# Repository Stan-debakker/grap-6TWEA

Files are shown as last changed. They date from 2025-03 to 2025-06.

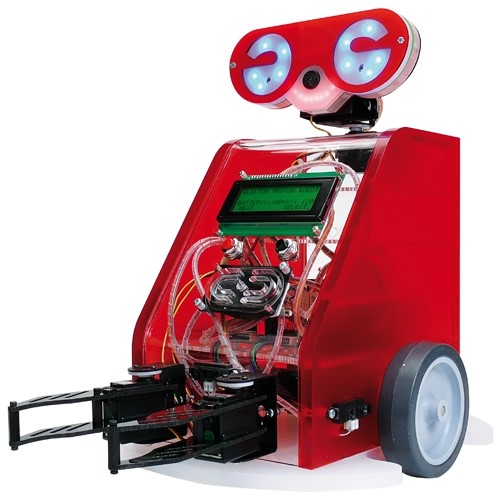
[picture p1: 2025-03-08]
school/foto robot/image1.jpeg

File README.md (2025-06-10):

# GRAP-6TWEA

## Doel
Het doel van dit project was om de verouderde **Elector Proton Robot** te moderniseren.  
Dit heb ik gedaan door het originele PCB (Printed Circuit Board) te vervangen. De nieuwe schema’s zijn te vinden in **"schematics"**.

Daarnaast moest ik ervoor zorgen dat de nieuwe sensoren correct werken.  
Ik ben gestart met experimenteren via Arduino IDE, zie **"code_arduinoIDE"**.

Op basis van deze experimenten heb ik een bibliotheek ontwikkeld om het gebruik te vereenvoudigen:

- **Versie 1** – **"liberary/robot"**: Voor Arduino, met de originele componenten aangesloten.
- **Versie 2** – **"liberary/robot_ESP_addon"**: Voor de ESP32-C6 met de bijbehorende uitbreiding.

## Schoolgerelateerde onderdelen
Omdat dit project deel uitmaakt van een schooltaak, heb ik ook bijbehorende documenten moeten aanmaken, zoals studies en presentaties.  
Deze zijn te vinden onder **"school"**.

Voor een ander vak moest ik een website maken, die grotendeels over dit project gaat. Er staat ook nog extra info over een ander project wat ik vorig jaar deet Asgard.
Je vindt de websitebestanden onder **"website"**.

## Extra experimenten
Tot slot heb ik geëxperimenteerd met communicatie tussen de ESP32 en een computer via Python.  
Door beperkingen op mijn schoollaptop lukte dit niet, en heb ik deze testen stopgezet. De bestanden vind je onder **"python"**.

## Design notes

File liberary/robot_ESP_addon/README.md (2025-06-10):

# robot
deze bibliotheek is voor de geüpgrade elector proton robot
## info
de pcb die ik gebruikt om te upgraden staan in 
[github](https://github.com/Stan-debakker/grap-6TWEA)

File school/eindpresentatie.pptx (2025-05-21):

## Graadsproef: oude robot modernizeren

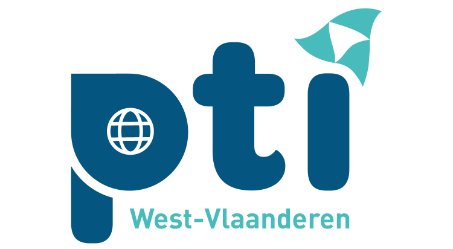
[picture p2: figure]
Afbeelding met Graphics, grafische vormgeving, Lettertype, logo Door AI gegenereerde inhoud is mogelijk onjuist.

Stan Debakker 6TWEA

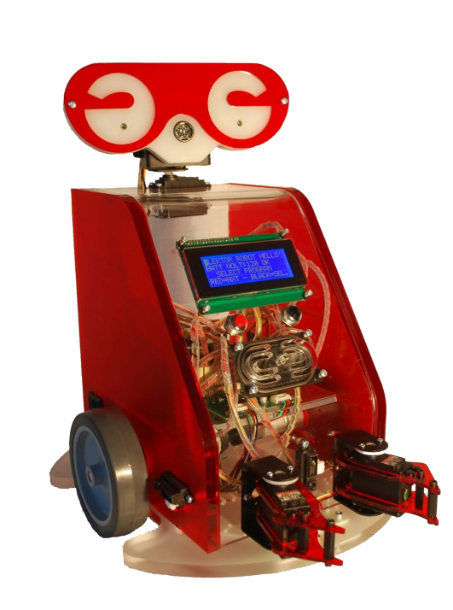
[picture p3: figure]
Afbeelding met machine, speelgoed, rood, automaat Door AI gegenereerde inhoud is mogelijk onjuist.

## Voorstelling van de robot

- Type: proton robot
- Productiedatum: 2011
- Producent: Elektor

## Onderdelen

Onderdelen die nog goed zijn, en behouden kunnen worden:
- LCD scherm
- IR afstandssensor
- Knoppen
- Motoren
- Ultrasone sensor
- Servomotoren

## onderdelen

Onderdelen die verouderd zijn, en daarom interessant om te vernieuwen:
- Lijnsensor (1→13 Chanels)(3→8 sensoren)
- (RGB) leds → adresseerbare RGB leds
- Microcontroller → microprocessor
- Muziekkaart
- DC-DC converters

## Microcontroler upgrade

- ESP32-C6
  - Wifi 6, BLE 5
- Extra
  - 3-as magnetometer
  - 3-as gyroscoop
  - 3-as accelerometer

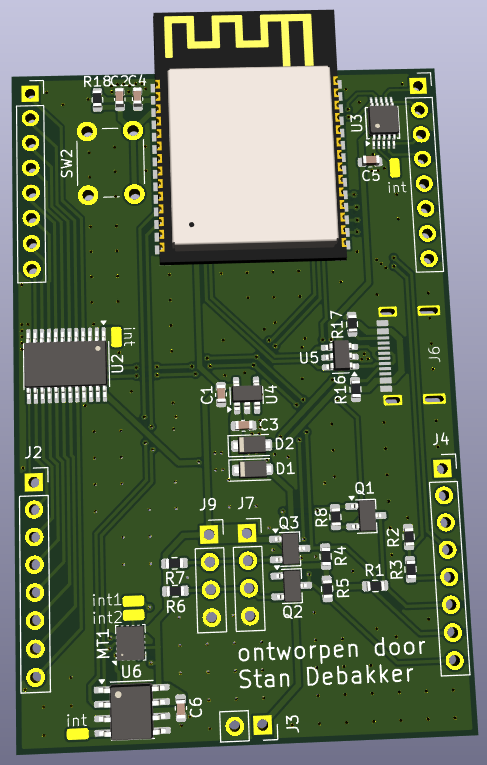
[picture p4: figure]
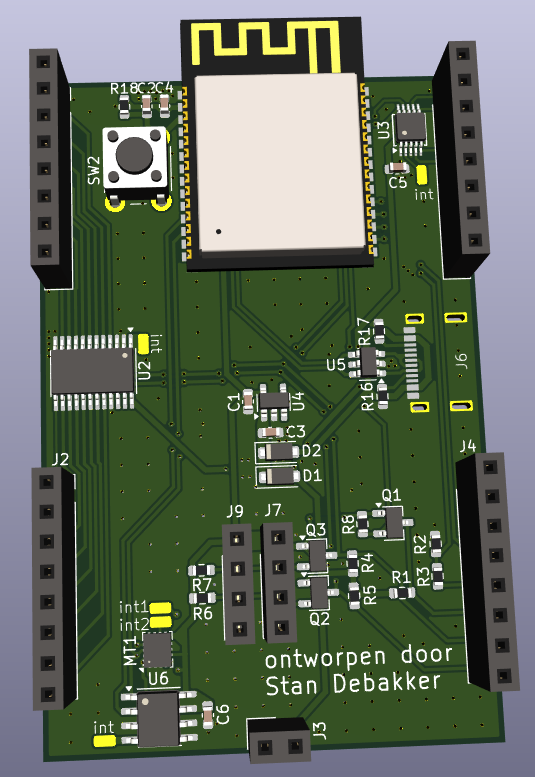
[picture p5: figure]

## Lijnsensor upgrade

- Van 1 naar 13 meetbare lichtbanden
- Van 3 naar 8 sensoren

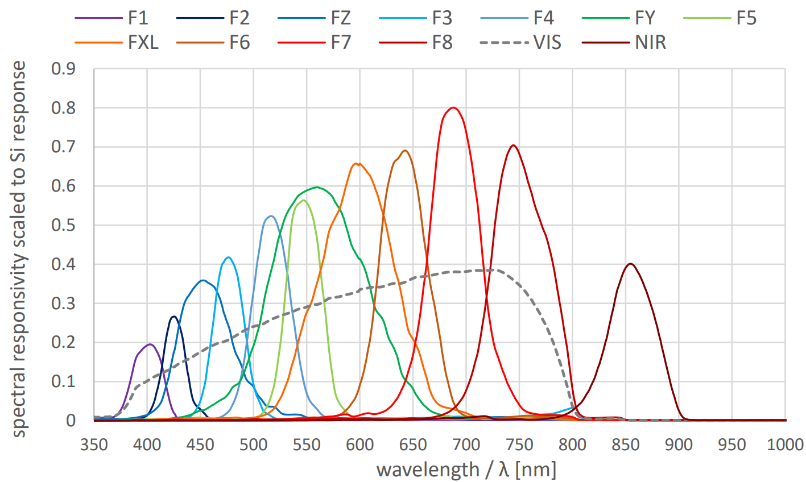
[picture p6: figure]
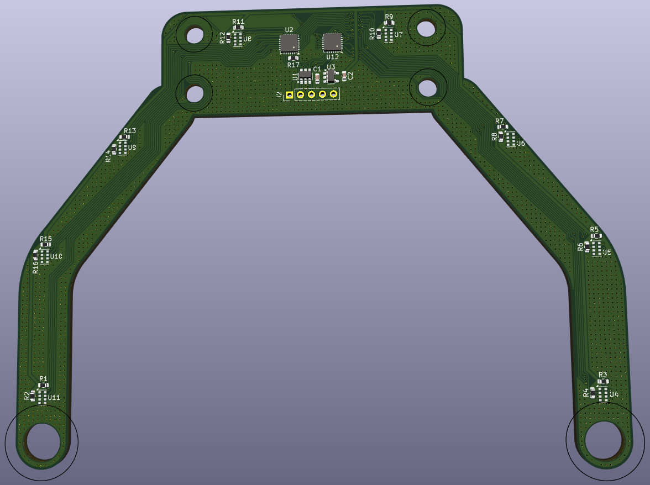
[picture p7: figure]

## hoofd

- Van 2 RGB led zones en 8 rode leds naar 18 RGB leds (onafhankelijk)
- Lichtsensor van 8 bit naar 12 bit (dynamisch bereik)

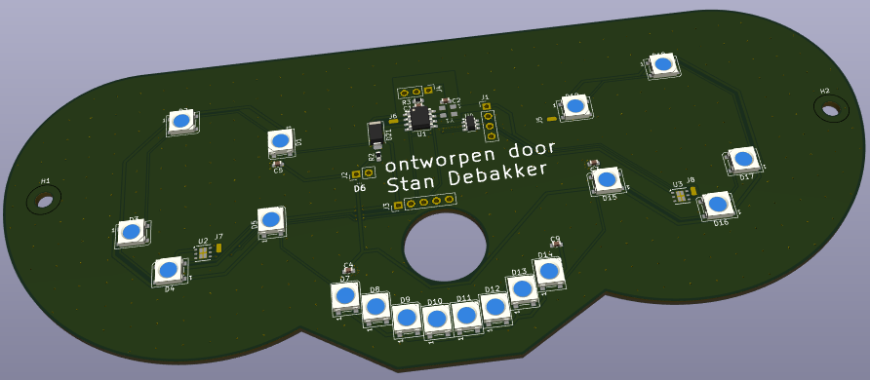
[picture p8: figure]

## methode

- Kicad
- Zelf aangeleerd

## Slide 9

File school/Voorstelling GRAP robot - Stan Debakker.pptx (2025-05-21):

## Programmeren van een robot, met een microcontroller

Graadproef
Stan Debakker
6 Technologische Wetenschappen en Engineering

## Elektor Proton Robot

- LCD-scherm
- 2 drukknoppen
- Grote wielen, aangestuurd door 2 DC-motoren
- Hoofd, bestuurd door 2 servomotoren
- 8 LED’s en een luidspreker
- Afstandssensoren
- Lichtsensoren
- Handjes, bestuurd door servomotoren

Grap Stan Debakker

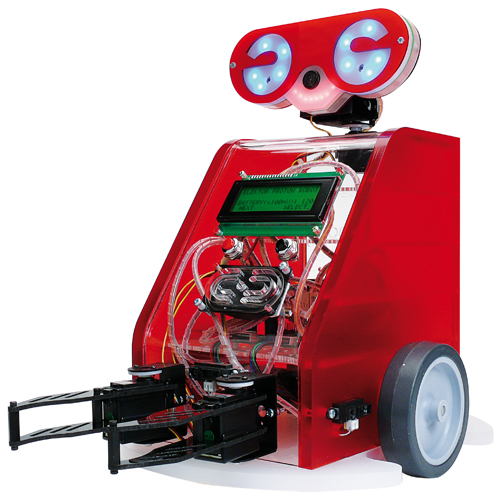
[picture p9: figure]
Elektor Proton Robot: a versatile platform for learning and experimenting | Elektor Magazine

## Besturing robot

- PIC16F887
- 8bit CMOS microcontroller
- 40-pin

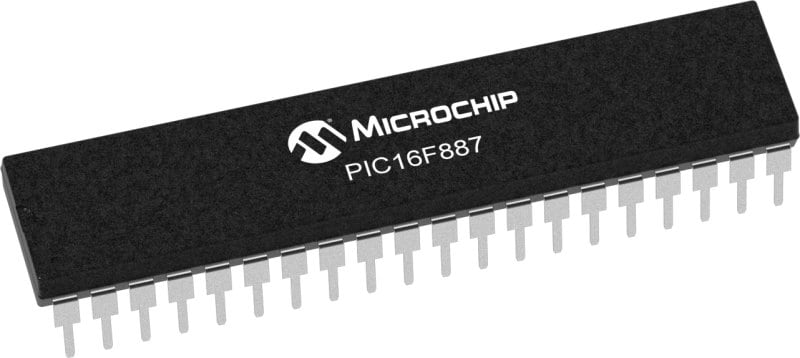
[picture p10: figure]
PIC16F887 | Microchip Technology
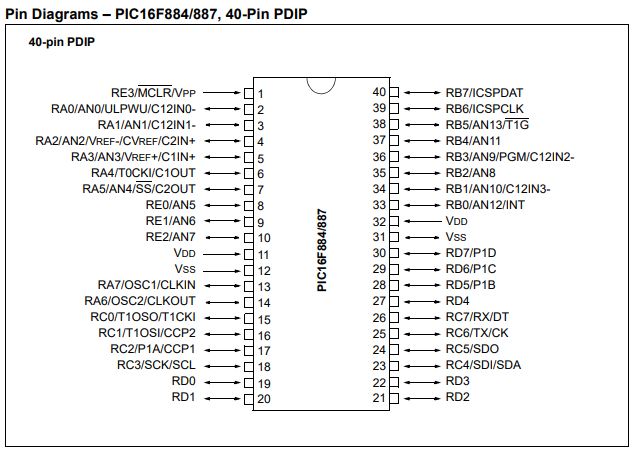
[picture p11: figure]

## Programmeertaal

- Nog te bestuderen wat mogelijk is, afhankelijk van de processor
  - C
  - C++
  - Flow code
  - …

## Doel

- Leren werken met een microcontroller
- Opstarten van de robot:
  - Laten rijden
  - Motoren aansturen
  - Aansturen LCD-scherm
- Indien nog tijd:
  - Uitwerken van een labo-oefening
  - Moderniseren

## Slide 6

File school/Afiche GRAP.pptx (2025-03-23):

## OUDE ROBOT MODERNISEREN

Stan Debakker – 6 TWEa

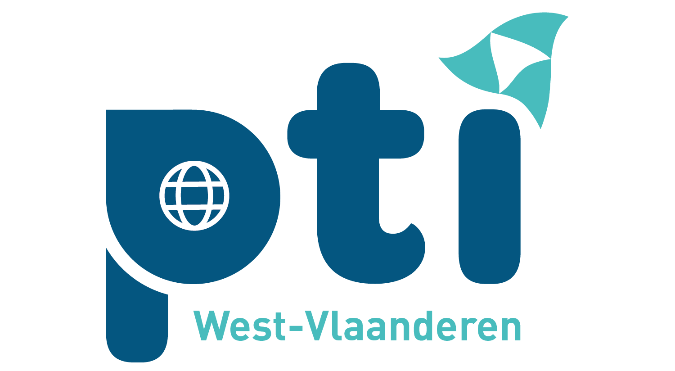
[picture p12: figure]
Afbeelding met Graphics, grafische vormgeving, Lettertype, logo Door AI gegenereerde inhoud is mogelijk onjuist.
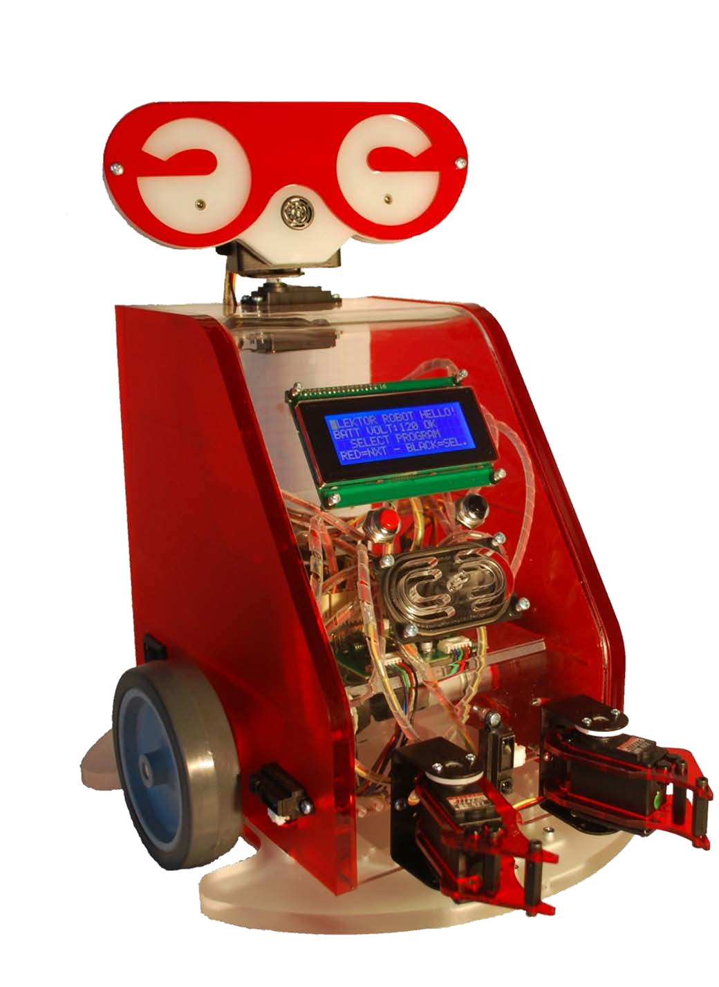
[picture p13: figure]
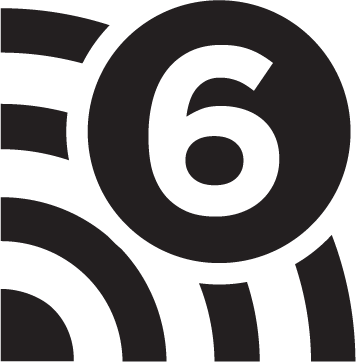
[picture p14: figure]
Afbeelding met cirkel, Graphics, zwart, schermopname Door AI gegenereerde inhoud is mogelijk onjuist.
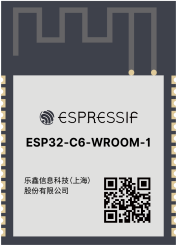
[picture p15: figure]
Afbeelding met tekst, schermopname, Rechthoek, Lettertype Door AI gegenereerde inhoud is mogelijk onjuist.
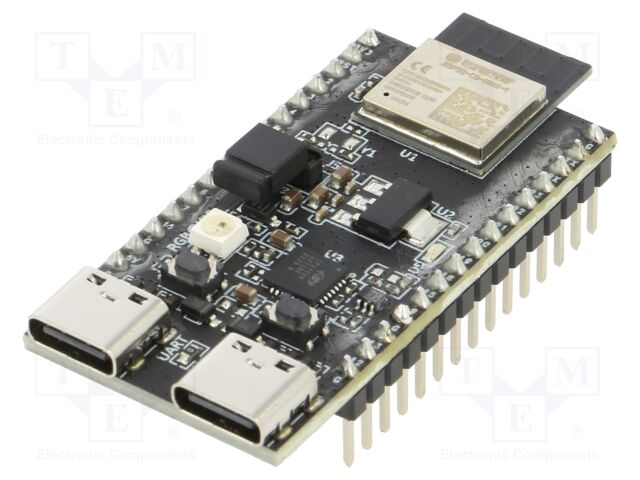
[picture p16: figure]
ESP32-C6-DEVKITM-1-N4 ESPRESSIF - Conjunto de arra: IoT | Comp: ESP32-C6-MINI-1-N4; 3,3VDC,5VDC; ESP32C6-DEVKITM1N4 | TME - Elektroniikka komponentit México

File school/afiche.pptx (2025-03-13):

## OUDE ROBOT MODERNIZEREN

Afbeelding met Graphics, grafische vormgeving, Lettertype, logo Door AI gegenereerde inhoud is mogelijk onjuist.

Stan Debakker – 6TWEA

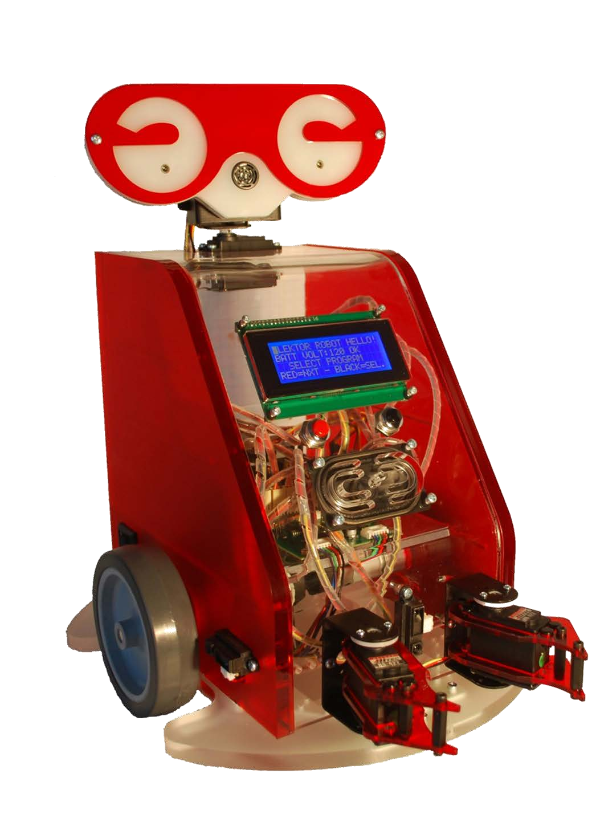
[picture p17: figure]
Afbeelding met cirkel, Graphics, zwart, schermopname Door AI gegenereerde inhoud is mogelijk onjuist.
Afbeelding met tekst, schermopname, Rechthoek, Lettertype Door AI gegenereerde inhoud is mogelijk onjuist.
ESP32-C6-DEVKITM-1-N4 ESPRESSIF - Conjunto de arra: IoT | Comp: ESP32-C6-MINI-1-N4; 3,3VDC,5VDC; ESP32C6-DEVKITM1N4 | TME - Elektroniikka komponentit México
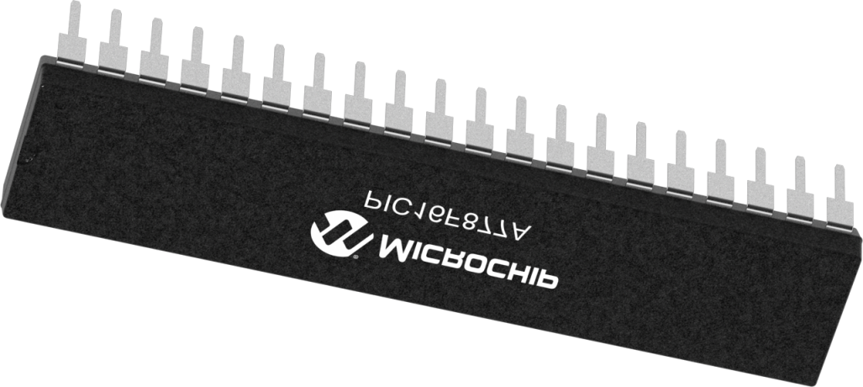
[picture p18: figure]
PIC16F877A-E/P

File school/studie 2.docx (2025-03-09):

GRAP: Modernisering robot

Studie 2


# 1 Inleiding

In de afgelopen decennia heeft de technologie een enorme vooruitgang geboekt, waarbij robots steeds slimmer, sneller en veelzijdiger zijn geworden. Veel oude robotmodellen die ooit baanbrekend waren, zijn inmiddels verouderd en niet meer in staat om te voldoen aan de eisen van moderne toepassingen.

Het moderniseren van een oude robot kan echter een interessante uitdaging bieden: het combineren van klassieke robottechnologie met de nieuwste innovaties.

In deze graadproef zal ik onderzoeken hoe een verouderde robot, zoals de Elektor Proton Robot, kan worden geüpdatet met hedendaagse technologieën, zoals geavanceerde sensoren, nieuwe besturingssystemen en verbeterde software. Door deze modernisering kan de robot zijn functionaliteit, efficiëntie en prestaties aanzienlijk verbeteren.

In studie 1 ben ik de bestaande onderdelen, mogelijkheden en de werking van de robot nagegaan. In deze studie 2 bekijk ik de opties om te moderniseren.

# 2 Upgrade van de robot

In dit hoofdstuk gaan we na wat de mogelijkheden zijn om de robot te verbeteren of te moderniseren. Dit doen we door ieder bord afzonderlijk te bekijken. Sommige borden doen alles goed, zoals de motoren, LCD-scherm. De servodriver werkt ook goed en wordt ook niet bekeken. Andere zoals de ADD-On, lijnsensoren, hoofdbord-muziekkaart bekijken we afzonderlijk.

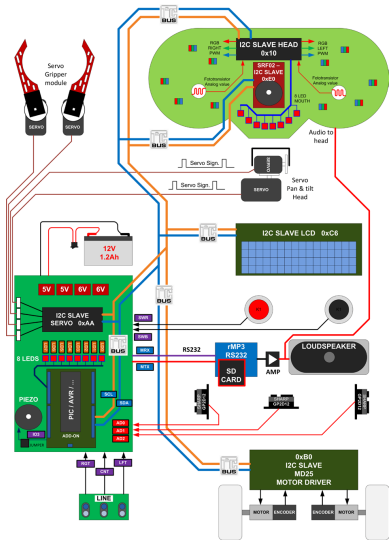
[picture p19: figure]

figuur: blokschema Elektor Proton Robot

## 2.1 ADD-ON

Hier gaan we dieper in op de onderdelen van de ADD-On kaart en welke verbeteringen, modernisering en toevoegingen er mogelijk zijn. Hiermee zorgen we voor een betere connectiviteit en maken we de robot toegankelijker voor toekomstige toepassingen.

### 2.1.1 Keuzes microcontroller

De microcontroller in de Elektor Proton Robot (en in veel andere robots) is het "brein" van de robot. Het regelt het besturen van de robot en verwerkt de gegevens van de sensoren. De microcontroller is een kleine computer die taken uitvoert in elektronische systemen. Het bestaat uit een processor, geheugen en invoer-/uitvoerapparaten om met de buitenwereld te communiceren.

Bij het moderniseren van de robot speelt de microcontroller een belangrijke rol. Hij bestuurt de oude hardware en maakt nieuwe functies mogelijk. Dankzij moderne microcontrollers kunnen zelfs eenvoudige robots slimmer en efficiënter worden door gebruik te maken van sensoren, motoren en communicatietechnologieën voor geavanceerdere toepassingen.

Bord | Voltage | I0 pins | ADC | | DAC | PWM | UART | I²C | I²S | SPI | Wifi | Bluetooth | Thread /zigbee
| | | Pins | Rezolutie
Arduino Giga | 5V | 76 | 12 | 10 | 2 | 12 | 4 | 3 | | 2
Arduino Mega | 5V | 54 | 16 | 10 | | 15 | 4 | 1 | | 1
Arduino Uno | 5V | 14 | 6 | 10 | | 6 | 1 | 1 | | 1
ESP32 C3 | 3.3V | 15 | 6 | 12 | | | 2 | 1 | 1 | 3 | 150Mbps | v5.0
ESP32 C5 | 3.3V | 22 | 6 | 12 | | | 3 | 2 | 1 | 1 | 150Mbps | v5.0 | ja
ESP32 C6 | 3.3V | 23 | 7 | 12 | | | 2+1 | 1+1 | | 1 | 150Mbps | v5.3 | ja
ESP32 C61 | 3.3V | 18 | 4 | 12 | | | 3 | 1 | 1 | 1 | 150Mbps | v5.0
ESP32 H2 | 3.3V | 19 | 5 | 12 | | | 2 | 2 | 1 | 3 | | v5.3 | ja
ESP32 mini1 | 3.3V | 28 | 18 | 12 | | | 3 | 2 | 2 | 4 | 150Mbps | v4.2
ESP32 pico mini | 3.3V | 27 | 18 | 12 | | | 3 | 2 | 2 | 4 | 150Mbps | v4.2
ESP32 pico v3 | 3.3V | 0 | 18 | 12 | | | 3 | 2 | 2 | 4 | 150Mbps | v4.2
ESP32 S2 | 3.3V | 37 | 20 | 12 | | | 2 | 2 | 1 | 4 | 150Mbps
ESP32 S3 | 3.3V | 36 | 20 | 12 | | | 3 | 2 | 2 | 4 | 150Mbps | v5.0
ESP32 WROOM 32E | 3.3V | 26 | 18 | 12 | | | 3 | 2 | 2 | 4 | 150Mbps | v4.2
ESP32 WROVER E | 3.3V | 24 | 18 | 12 | | | 3 | 2 | 2 | 4 | 150Mbps | v4.2
ESP8684 MINI 1 | 3.3V | 14 | 6 | 12 | | | 2 | 1 | | 3 | 72Mbps | v5.3
ESP8684 WROOM | 3.3V | 15 | 6 | 12 | | | 2 | 1 | 1 | 3 | 150Mbps | v5.0
Attiny | 5V | 4-28 | 0-28 | 10 | | | 0-1 | 0-1 | | 0-1

Tabel: vergelijking opties microcontrollers die met ArduinoIDE werken

Uit de tabel blijkt dat de ESP’s handig zijn, want ze hebben allemaal (behalve H2) wifi waardoor we kunnen communiceren en updaten via ArduinoOTA en IOT-Cloud.

Voor mijn project heb ik als microcontroller gekozen voor de ESP32-C6, aangezien deze microcontroller de meeste functionaliteiten biedt.

De ESP32-C5 en de ESP32-C6 hebben betere wifi (wifi 6), in vergelijking met de ESP32-S3 die maar wifi 4 heeft.

Een nadeel van de ESP32-C6 is echter dat deze minder extra I/O-pinnen heeft in vergelijking met de ESP32-S3 en de afwezigheid van ondersteuning voor I²S en CAN (TWAI), welke wel aanwezig zijn in de ESP32-C5 en ESP32-S3.

De rekenkracht van de ESP32-C6 is minder dan die van de ESP32-S3 wan niet erg is behalve als we beeldherkenning en AI willen gebruiken.

Helaas is de ESP32-C5 niet in productie gegaan, wat de keuze voor de ESP32-C6 noodzakelijk maakte. Een ander belangrijk aspect is dat de ESP32-C6, net als andere modellen uit de ESP32-serie, werkt op 3.3V in plaats van de gebruikelijke 5V die veel andere microcontrollers ondersteunen. Dit vormt een extra uitdaging, aangezien de robot waarvoor deze controller bedoeld is, oorspronkelijk was ontworpen voor 5V. Dit zorgt voor een aanpassing van zowel de power, databussen, analoge en digitale signalen.

#### 2.1.1.1 Power (ESP32)

Zoals in punt 2.1.1 aangehaald, heeft de ESP32-C6 dus een 3.3V voeding nodig. Ik heb gekozen voor TLV75733PDBVR. Deze is heel goedkoop (€0,275 per stuk) en kan ook max 1A aan. Dit is meer dan genoeg voor de ESP32 en mogelijks extra.

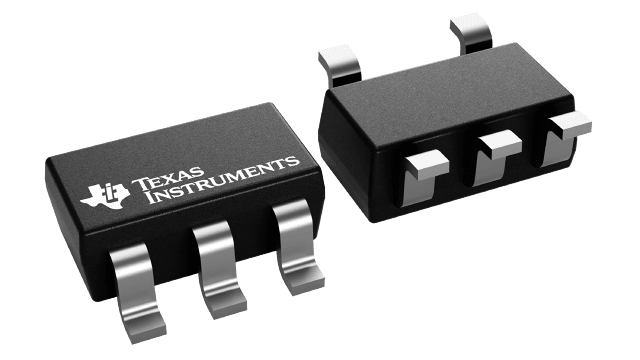
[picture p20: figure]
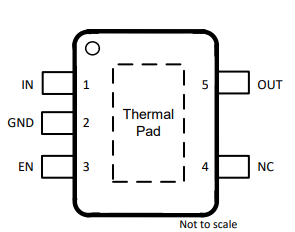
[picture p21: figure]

#### 2.1.1.2 Databussen

##### 2.1.1.2.1 Voltageomvormer voor I²C

Voor het correct functioneren van een I²C-communicatie tussen componenten met verschillende spanningsniveaus, is het noodzakelijk om een bidirectionele voltageomvormer te gebruiken. Deze omvormer zorgt ervoor dat de signalen tussen apparaten met verschillende spanningslogica (bijvoorbeeld 5V en 3,3V) probleemloos kunnen worden uitgewisseld.

Een bidirectionele voltageomvormer is relatief eenvoudig te realiseren. Voor elke datalijn zijn slechts twee weerstanden en een MOSFET nodig. Aangezien het I²C-protocol doorgaans gebruikmaakt van twee datalijnen, namelijk SCL (kloklijn) en SDA (datalijn), zijn er voor een volledige implementatie in totaal vier weerstanden en twee MOSFET's vereist. Sommige implementaties maken gebruik van een extra lijn, zoals een INT-lijn (interrupt), maar in dit project wordt deze niet gebruikt.

Hieronder leg ik kort de werking van een bidirectionele voltageomvormer uit:

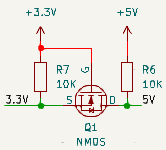
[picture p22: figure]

- De MOSFET fungeert als een schakelaar en zorgt ervoor dat signalen veilig kunnen worden overgebracht tussen de spanningsniveaus.
- De weerstanden stellen de juiste pull-up-waarden in, die essentieel zijn voor de werking van de I²C-bus.

Dit type schakeling is dus niet alleen kosteneffectief, maar ook praktisch en betrouwbaar voor het waarborgen van de compatibiliteit tussen apparaten met verschillende spanningslogica.

##### 2.1.1.2.2 UART-verbinding voor de muziekkaart

De robot beschikt ook over een UART (Universal Asynchronous Receiver-Transmitter) verbinding, die wordt gebruikt om te communiceren met de muziekkaart. Een UART-verbinding maakt gebruik van twee datalijnen:

- TX (transmit): om data te verzenden.
- RX (receive): om data te ontvangen.

Bij deze toepassing is het belangrijk om rekening te houden met de verschillende spanningsniveaus van de aangesloten componenten, namelijk 5V en 3,3V.

Hieronder leg ik de uni-directionele spanningsaanpassing voor de UART-datalijnen uit:

1. Datalijn RX van 5V naar 3,3V: Voor deze lijn is een eenvoudige spanningsdeler voldoende. Dit wordt gerealiseerd met twee weerstanden, waarbij één weerstand ongeveer het dubbele is van de andere. Door deze verhouding wordt de spanning op de lijn verlaagd naar een veilig niveau van 3,3V, zodat de muziekkaart correct kan functioneren zonder schade te veroorzaken.
2. Datalijn TX van 3,3V naar 5V: In theorie kan deze datalijn zonder enige spanningsomvorming worden gebruikt. De meeste 5V-componenten interpreteren een 3,3V-signaal correct als "hoog" (logische 1). Toch is het aan te raden om hier dezelfde spanningsomvormer te gebruiken als voor de I²C-datalijnen (want de uni directionele variant is complexer). Dit verhoogt de betrouwbaarheid van de verbinding en voorkomt mogelijke problemen bij compatibiliteit.

Door consequent dezelfde bidirectionele spanningsomvormer te gebruiken, zoals die bij de I²C-datalijnen, worden alle verbindingen uniform en betrouwbaar uitgevoerd. Dit draagt bij aan de stabiliteit en functionaliteit van het systeem.

#### 2.1.1.3 ADC (Analog to Digital Converter)

Bij het verwerken van analoge signalen zijn er twee belangrijke methoden om spanningsomzetting en signaalverwerking te realiseren. Beide methoden hebben hun voor- en nadelen, afhankelijk van de toepassing en de gewenste precisie.

##### 2.1.1.3.1 Spanningsverdeler

Een spanningsverdeler is een eenvoudige en goedkope oplossing voor het omzetten van hogere spanningen (bijvoorbeeld 5V) naar lagere spanningen (bijvoorbeeld 3,3V). Dit wordt gerealiseerd met behulp van twee weerstanden.

Voordelen:

- Eenvoudig te implementeren en kosteneffectief.
- Geschikt voor situaties waarin hoge nauwkeurigheid niet essentieel is.

Nadelen:

- Kleine vervormingen in het analoge signaal: door de eigenschappen van de spanningsverdeler kunnen er kleine afwijkingen in het signaal optreden, wat kan leiden tot onnauwkeurige metingen.
- Herkalibratie nodig: omdat de vervormingen variabel kunnen zijn, is het regelmatig nodig om de sensoren opnieuw te kalibreren.

Deze methode is de aanpak die wordt gebruikt voor de 5V naar 3.3V, maar in het geval van analoge signalen is de betrouwbaarheid lager door de gevoeligheid voor ruis en vervorming.

##### 2.1.1.3.2 Externe ADC

Een betere oplossing voor het verwerken van analoge signalen is het gebruik van een externe ADC (Analog-to-Digital Converter). Dit is een specifiek apparaat dat analoge signalen omzet naar digitale waarden met hoge precisie.

Voor dit project heb ik gekozen voor de ADS1115-Q1, een externe ADC met de volgende eigenschappen:

- 4 kanalen: hierdoor kunnen meerdere analoge signalen tegelijkertijd worden verwerkt.
- 16-bit resolutie: dit biedt een veel hogere precisie dan de ingebouwde ADC van de ESP32-C6, die slechts 12-bit is.
- Compatibiliteit met 5V: in tegenstelling tot de ADC van de ESP32-C6, kan de ADS1115 direct omgaan met analoge signalen van 5V zonder dat een spanningsverdeler nodig is.

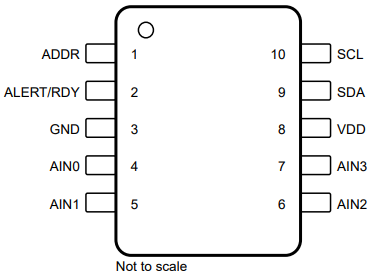
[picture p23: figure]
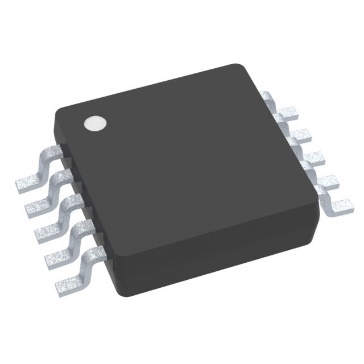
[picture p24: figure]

- Betrouwbaarheid: externe ADC's zoals de ADS1115 zijn minder gevoelig voor ruis en vervormingen, waardoor de meetresultaten consistenter zijn.
- Eenvoudige integratie: de ADS1115 communiceert via het I²C-protocol, waardoor het gemakkelijk te verbinden is met microcontrollers zoals de ESP32-C6.

#### 2.1.1.4 GPIO (General Purpose Input Output)

Vanwege het lagere voltage van de ESP32-C6 (3,3V) is het raadzaam om een externe module te gebruiken die compatibel is met hogere spanningen, zoals 5V. Dit voorkomt compatibiliteitsproblemen en zorgt voor een betere signaalintegriteit. Voor dit project is gekozen voor de PI4IOE5V6416, een krachtige I/O-uitbreidingsmodule.

De PI4IOE5V6416 biedt een scala aan functionaliteiten die ideaal zijn voor dit project. Hieronder volgen de belangrijkste eigenschappen:

##### 2.1.1.4.1 16 bestuurbare pinnen

De module biedt 16 GPIO-pinnen (General Purpose Input/Output) die afzonderlijk kunnen worden aangestuurd. Dit maakt het mogelijk om meerdere componenten en apparaten aan te sluiten, zoals sensoren, LED’s of andere externe modules.

##### 2.1.1.4.2 Ondersteuning voor Pull-Up/Pull-Down weerstanden

De module heeft ingebouwde ondersteuning voor pull-up en pull-down weerstanden. Dit betekent dat de gebruiker de toestand van de pinnen nauwkeurig kan instellen:

- Pull-up: zorgt ervoor dat een pin standaard naar een hoge spanning (bijvoorbeeld 5V) wordt getrokken.
- Pull-down: zorgt ervoor dat een pin standaard naar een lage spanning (bijvoorbeeld 0V) wordt getrokken.

Dit maakt het gemakkelijker om stabiele digitale signalen te verkrijgen zonder extra externe weerstanden toe te voegen.

##### 2.1.1.4.3 Ondersteuning voor interrupts

De PI4IOE5V6416 biedt de mogelijkheid om interrupts uit te sturen. Dit betekent dat de module een signaal naar de ESP32-C6 kan sturen wanneer een specifieke gebeurtenis plaatsvindt, zoals:

- Een verandering in de toestand van een pin (bijvoorbeeld een drukknop die wordt ingedrukt).
- Een signaal dat wordt ontvangen van een aangesloten apparaat.

Interrupts zijn belangrijk omdat ze de microcontroller in staat stellen om efficiënt te reageren op gebeurtenissen zonder constant elke pin te hoeven controleren (polling). Dit bespaart rekenkracht en verbetert de prestaties.

##### 2.1.1.4.4 Compatibiliteit met 5V

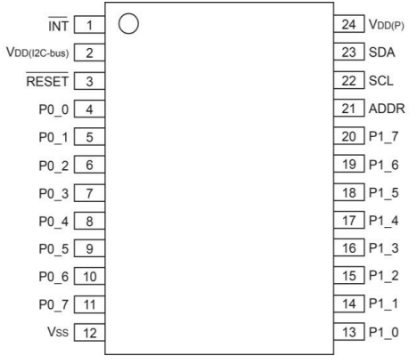
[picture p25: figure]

Een van de belangrijkste voordelen van de PI4IOE5V6416 is de compatibiliteit met een werkspanning van 5V. Hierdoor kan de module rechtstreeks worden gebruikt in systemen die een hogere spanning vereisen, zonder extra spanningsomzetting of aanpassingen.


### 2.1.2 Extra mogelijkheden voor localisatiebepaling.

In dit onderdeel onderzoek ik de mogelijkheid om de plaats van de robot te bepalen. We bekijken eerst hoe we de localisatie bepalen t.o.v. een startpunt met behulp van extra sensoren. Daarnaast bekijken we wat er mogelijk is met Wifi en GPS modules.

#### 2.1.2.1 Localisatiebepaling met behulp van extra sensoren

##### 2.1.2.1.1 Alles in één sensor

In eerste instantie onderzocht ik de BNO085. Dit is een sensor voor locatiebepaling, die een breed scala aan functies biedt, maar ook een relatief hoge prijs heeft (€10,99 voor één exemplaar, of €10,49 per stuk bij aankoop van 10 stuks). De BNO085 sensor beschikt over de volgende belangrijke componenten:

- Een 3-assige accelerometer
- Een 3-assig gyroscoop
- Een 3-assige magnetometer

##### 2.1.2.1.2 Alternatief

Gezien de relatief hoge prijs zocht ik naar alternatieven voor de BNO085 die samen minstens hetzelfde kunnen voor een lagere prijs.

- De MC3479 is een 3-assige accelerometer. Dit is een interessante keuze, met een prijs van €0,903 per stuk (€0,735 per stuk bij een aankoop van 10 stuks). Deze sensor heeft een resolutie van 16 bit en biedt verschillende maximale g-instellingen (±2, ±4, ±8, ±12, ±16) [m/(s^2)] .
- De ICM-42670 is een 3-assige accelerometer, 3-assig gyroscoop. Voor €2,77 per stuk (€2,30 per stuk bij een aankoop van 10 stuks). De ICM-42670 biedt een resolutie van 16 bit voor zowel de accelerometer als de gyroscoop. De accelerometer ondersteunt verschillende maximale g's (±2, ±4, ±8, ±16) [m/(s^2)] , terwijl de gyroscoop een resolutie van 16 bit heeft en verschillende dps (graden per seconde) instellingen biedt (±250, ±500, ±1000, ±2000) [(°)/s] .
- De MLC90395 is een 3-assige magnetometer. Met zijn I²C-ondersteuning en een prijs van €2,93 per stuk kan ook deze een interessante keuze zijn. De MLX90395 beschikt over een 16-bit magnetometer met een maximum van 130 mT in de Z-as en 55 mT (medium field variant) of 120 mT (high field variant) in het XY-vlak. Bovendien heeft de sensor een 16-bit voltmeter en een 14-bit thermometer, wat een extra functionaliteit biedt.

##### 2.1.2.1.3 Besluit sensoren localisatiebepaling

Ik heb gekozen voor de ICM-42670 en de MLX90395, aangezien deze sensoren meer functionaliteiten bieden dan de BNO085, tegen een lagere prijs. De ICM-42670 biedt zowel een accelerometer als een gyroscoop met een resolutie van 16 bit en meerdere g- en dps-instellingen, wat meer flexibiliteit biedt voor verschillende toepassingen. De MLX90395 voegt een 3-assige magnetometer toe met een hoge resolutie van 16 bit, samen met een voltmeter en thermometer. Dit maakt de combinatie van deze twee sensoren een voordelige keuze, aangezien ze meer functionaliteiten leveren en aanzienlijk goedkoper zijn dan de BNO085.

#### 2.1.2.2 Localisatiebepaling met wifi

De localisatiebepaling met behulp van Wifi is een mogelijkheid aangezien de ESP32 Wifi heeft. Dit kan in combinatie met de deep sleep functie van de ESP32 een interessante toevoeging zijn om de robot na een langere inactieve periode terug te vinden. Echter zijn hiervoor extra access points nodig. Gezien de onnauwkeurigheid en de nood om een netwerk op te stellen wordt dit niet verder bekeken. Indien dit in de toekomst toch nodig blijkt, kan dit makkelijk worden geïmplementeerd doordat de ESP32 wifi heeft.

#### 2.1.2.3 Localisatiebepaling met gps

Hiervoor moet er een extra gps module toegevoegd worden. De nauwkeurigheid is ook wel niet groot en de signalen worden makkelijk verstoord door gebouwen. Om deze redenen wordt dit niet verder bekeken.

## 2.2 Lijnsensoren

Momenteel heeft de lijnsensor een monocolor kleurherkenning. Hij kan enkel zwart en wit onderscheiden. Dit wil ik verbeteren door meerder kleuren te laten herkennen. Ook wil ik dan meerdere sensoren toevoegen waardoor complexere algoritmes mogelijk zijn.


### 2.2.1 Kleurherkenning mogelijk maken

Een andere mogelijke verbetering zou het vervangen van de lijnsensoren zijn door sensoren die meerdere kleuren kunnen onderscheiden. Dit zou de robot in staat stellen om complexere taken uit te voeren, zoals het volgen van een groene lijn gevolgd door een rode lijn.

Omdat er geen multicolor 5V lichtsensoren beschikbaar zijn, zijn voltageomvormers noodzakelijk. De AS734L lijkt de beste keuze voor dit doel, aangezien deze sensor een breed spectrum van licht kan meten, variërend van 405 nm (bijna onzichtbaar blauw) tot 855 nm (infrarood). Bovendien heeft de AS734L een werkspanning van slechts 1.8V, wat iets minder handig is, maar de voltageomvormers voor zowel de I²C-communicatie als de stroomvoorziening kunnen eenvoudig worden gedeeld door dezelfde reeks, namelijk de TLV75718PDYDR.

### 2.2.2 I²C multiplexen

Een belangrijk nadeel van bovenstaande is dat het vaak wenselijk is voor lijnsensoren om meerdere sensoren te gebruiken om een breder bereik te krijgen. De AS734L heeft echter slechts één sensor, wat betekent dat we multiplexing nodig hebben. Er zijn twee mogelijke opties voor I²C-multiplexers: de TCA9544 en de TCA9548. Het belangrijkste verschil is dat de TCA9544 vier I²C-lijnen kan splitsen, terwijl de TCA9548 acht I²C-lijnen kan splitsen. De TCA9544 ondersteunt bovendien de mogelijkheid om interruptus door te sturen, wat voor mijn toepassing minder relevant is (indrupt bij TLV75718PDYDR is niet handig). Daarom heb ik besloten de TCA9548 te gebruiken, aangezien deze acht I²C-lijnen kan splitsen.

Het voordeel van beide I²C-multiplexers is dat maximaal acht sensoren kunnen worden aangesloten door gebruik te maken van de adres bits A0, A1 en A2. Dit maakt de opstelling flexibel en uitbreid baar voor meerdere kleursensoren, wat de robuustheid van de robot aanzienlijk vergroot.

Als er nog tijd over is, zal ik de lijnsensoren verder uitwerken. Deze vernieuwing is leuk en heel handig, maar lijkt minder cruciaal.

## 2.3 Hoofd

Ook het hoofd van Proton robot kunnen we verbeteren met nieuwere componenten. Hieronder vind je alvast een opsomming van enkele ideeën.

### 2.3.1 LED’s

Ik overweeg om de huidige LED's in het hoofd van de robot te vervangen door adresseerbare LED's. Deze LED's hebben als groot voordeel dat ze individueel kunnen worden aangepast met slechts één enkele pin, in plaats van de drie PWM-pinnen per kleurgroep of één pin per LED-groep, waarbij elke groep altijd dezelfde staat heeft. Dit vereenvoudigt de hardware en biedt meer flexibiliteit in de bediening van de verlichting.

De meest voorkomende adresseerbare LED is de WS2812B, hoewel sommige vergelijkbare producten zelfs zeggen: "soortgelijk aan WS2812B". Deze LED's maken het mogelijk om elke LED in het hoofd afzonderlijk te besturen, wat verschillende visuele effecten en patronen mogelijk maakt. Dit kan bijvoorbeeld handig zijn voor het weergeven van statusindicatoren of om visuele feedback te geven in reactie op de omgeving of acties van de robot.

Door gebruik te maken van WS2812B LED's kunnen we de visuele presentatie van de robot aanzienlijk verbeteren, terwijl we tegelijkertijd de benodigde pinnen op de microcontroller verminderen (wat het ontwerp efficiënter maakt).

### 2.3.2 Lichtsenor

De huidige lichtsensor maakt gebruik van een 8-bit ADC (PIC in het hoofd), maar aangezien ik de LED's wil vervangen, zou het noodzakelijk zijn om een nieuwe PCB te maken. Dit maakt het aantrekkelijk om ook de lichtsensor te upgraden. De BH1750FVI lijkt een goede keuze, aangezien deze sensor een 16-bit nauwkeurigheid biedt en communiceert via I²C, wat de integratie vereenvoudigt. Echter, de BH1750FVI werkt alleen op 3.3V, wat een extra uitdaging vormt, aangezien de robot oorspronkelijk op 5V is ontworpen en de 3.3V nog niet tot aan het hoofd komt.

Er bestaan echter fotodiodes of fototransistors die wel op 5V kunnen werken, maar dit zou een extra ADC vereisen, evenals de nodige weerstanden en mogelijk een condensator. Dit zou het voordeel bieden dat er geen voltageomvorming nodig is, maar het zou wel extra componenten vereisen en de complexiteit van de schakeling verhogen.

Een andere optie is om de lichtsensor van de lijnsensoren te gebruiken. Dit kan echter leiden tot een conflict als de I²C-bus niet goed wordt geregeld, aangezien deze mogelijk wordt gedeeld met andere (door het enige adres van de sensor).

Als alternatief kunnen we overwegen om een microcontroller te gebruiken die beschikt over twee of drie onafhankelijke I²C-bussen, zoals beschreven in sectie 2.1.1, of nog andere microcontrollers te overwegen, maar dan kan de Arduino IDE niet gebruikt worden wat voor mij vervelend zou zijn. Dit zou de mogelijkheid bieden om meerdere I²C-apparaten tegelijk aan te sturen zonder conflicten, waardoor de integratie van meerdere sensoren, waaronder de nieuwe lichtsensor, eenvoudiger wordt. Deze aanpak kan de flexibiliteit van het ontwerp verhogen, maar vereist mogelijk een complexere implementatie van de software en hardware.

## 2.4 Camera

Een andere goede verbetering aan de robot zou kunnen zijn als die ook de functionaliteit krijgt om te zien. Er bestaat al een "ESP32-CAM" module die de OV2640 camera gebruikt, en het is zeker mogelijk om de ESP32-C6 te gebruiken om deze camera aan te sturen. De ESP32-C6 biedt genoeg kracht en connectiviteitsopties, wat het een geschikte keuze maakt voor algemene toepassingen.

Echter, als de robot taken moet uitvoeren die AI- of beeldverwerkingscapaciteiten vereisen, is de ESP32-S3 wellicht een betere keuze. De ESP32-S3 heeft namelijk verbeterde capaciteiten voor AI-toepassingen, en biedt betere prestaties voor beeldverwerkingstaken, waardoor het efficiënter kan omgaan met complexe berekeningen zoals gezichtsherkenning of objectdetectie.

Het kiezen van de juiste microcontroller hangt dus af van de specifieke vereisten van de robot, zoals de complexiteit van de beeldverwerking en AI-taken die uitgevoerd moeten worden.

## 2.5 Hoofdbord

Het hoofdbord is het centrale punt waar alle componenten op worden aangesloten of waar de signalen vandaan komen. Sommige onderdelen zijn inmiddels verouderd of zijn niet meer nodig door de ontwikkeling van nieuwe technologieën. Daarnaast zijn er verschillende aspecten die we kunnen verbeteren, zoals de volgende.

### 2.5.1 Power

Als ik het hoofdbord zou vervangen, zou ik overwegen om een efficiëntere DC-to-DC converter te gebruiken voor de belangrijkste (die het meeste stroom verbruiken) spanningen (12V en 5V). Het omzetten van 5V naar 3.3V met een LDO (Low Dropout Regulator) veroorzaakt relatief weinig verlies (het verlies in een LDO is de stroom maal het spanningsverschil tussen de invoer- en uitvoerspanning). Dit betekent dat als je begint met een 5V bron, het verlies bij het omzetten naar 3.3V minimaal is, wat de efficiëntie verbetert.

Echter, voor hogere stromen of wanneer de spanningsverschillen groter zijn, zou een DC-to-DC buck converter een betere keuze zijn. Buck converters kunnen veel efficiënter zijn bij grotere spanningsomzettingen (bijvoorbeeld van 12V naar 5V), aangezien ze de energie beter behouden in de vorm van hogere efficiëntie, vaak boven de 90%.

Samenvattend: als ik het hoofdbord zou vervangen, zou ik kiezen voor een combinatie van LDO-regelaars voor kleinere spanningsomzettingen (zoals 5V naar 3.3V want er is geen grote spanningsval en de stroom is ook lager beide verlagen het energieverlies) en DC-to-DC converters voor grotere omzettingen (zoals 12V naar 5V), om zo de efficiëntie en de energiebehoeften van de robot te optimaliseren.

### 2.5.2 Muziekkaart

Bij het vervangen van het hoofdbord ontstaat de mogelijkheid om een nieuwere muziekkaart te integreren. Dit biedt niet alleen verbeterde audiokwaliteit, maar ook de kans om gebruik te maken van geavanceerde communicatieprotocollen zoals I²S (Inter-IC Sound). Bijkomend, het communicatie protocol wordt simpeler in vergelijking met de huidige.

#### 2.5.2.1 Voordelen van I²S voor een muziekkaart

I²S is een speciaal protocol dat is ontworpen voor digitale audiocommunicatie. Het wordt vaak gebruikt in combinatie met moderne muziekkaarten en microcontrollers vanwege de efficiënte en nauwkeurige manier waarop het audiodata kan overbrengen.

1. Hoge geluidskwaliteit: I²S ondersteunt digitale audio-overdracht zonder de beperkingen van analoge signalen, zoals ruis en vervorming. Dit maakt het protocol ideaal voor hoogwaardige muziekkaarten.
2. Efficiëntie: Het protocol werkt met een eenvoudige set datalijnen, namelijk:
  - SD (Serial Data): voor het verzenden van audiogegevens.
  - WS (Word Select): om onderscheid te maken tussen het linker- en rechterkanaal (stereo).
  - SCK (Serial Clock): voor de timing van de gegevensoverdracht. Dit minimaliseert de complexiteit van de verbinding en maakt integratie eenvoudiger.
3. Flexibiliteit: Moderne muziekkaarten kunnen via I²S eenvoudig communiceren met microcontrollers zoals de ESP32 (behalve de ESP32-C6). Hierdoor is het mogelijk om audiogegevens efficiënt te verzenden en te verwerken.

#### 2.5.2.2 Integratie met ESP32

Als een ESP32 (bijvoorbeeld de ESP32-S3) wordt gebruikt, biedt dit extra mogelijkheden voor het beheer van de muziekkaart:

- ESP32 als audio-controller: de ESP32 kan audio naar de muziekkaart sturen via I²S, waarbij de microcontroller fungeert als een audio-bron (bijvoorbeeld muziekstreaming via Bluetooth of Wi-Fi).
- DSP-mogelijkheden (Digital Signal Processing): met behulp van de rekenkracht van de ESP32 kunnen audiobewerkingen plaatsvinden vóór de overdracht naar de muziekkaart, zoals het toepassen van equalizers of filters.

#### 2.5.2.3 Besluit

I²S is een logische keuze maar kan nu niet uitgewerkt worden omdat dit niet mogelijk is met de versie C6. Dit is de enige versie waar dit niet mogelijk is maar ik geef hier voorlopig nog de voorkeur aan omwille van de betere connectiviteit. Indien later een andere ESP32 gekozen wordt, bijvoorbeeld een versie S3 omwille van zijn grotere rekenkracht, is het te overwegen om dan de muziekkaart mee te integreren.

### 2.5.3 LED’S

De LED’s die zich op het hoofdbord bevinden, zijn niet geïntegreerd in het hoofd van de robot. Bij een mogelijke vervanging van het hoofdbord is het te overwegen om de debug LED’s aan te passen of zelfs volledig te verwijderen aangezien deze met de huidige tools minder relevant zijn. Er zijn verschillende opties die in aanmerking komen voor deze wijziging:

#### 2.5.3.1 Verwijderen of vervangen van huidige debug LED’s

Als het hoofdbord wordt vervangen, is het mogelijk om de huidige debug LED’s te verwijderen of te vervangen door LED’s die elders in het systeem zijn gebruikt, zoals die van LED’s (zie punt 2.3.1). Door een uniforme set LED’s te gebruiken, ontstaat een consistente uitstraling en functionaliteit in het gehele ontwerp.

Een voordeel van deze uniformiteit, is een vermindering van het aantal verschillende componenten, wat de onder houdbaarheid verbetert.

#### 2.5.3.2 Uitbreiden van indicator LED’s

De indicator LED’s, die belangrijke statusinformatie weergeven, zullen worden uitgebreid. Er worden extra indicator LED’s toegevoegd om de functionaliteit te verbeteren.

- Functies van Indicator LED’s:
  - Statusaanduiding: van bijvoorbeeld de voeding (de enige die er al zijn), verbindingen (I²C, I²S, UART), of foutmeldingen.
  - Gebruikersfeedback: zoals het tonen van de werking van sensoren, de werking van de muziekkaart, of de laadstatus van de batterij.
- Mogelijke Uitbreidingen:
  - Extra kleuren of RGB-LED’s om meer informatie visueel te communiceren.
  - Dynamische patronen (bijvoorbeeld knipperen of dimmen) om de status duidelijker te maken.

#### 2.5.3.3 Waarom LED’s aanpassen?

Door het vervangen van de LED’s of het aanpassen van hun functionaliteit, kan het ontwerp beter afgestemd worden op de noden van de gebruiker en het project:

- LED’s die niet essentieel zijn, kunnen worden verwijderd om het ontwerp te vereenvoudigen.
- Indicator LED’s zorgen ervoor dat belangrijke systeeminformatie zichtbaar blijft, wat vooral nuttig is bij het testen of bedienen van de robot.

# 3 Probleemoplossing

Hieronder bespreek ik de grote problemen die ik al ben tegengekomen bij deze studie, met de gevonden oplossing.

## 3.1 USB UART-brug

Ik heb nog maar eens een probleem ondervonden met een USB to UART-brug. Dit keer was het de "CP210n" die voor problemen zorgde. Er bestaan wel drivers voor, zelfs op Windows 11 maar je hebt er admin privilages voor nodig. Hierdoor maak ik gebruik van een externe FTDI-adapter die wel werkt.

## 3.2 Gebruik maken van native USB

De ESP32-C6 is uitgerust met een ingebouwde USB 2.0-connector (12 D-, 13 D+), maar tijdens mijn pogingen om een verbinding tot stand te brengen, ondervond ik problemen. Na nader onderzoek bleek de oorzaak te liggen in de instellingen van de Arduino IDE, waar ik de optie "Tools > USB CDC On Boot" niet had geactiveerd. Het inschakelen van deze instelling loste het probleem op en maakte de verbinding mogelijk. Dit biedt een aanzienlijk voordeel, vooral wanneer ik van plan ben om een bord te ontwikkelen voor gebruik in de Elector Proton Robot. In dat geval is slechts één enkele verbinding vereist, wat het ontwerp eenvoudiger en efficiënter maakt.

## 3.3 Kapotte batterij

Doordat de loodaccu van de oude robot te lang inactief was, is deze gedegradeerd en was er maar 0,428V in plaats van 12V. Nu gebruik ik een externe voeding via stopcontact, maar daardoor kan hij niet (ver) rijden wat moeilijk is om hem uitgebreid te testen voor lijnsensoren en localisatiebepaling.

## 3.4 Overleaf (LaTeX)

Tijdens het maken van deze en vorige studie gebruikte ik LaTeX (een taal om PDF te maken) in Overleaf (IDE: Integrated Development Environment) maar toen ik de laatste puntjes op de i wou zetten en aan de slag gaan met de feedback van vorige studie begon ik mij nog meer te ergeren aan Overleaf en daarom ben in overgestapt naar word. De reden waardoor ik dit heb gedaan is omdat ik 2 foto’s naast elkaar wou zetten maar dat lukte niet (dit was de finale reden).

# 4 Besluit

Ik heb inmiddels een duidelijk beeld van hoe ik de robot theoretisch kan moderniseren en hoop dit voor het einde van het jaar ook praktisch te realiseren. In deze graadproef heb ik de theoretische basis gelegd voor het moderniseren van de Proton robot, waarbij ik technologieën zoals de microcontroller, GPIO, ADC, UART en I²C protocol heb besproken. Deze vormen de basis voor de geplande updates, waarmee de robot in staat zal zijn om nieuwe sensoren aan te sturen en te communiceren met andere systemen. De voordelen zijn verbeterde prestaties, flexibiliteit en de mogelijkheid om de robot geschikt te maken voor moderne toepassingen.

De volgende stap is de praktische uitwerking, waarbij de hardware van de robot aangepast zal worden, nieuwe componenten geïntegreerd en de microcontroller geprogrammeerd moet worden om de gewenste functionaliteit te bereiken. Het grootste uitdagende moment zal zijn om de theoretische concepten om te zetten naar de praktijk, waarbij technische obstakels overwonnen moeten worden.

De komende fase zal zich richten op het implementeren en testen van de hardware-upgrades en het schrijven van de benodigde software om de robot operationeel te maken met de nieuwe technologieën. Ik wil graag samen met de leerkrachten bepalen welke verbeteringen ik verder zal uitwerken, zowel vanuit technisch oogpunt als om de robot werkbaar te maken voor andere leerlingen, zodat zij ermee verder kunnen werken.

# 5 Bibliografie

ams. (sd). AS7343L. Premstaetten, Stiermaken, oostenrijk. Opgehaald van https://www.mouser.com/datasheet/2/588/asset_pdf_25493217-3474412.pdf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

ATtiny microcontroller comparison chart. (sd). Opgehaald van Wikipedia: https://en.wikipedia.org/wiki/ATtiny_microcontroller_comparison_chart

Ceva. (sd). BNO08X Data Sheet. Opgehaald van https://www.mouser.be/datasheet/2/1480/BNO080_085_Datasheet-3196201.pdf

Diodes. (sd). Low-Voltage Translating 16-bit I2C-bus I/O Expander. Opgehaald van https://www.diodes.com/assets/Datasheets/PI4IOE5V6416.pdf

Electronics, Mouser. (sd). Mouser. Opgehaald van Mouser: https://www.mouser.be/

Elektor. (2011, april 3). Programming Manual Elektor Proton Robot. Opgehaald van https://e2cre8.be/wp-content/uploads/2015/12/Elektor-proton-robot-programming-guide-V1_1-.pdf

Invensense. (2021, april 15). Opgehaald van https://product.tdk.com/system/files/dam/doc/product/sensor/mortion-inertial/imu/data_sheet/ds-000451-icm-42670-p.pdf

Kingbright. (2024, oktober 24). APS3227SP1C-P22. Opgehaald van https://www.mouser.be/datasheet/2/216/APS3227SP1C_P22-1313967.pdf

Melexis. (2020, september 15). MLX90395 Triaxis® Magnetometer Node. Opgehaald van https://media.melexis.com/-/media/files/documents/datasheets/MLX90395-datasheet-melexis.pdf

Memsic. (sd). MC3479 3-Axis Accelerometer. Opgehaald van https://www.mouser.be/datasheet/2/821/20200827164636363-1900743.pdf

Omnivision. (sd). https://www.uctronics.com/download/cam_module/OV2640DS.pdf. Opgehaald van https://www.uctronics.com/download/cam_module/OV2640DS.pdf

ROHM. (sd). Digital 16bit Serial Output Type Ambient Light Sensor IC. Opgehaald van https://www.mouser.com/datasheet/2/348/bh1750fvi-e-186247.pdf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

Systems, Espressif. (sd). ESP Product Selector. Opgehaald van Espressif: https://products.espressif.com/#/product-selector?names=&filter=%7B%22Products%22%3A%5B%22Module%22%5D,%22Status%22%3A%5B%22Mass%20Production%22%5D%7D

Systems, Espressif. (sd). ESP32-C6-WROOM-1. Shanghai, Shanghai, China. Opgehaald van https://espressif.com/documentation/esp32-c6-wroom-1_wroom-1u_datasheet_en.pdf

Systems, Espressif. (sd). ESP32-S3-WROOM-1. Shanghai, Shanghai, China. Opgehaald van https://www.espressif.com/documentation/esp32-s3-wroom-1_wroom-1u_datasheet_en.pdf

Texas, Instruments. (sd). ADS111x-Q1 Automotive, Low-Power, I2C-Compatible, 860-SPS, 16-Bit ADCs. Dallas, Texas, VS. Opgehaald van https://www.ti.com/lit/ds/symlink/ads1115-q1.pdf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

Texas, Instruments. (sd). TLV757P 1A, Low IQ, Small-Size, Low-Dropout Regulator. Dallas, Texas, VS. Opgehaald van https://www.ti.com/lit/ds/symlink/tlv757p.pdf?ts=1737221852811&ref_url=https%253A%252F%252Fwww.mouser.de%252F

Worldsemi. (sd). WS2812B. Opgehaald van https://cdn-shop.adafruit.com/datasheets/WS2812B.pdf

Stan DebakkerPagina 1 van 2GRAP 6TWEA

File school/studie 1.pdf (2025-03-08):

# Studie 1

Stan Debakker

## Inhoudsopgave

1 inleiding | 3
2 LCD scherm | 3
3 IR afstandssensor | 4
4 Lijn sensor | 4
5 Knoppen | 5
6 Motoren | 5
7 Hoofd | 8
8 De servomotoren | 10
9 Muziekkaart | 12

1

10 Besluit | 28
11 Bibliografie | 29

2

## 1 inleiding

Hieronder volgt een korte beschrijving van de verschillende onderdelen van de Elektor Robot. Al deze onderdelen werden nagekeken op hun werking en getest dat alles nu correct functioneert. De juiste codes voor de respectievelijke componenten wordt bijgehouden in een bibliotheek. Dit voor later gebruik bij het verder uitwerken van de GRAP. Voor het programmeren en testen wordt gebruik gemaakt van een Arduino Mega. Via de usb-poort is het makkelijker programmeren en te testen.

## 2 LCD scherm

Het scherm werkt nu. Er stond eerst een verkeerd I²C adres, in de datasheet van de robot die ik vond, maar heb dit kunnen aanpassen.
De code in bibliotheek voor het LCD scherm is dus al in orde.
C++ code

1 #include <Arduino . h>
2 #include <Wire . h>
3 #include ”LCD. h”
4
5 #def ine LCD ADDR 0 x63
6
7 // z e t de c u r s o r p o s i e t i e=X+20Y
8 void s e t c u r s o r ( u i n t 8 t p o s i t i e ){
9 | Wire . b e gi nT r a n smi s si o n (LCD ADDR ) ;
10 | Wire . w ri t e ( 0 ) ;
11 | Wire . w ri t e ( 2 ) ;
12 | Wire . w ri t e ( p o s i t i e ) ;
13 | Wire . endT r an smi s si on ( ) ;
14 }
15 // w i s t h e t h e l e scherm
16 void c l e a r s c r e e n ( ) {
17 | Wire . b e gi nT r a n smi s si o n (LCD ADDR ) ;
18 | Wire . w ri t e ( 0 ) ;
19 | Wire . w ri t e ( 1 2 ) ;
20 | Wire . endT r an smi s si on ( ) ;
21 }
22 // z e t de b a c k l i g h t ( aan o f a f ) v o l g e n s v a i r a l b l e aan 23 void b a c kli g h t ( bool aan ){
24 | Wire . b e gi nT r a n smi s si o n (LCD ADDR ) ;
25 | Wire . w ri t e ( 0 ) ;
26 | Wire . w ri t e ( aan ? 1 9 : 2 0 ) ;
27 | Wire . endT r an smi s si on ( ) ;
28 }

3

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

## 3 IR afstandssensor

Ik heb een aantal metingen gedaan met de afstandssensoren. Er zijn 3 sensoren: rechts, center en links. In de tabel hieronder vind je de analoge waardes die gemeten heb:
afstand (cm) | 19 | 28,5 | 38 | 47,5 | 57 | 66,5 | 76
rechts (analog) | 240 | 160 | 120 | 80 | 70 | 50 | 40
center (analog) | 210 | 150 | 180 | 150 | 135 | 110 | 85
links (analog) | 235 | 185 | 135 | 105 | 80 | 70 | 60
Uit deze data en met behulp van geogebra en de datasheet ben ik tot de con-statatie gekomen dat l(A) = C1
A + C2 (in het Nederlands betekent dit de lengte in functie van de Analoge(0-1023) waarde)
De optimale waarden voor de sensoren zijn (r staat voor de correlatieco¨effici¨ent hoe dichter bij ±1 hoe beter):
C1 | | C2 | | r
rechts | 4286.8927 | 3.6032954 | 0.9909
center | 7894.2012 | −11.045445 | 0.8223
links | 2679.1287 | 12.849024 | 0.9831
We kunnen besluiten dat deze afstandssensoren werken, behalve dat de center sensor een probleem heeft rond 38cm.

## 4 Lijn sensor

De robot heeft 3 lijnsensoren.
Bij ongeveer 0V is de ondergrond wit, bij 5V is het zwart, en de rechtse sensor heeft een witte ondergrond 2V in plaats van 0V.
C++ code

1 #include <Arduino . h>

| | | | 4

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

## 5 Knoppen

| De robot heeft 2 NO (normaal open) knoppen.

## 6 Motoren

| De robot heeft 2 12V motoren met een I²C driver.
| De driver kan ook de stroom door de motoren en de spanning erover meten.
| Ook kan hij de posietie van de motoren.
| C++ code

1 #include <Wire . h>
2 #include <Arduino . h>
3 #include ”motor . h”
4
| 5

5 #def ine driver ADDR 0 x58
6
7 // h t t p s : / /www . r ob o t−e l e c t r o n i c s . co . uk /htm/md25i2c . htm 8 // g e t d a t a
9 | i n t 3 2 t g e t e n c o d e r 1 ( ) {
10 | return get 4byte command ( 0 x2 ) ;
11 | } i n t 3 2 t g e t e n c o d e r 2 ( ) {
12 | return get 4byte command ( 0 x6 ) ;
13 | }
14 | u i n t 8 t g e t s n e l h e i d 1 ( ) {
15 | return get 1byte command ( 0 x0 ) ;
16 | } u i n t 8 t g e t s n e l h e i d 2 ( ) {
17 | return get 1byte command ( 0 x1 ) ;
18 | } u i n t 8 t g e t v o l t ( ) {
19 | return get 1byte command ( 0xA ) ;
20 | } u i n t 8 t g e t s t r o om 1 ( ) {
21 | return get 1byte command ( 0xB ) ;
22 | } u i n t 8 t g e t s t r o om 2 ( ) {
23 | return get 1byte command ( 0xC ) ;
24 | } u i n t 8 t g e t v e r s n e l l i n g ( ) {
25 | return get 1byte command ( 0xE ) ;
26 | } u i n t 8 t get mode ( ) {
27 | return get 1byte command ( 0 xF ) ;
28 | }
29
30 | i n t 3 2 t get 4byte command ( u i n t 8 t command ){
31 | i n t 3 2 t data =0;
32 | Wire . b e gi nT r a n smi s si o n ( driver ADDR ) ;
33 | Wire . w ri t e (command ) ;
34 | Wire . endT r an smi s si on ( f a l s e ) ;
35 | Wire . requestFrom ( driver ADDR , 4 , true ) ;
36 | while (Wire . a v a i l a b l e ( ) ) {
37 | data=(data<<8)+Wire . re ad ( ) ;
38 | }
39 | return data ;
40 | }
41 | u i n t 8 t get 1byte command ( u i n t 8 t command ){
42 | u i n t 8 t data ;
43 | Wire . b e gi nT r a n smi s si o n ( driver ADDR ) ;
44 | Wire . w ri t e (command ) ;
45 | Wire . endT r an smi s si on ( f a l s e ) ;
46 | Wire . requestFrom ( driver ADDR , 1 , true ) ;
47 | while (Wire . a v a i l a b l e ( ) ) {
48 | data=Wire . re ad ( ) ;
49 | }
50 | return data ;
| 6

51 }
52 // s e n t commando ’ s
53 | void s e t a c c e l e r a t i o n ( u i n t 8 t v e r s n e l l i n g ){
54 | Wire . b e gi nT r a n smi s si o n ( driver ADDR ) ;
55 | Wire . w ri t e ( 1 4 ) ;
56 | Wire . w ri t e ( v e r s n e l l i n g ) ;
57 | Wire . endT r an smi s si on ( ) ;
58 | }
59 | void se t mode ( u i n t 8 t mode ){
60 | Wire . b e gi nT r a n smi s si o n ( driver ADDR ) ;
61 | Wire . w ri t e ( 1 5 ) ;
62 | Wire . w ri t e (mode ) ;
63 | Wire . endT r an smi s si on ( ) ;
64 | }
65 | void s e t r e g u l a t o r ( bool s e t t o ){
66 | Wire . b e gi nT r a n smi s si o n ( driver ADDR ) ;
67 | Wire . w ri t e ( 1 6 ) ;
68 | i f ( s e t t o ){
69 | Wire . w ri t e ( 0 x31 ) ;
70 | } e l s e {
71 | Wire . w ri t e ( 0 x30 ) ;
72 | }
73 | Wire . endT r an smi s si on ( ) ;
74 | }
75 | void s e t t i m e o u t ( bool s e t t o ){
76 | Wire . b e gi nT r a n smi s si o n ( driver ADDR ) ;
77 | Wire . w ri t e ( 1 6 ) ;
78 | i f ( s e t t o ){
79 | Wire . w ri t e ( 0 x33 ) ;
80 | } e l s e {
81 | Wire . w ri t e ( 0 x32 ) ;
82 | }
83 | Wire . endT r an smi s si on ( ) ;
84 | }
85 | void r e s e t e n c o d e r s ( ) {
86 | Wire . b e gi nT r a n smi s si o n ( driver ADDR ) ;
87 | Wire . w ri t e ( 1 6 ) ;
88 | Wire . w ri t e ( 0 x20 ) ;
89 | Wire . endT r an smi s si on ( ) ;
90 | }
91 | void s e t s n e l h e i d 1 ( i n t 8 t s n e l h e i d ){
92 | Wire . b e gi nT r a n smi s si o n ( driver ADDR ) ;
93 | Wire . w ri t e ( 0 ) ;
94 | Wire . w ri t e ( s n e l h e i d ) ;
95 | Wire . endT r an smi s si on ( ) ;
96 | }
| 7

97 | void s e t s n e l h e i d 2 ( i n t 8 t s n e l h e i d ){
98 | Wire . b e gi nT r a n smi s si o n ( driver ADDR ) ;
99 | Wire . w ri t e ( 1 ) ;
100 | Wire . w ri t e ( s n e l h e i d ) ;
101 | Wire . endT r an smi s si on ( ) ;
102 | }

## 7 Hoofd

### 7.1 hoofd driver

| In het hooft zit er in micro controler verbonden via I²C met de hooft prosessor.
| deze stuurt volgende zaken aan.
| C++ code

1 #include <Arduino . h>
2 #include <Wire . h>
3 #include ” hoo fd . h”
4
5 #def ine l i c h t s e n s o r L 0 6 #def ine l i c h t s e n s o r R 1 7 #def ine g e l u i d s s e n s o r 2 8
9 #def ine hoofd ADDR 0 x88
10
11 void set RGB LEDs ( bool r e c h t s , u i n t 8 t Rood , u i n t 8 t Groen , u i n t 8 t Blauw ){
12 | Wire . b e gi nT r a n smi s si o n ( hoofd ADDR ) ;
13 | i f ( r e c h t s ){
14 | Wire . w ri t e ( 4 ) ;
15 | Wire . w ri t e ( Rood ) ;
16 | Wire . w ri t e ( Groen ) ;
17 | Wire . w ri t e ( Blauw ) ;
18 | } e l s e {
19 | Wire . w ri t e ( 1 ) ;
20 | Wire . w ri t e ( Blauw ) ;
21 | Wire . w ri t e ( Groen ) ;
22 | Wire . w ri t e ( Rood ) ;
23 | }
24 | Wire . endT r an smi s si on ( ) ;
25 }
26 | u i n t 8 t g e t s e n s o r v a l u e ( u i n t 8 t s e n s o r ){
27 | Wire . b e gi nT r a n smi s si o n ( hoofd ADDR ) ;
28 | switch ( s e n s o r ){
29 | case l i c h t s e n s o r L :

8

30 | Wire . w ri t e ( 8 ) ;
31 | break ;
32 | case l i c h t s e n s o r R :
33 | Wire . w ri t e ( 9 ) ;
34 | break ;
35 | case g e l u i d s s e n s o r :
36 | Wire . w ri t e ( 1 0 ) ;
37 | de fau lt :
38 | Wire . endT r an smi s si on ( ) ;
39 | return 0 ;
40 | }
41 | Wire . endT r an smi s si on ( f a l s e ) ;
42 | u i n t 8 t data =0;
43 | Wire . requestFrom ( hoofd ADDR , 1 , true ) ;
44 | while (Wire . a v a i l a b l e ( ) ) {
45 | data=Wire . re ad ( ) ;
46 | }
47 | return data ;
48 }
49 void set LEDs ( u i n t 8 t LEDs){
50 | Wire . b e gi nT r a n smi s si o n ( hoofd ADDR ) ;
51 | Wire . w ri t e ( 7 ) ;
52 | Wire . w ri t e (LEDs ) ;
53 | Wire . endT r an smi s si on ( ) ;
54 }
55 void s e t g e v o e l i g h e i d ( u i n t 8 t g e v o e l i g h e i d ){
56 | Wire . b e gi nT r a n smi s si o n ( hoofd ADDR ) ;
57 | Wire . w ri t e ( 1 1 ) ;
58 | Wire . w ri t e ( g e v o e l i g h e i d ) ;
59 | Wire . endT r an smi s si on ( ) ;
60 }

### 7.1.1 RGB leds

Het hoofd heeft 2 sets van PWM (puls with modulation) gestuurde RGB (0-255 per kleur) leds.

### 7.1.2 Leds

Het hoofd heeft 8 leds die apart gestuurd kunnen worden.

### 7.1.3 Lichtsensor

Het hoofd heeft 2 lichtsensoren.

9

### 7.2 Ultrasone sensor

Het hoofd heeft een ultrasone sensor. C++ code

1 #include <Wire . h>
2 #include <Arduino . h>
3 #include ” U S a f s t a n d s s e n s o r . h” 4
5 #def ine US ADDR 0 x70
6
7 | u i n t 1 6 t U S a f s t a n d s s e n s o r ( ) {
8 | u i n t 1 6 t data ;
9 | Wire . b e gi nT r a n smi s si o n (US ADDR ) ;
10 | Wire . w ri t e ( 0 ) ;
11 | Wire . w ri t e ( 0 x51 ) ;
12 | Wire . endT r an smi s si on ( ) ;
13 | d el a y ( 7 0 ) ;
14 | Wire . b e gi nT r a n smi s si o n (US ADDR ) ;
15 | Wire . w ri t e ( 2 ) ;
16 | Wire . endT r an smi s si on ( f a l s e ) ;
17 | Wire . requestFrom (US ADDR, 2 ) ;
18 | while (Wire . a v a i l a b l e ( ) ) {
19 | data=data <<8;
20 | data+=Wire . re ad ( ) ;
21 | }
22 | return data ;
23 }

## 8 De servomotoren

| De robot heeft 4 servomotoren. 2 voor de ”handjes” en 2 om het hoofd te be-
| sturen.
| De beide ”handjes” zijn apart bestuurbaar tussen 0= volledig rechts en 255=
| links.
| De eerste motor bedient het hoofd horizontaal: 0 volledig links en 255 rechts
| horizontaal.
| De tweede motor bedient het hoofd verticaal, hierbij is 0 volledig naar beneden
| en 255 volledig omhoog.
| C++ code

1 #include <Wire . h>
2 #include <Arduino . h>
3 #include ” s e r v o . h”

10

4
5 #def ine Servo ADDR 0 x55
6
7 void i n i t s e r v o ( u i n t 8 t mode ){
8 | Wire . b e gi nT r a n smi s si o n ( Servo ADDR ) ;
9 | Wire . w ri t e ( 0 ) ;
10 | Wire . w ri t e (mode ) ;
11 | Wire . endT r an smi s si on ( ) ;
12 }
13 bool s e t p o s ( u i n t 8 t se r v o , u i n t 8 t p o s i e t i e ){
14 | Wire . b e gi nT r a n smi s si o n ( Servo ADDR ) ;
15 | switch ( s e r v o ){
16 | case H o o f t h o r i z o n t a a l :
17 | Wire . w ri t e ( 1 ) ;
18 | break ;
19 | case H o o f t v e r t i k a a l :
20 | Wire . w ri t e ( 2 ) ;
21 | break ;
22 | case Grip L :
23 | Wire . w ri t e ( 3 ) ;
24 | break ;
25 | case Grip R :
26 | Wire . w ri t e ( 4 ) ;
27 | break ;
28 | de fau lt :
29 | Wire . endT r an smi s si on ( ) ;
30 | return f a l s e ;
31 | }
32 | Wire . w ri t e ( p o s i e t i e ) ;
33 | Wire . endT r an smi s si on ( ) ;
34 | return true ;
35 }
36 bool s e t o f s e t ( u i n t 8 t se r v o , u i n t 8 t o f s e t ){
37 | Wire . b e gi nT r a n smi s si o n ( Servo ADDR ) ;
38 | switch ( s e r v o ){
39 | case H o o f t h o r i z o n t a a l :
40 | Wire . w ri t e ( 5 ) ;
41 | break ;
42 | case H o o f t v e r t i k a a l :
43 | Wire . w ri t e ( 6 ) ;
44 | break ;
45 | case Grip L :
46 | Wire . w ri t e ( 7 ) ;
47 | break ;
48 | case Grip R :
49 | Wire . w ri t e ( 8 ) ;
| 11

50 | break ;
51 | de fau lt :
52 | Wire . endT r an smi s si on ( ) ;
53 | return f a l s e ;
54 | }
55 | Wire . w ri t e ( o f s e t ) ;
56 | Wire . endT r an smi s si on ( ) ;
57 | return true ;
58 }

## 9 Muziekkaart

de tijdelijke code (nog niet alles is getest wegens een te grote SD kaart of om-gezet in code)

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

12

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

14

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

15

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

16

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

17

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

306 | send command ( ’E ’ , ’ \n ’ , file c omm and s ) ;
307 | i f ( p e e k c h a r ()== ’E ’ ){
308 | data . e r r o r= g e t r e t u r n e r r o r ( ) ;
309 | } e l s e {
310 | data . h u i d i g e p o s i t i e= get nummer (DEC) ;
311 | data . g r o t e= get nummer (DEC) ;
312 | }
313
314 | }
315 | u i n t 8 t jump ( u i n t 3 2 t addr ){
316 | char data [ 1 1 ] ;
317 | s p r i n t f ( data , ”%d\n” , addr ) ;
318 | send command ( ’ J ’ , data , file c omm and s ) ;
319 | return | g e t r e t u r n e r r o r ( ) ;
320 | }
321 | u i n t 8 t jump end ( ) {
322 | send command ( ’ J ’ , ”E\n” , file c omm and s ) ;
323 | return | g e t r e t u r n e r r o r ( ) ;
324 | }
325 | u i n t 8 t change name ( char∗ path , char∗ old name , char∗ new name ){
326 | char data [4+2∗ s i z e o f ( path)+s i z e o f ( old name )+s i z e o f ( new name ) ] ;
327 | s p r i n t f ( data , ”%s/%s %s/%s ” )
328 | }
329 // p r i v a t e f u n c t i o n s
330 | bool | a v a i l a b l e ( ) {
331 | return S e r i a l 1 . a v a i l a b l e ( ) ;
332 | }
333 | char | p e e k c h a r ( ) {
334 | while ( ! a v a i l a b l e ( ) ) { }
335 | return S e r i a l 1 . peek ( ) ;
336 | }
337 | char | r e a d c h a r ( ) {
338 | while ( ! a v a i l a b l e ( ) ) { }
339 | return S e r i a l 1 . re ad ( ) ;
340 | }
341 | void | w r i t e c h a r ( char data ){
342 | S e r i a l 1 . w ri t e ( data ) ;
343 | }
344 | void | send command ( char i n s t e l l i n g , char∗ opperands , u i n t 8 t comando ){
345 | switch ( comando ){
346 | case s e t t i n g s :
347 | w r i t e c h a r ( ’ S ’ ) ;
348 | w r i t e c h a r ( ’T ’ ) ;
349 | break ;
350 | case playback commands :
351 | w r i t e c h a r ( ’P ’ ) ;

19

352 | w r i t e c h a r ( ’C ’ ) ;
353 | break ;
354 | case file c omm and s :
355 | w r i t e c h a r ( ’F ’ ) ;
356 | w r i t e c h a r ( ’C ’ ) ;
357 | break ;
358 | }
359 | w r i t e c h a r ( i n s t e l l i n g ) ;
360 | while (∗ opperands != ’ \n ’ ){
361 | w r i t e c h a r (∗ opperands ) ;
362 | }
363 | w r i t e c h a r ( ’ \ r ’ ) ;
364 | }
365 | u i n t 8 t | g e t r e t u r n e r r o r ( ) {
366 | char c ;
367 | while ( true ){
368 | c= r e a d c h a r ( ) ;
369 | i f ( c==’> ’ ){
370 | return 0 ; // a l l e s goed
371 | } e l s e i f ( c==’E ’ ){
372 | return | get nummer (HEX) ;
373 | } e l s e i f ( c==’ ’ ){
374 | while ( a v a i l a b l e ( ) ) | r e a d c h a r ( ) ; | // d a t a ( c l e a r de b u f f e r )
375 | return 0 ; // a l l e s goed
376 | }
377 | }
378 | }
379 | i n t 3 2 t | get nummer ( u i n t 8 t b a se ){
380 | bool n e g a t i e f=f a l s e ;
381 | char c ;
382 | i n t 3 2 t g e t a l ;
383 | c= r e a d c h a r ( ) ;
384 | i f ( c==’− ’ ){
385 | n e g a t i e f=true ;
386 | c= r e a d c h a r ( ) ;
387 | }
388 | while ( i s H e x a d e cim alDi gi t ( c ) ) {
389 | i f ( i s D i g i t ( c ) ) {
390 | c−=’ 0 ’ ; //maar e r een g e t a l van
391 | } e l s e i f ( i sLowe rCa se ( c ) ) {
392 | c−=’ a ’ ; //maak e r een g e t a l van
393 | } e l s e {
394 | c−=’A ’ ; //maak e r een g e t a l van
395 | }
396 | i f ( c>=b a se ){
397 | break ;

20

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

### 9.1 Versie (Version)

| print V≪cr≫
| geeft de versie van de kaart
| formaat: mmm.nn[-bxxx]≪sp≫SN:RMP1-sss. . . sss
| mmm: grote updates
| nn: kleindere updates
| xxx: beta update (indien het beta is)
| sss. . . sss: serie nummer
| mijn versie: 100.01 SN:RMP1-OEM

### 9.2 Instellingen (SeTtings)

| ieder commando begint met ST[instelling][parameter(optioneel)]≪cr≫
| 9.2.1 EOL als
| instelling:’E’
| parameter:0(EOL word ≪cr≫) 1(EOL word ≪lf≫) 2(EOL word ≪cr≫≪lf≫)
| 9.2.2 Schrijf timeout
| instelling:’T’
| parapeter:0-254
| als 0(wacht onijnig) ander waarde * 10ms
| 9.2.3 List mode
| instelling:’L’
| parameter:0-1
| 9.2.4 Bitrate
| instelling:’D’
| parameter:0-8

21

index | bitrate (b/s)
0 | 9600
1 | 19200
2 | 38400
3 | 57600
4 | 115200
5 | 2400
6 | 4800
7 | 230400
8 | 460800

22

### 9.2.5 Commando’s die ik niet gebruik

Hardware Bussy .
instelling:’H’
parameter:0,1
0: incatief
1: actief (set ”D”hoog als er iets is aan het spelen) ”D¨ıs niet verbonden dus dit comando doet niets

input style .
instelling:’S’
parameter:0,1,2
0 | ”no input style (imput interface ignored)”
1 | ”8 button/Switch interdace”
2 | ”7 Bit plus Trigger interface”

prompt character .
instelling:’P’
parameter:0-255
zet het caracter op het einde de transmissie
default ’>’ of 62

### 9.3 Speel commando’s (Play Commands)

ieder commando begint met PC[instelling][parameter(s) (optioneel)]≪cr≫

### 9.3.1 Speel bestand

instelling:’F’
parameter:[path]
speel het bestand met path:[path]

### 9.3.2 Volume

instelling:’V’
parameter:”[rechts]≪sp≫[links]” of [algemeen] of niets
algemeen: zet het volume voor links en rechts
rechts,links:0-255 geluid hoe groter het nummer hoe stiller (255 geen geluid) niets: de huidige instelling terug
rechts is het geluid dat uit de speaker komt

### 9.3.3 Herhaal

instelling:’O’
parameter:0-255 aantal keer je iets wil herhalen (0: oneindig aantal keer)

23

### 9.3.4 Jump

instelling:’J’
parameter: naar waar je wil gaan (tijd)

### 9.3.5 Versnellen

instelling:’X’
parameter:90-250 het percentage dat je wil dat de geluidsopname word afspeelt

### 9.3.6 Speel toon

instelling:’T’
parameter:0-255 (”base frequentie index”*32+d) met 1 ≤ d < 32 en 1 ≤”base frequentie index”< 8
base frequentie index | frequentie (Hz)
0 | 334,53125
1 | 375
2 | 25
3 | 172,265625
4 | 187,5
5 | 125
6 | 86,328125
7 | 93,75
de frequentie die word gespeeld=base frequentie · d

### 9.3.7 Boost

instelling:’B’
parameter:0-65535 ((treble amplitude · 4096) + (treble freuentie index · 256) + (bass amplitude · 16) + (bass frequentie index))
treble frequentie index (0-15) = treble frequentie / 1000
bass frequentie index (0-15) = bass frequentie / 10
amplidude (-8 tot 7)(gebruik de binaire waarde van het 2 complement)
de code die dit uitvoert

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

### 9.3.8 Simple comandos

geen parameter
geen return
pauze: ’P’
stop: ’S’
reset: ’R’

24

### 9.3.9 Spectrum analysator

instelling:’Y’
dit werkt niet

### 9.4 Bestands commando’s (File Commands)

ieder commando begint met FC[instelling][parameter(s) (optioneel)]≪cr≫

### 9.4.1 Sluit bestand

instelling:’C’
parameters: (geen sluit alles) of (een specifiek bestand 1-4)

### 9.4.2 Tijd wijzigen

instelling: ’D’
parameters: (jaar 4 digit)≪sp≫(maand 1-12)≪sp≫(dag 1-31)≪sp≫(uur 0-23)≪sp≫(mi-nutien 0-59)≪sp≫(seconden 0-59)≪sp≫(path(van het bestand))

### 9.4.3 Wissen

instelling:’E’
parameters:(path van het bestand of de map (moet leeg zijn voor je het kan verwijderen))

### 9.4.4 Bestand verwerker

instelling:’F’
parameter:geen
return: volgende beschikbare slot terug indien geen stuurt hij een error(E03>)

### 9.4.5 Bestand info

instelling:’E’
parameter:(bestand slot 1-4) return:(huidige positie)/(grote)

### 9.4.6 Jump

instelling:’J’
parameters:(bestand slot 1-4)≪sp≫(E:einde of addr)

### 9.4.7 Kaart info

instructie:’K’
parameter: geen of ’B’ of ’I’
geen: stuurt ”CSD”(16 bytes) en ”CID”(16 bytes) ”raw”door (niet ascii)

25

’B’: stuurt ”CSD”(16 bytes) en ”CID”(16 bytes) ascii HEX door
’I’: stuurt kaart type (1:MMC,2:SD V1,4:SDV2,12:SDHC) en stuurt ”CSD”, ”CID”, ”OCR”door ascii HEX door met de naam: gescheiden

### 9.4.8 Lijst bestanden

instelling:’L’
parameters:(geen,’C’,’S’,’I’)≪sp≫(path of patroon)
geen: als ”L”setting=0 grote bestand, als ”L”setting=1 aanmaakdatum
’C’: aantal bestanden dat in het path of patroon zit
’S’: geeft alles wat er in de map zit alleen maar een path te gebruiken, geen patroon
’I’: gaat over alles wat kan in het patroon (je moet er wel over lopen, als er geen meer zijn krijg je ”E07” oftewel einde bestand)

### 9.4.9 Maak map

instelling:’M’
parameters:(path naar de map)

### 9.4.10 Verander naam

instelling:’N’
parameters:(oude path naam)—(nieuwe path naam)

### 9.4.11 Open

instelling:’O’
parameters:(bestand verwerker) (mode: ’R’,’W’,’A’,RW’) (path)
mode: ’R’ allen lezen(path moet al bestaan), ’W’ alleen schrijven (path mag nog niet bestaan), ’RW’/’A’ schrijven en lezen (path moet nog niet bestaan) (’RW’ start in het beging,’A’ start op het einde)

### 9.4.12 Volume gebruik

instelling:’Q’
parameters: geen of ’A’
(als ’A’ stuurt FAT(type::”12”,”16”,”32”)≪cr≫) (vrije ruimte)/(totale ruimte)

### 9.4.13 Lees

instelling:’R’
parameters:(bestand verwerker) (optioneel aantal bytes worden gelezen max
512) (indien aatal bytes is ingegeven, het start adders)

26

### 9.4.14 Lees lijn

instelling:”RL”
parameters: hetzelfde als lees
stopt als hij een EOL (end of line) tegen komt

### 9.4.15 Trunkeren

instelling:’U’
parameters:(bestand verwerker) verwijdert alles achter de huidige positie

### 9.4.16 Schrijf

instelling:’W’
parameters:(bestand verwerker) (optioneel aantal bytes dat wordt geschreven max 512)

### 9.4.17 Schrijf lijn

instelling:’WL’
parameters: hetzelfde als schrijf
op het einde van de schrijf operatie wordt er een EOL (end of line) geschreven

### 9.4.18 Bestand status

instelling:’Z’
parameters: (optioneel bestand verwerker) indien alles goed return:≪sp≫ anders error

27

### 9.5 Errors

code | beschrijving
EO2 | commando te lang
E03 | bestandsverwerker vol
E04 | ongekend commando
E05 | kaart initialisatie error
E06 | commando slecht geformateerd
E07 | end of file (EOF)
E08 | geen SD kaart
E09 | SD kaart reset gefaald
E0A | SD kaart fysiek schrijf beschermd (controleer de schakelaar op de kaart)
EE5 | geen map
EE6 | alleen lezen bestand
EE7 | geen bestand - commando verwachte map
EE8 | schrijf fout
EE9 | mode incorrect voor schrijven
EEA | geen vrije ruimte op de SD kaart
EEB | bestand verwerker nog niet open
EEC | mode incorrect voor lezen
EED | onbekende mode om een bestand te openen
EEF | file systeem is kapot (test op PC)
EF1 | bestand verwerker al open
EF2 | bestand bestaat niet
EF3 | kan geen map maken
EF4 | bestand bestaat al
EF5 | bestand is niet correct (controleer spelling en vreemde tekens)
EF6 | verkeerde handeling gespecifieerd

## 10 Besluit

Uit dit blijkt dat alles werkt maar 2 sensoren hebben kleine afwijkingen, en de muziekkaart kon ik nog niet testen omdat ik geen SD kaart heb in FAT32 of lagen maar mijn SD kaart is exFAT.

28

## 11 Bibliografie

robot-electronics. (z.d.). <i>SRF02 Ultrasonic range finder</i>. Geraadpleegd op 4 november 2024, van https://robot-electronics.co.uk/htm/srf02techI2C.htm Vishay. (2009, 17 augustus). <i>TCRT5000</i>. Geraadpleegd op 4 november 2024, van https://www.vishay.com/docs/83760/tcrt5000.pdf
Sharp. (z.d.). <i>gp2Y0A21YK0F</i>. Geraadpleegd op 4 november 2024,
van https://global.sharp/products/device/lineup/data/pdf/datasheet/gp2y0a21yke.pdf Elektor, amp; Huyskens, Bart. (2011, 3 april). <i>Elektor Proton Robot</i>.
Geraadpleegd op 4 november 2024, van https://e2cre8.be/wp-content/uploads/2015/12/Elektor-proton-robot-programming-guide-V11 − .pdf (https://e2cre8.be/wp-content/uploads/2015/12/Elektor-proton-robot-programming-guide-V1_1-.pdf)

29

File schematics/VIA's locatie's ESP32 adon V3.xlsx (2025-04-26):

x | 69.775 | 70.4 | 71.025 | 71.65 | 72.275 | 72.9 | 73.525
y | 39.085 | 38.46 | 37.835 | 37.21 | 36.585 | 35.96 | 35.335

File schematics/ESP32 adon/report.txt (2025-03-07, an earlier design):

Plotted to 'C:\Users\debakkers\OneDrive - PTI-Kortrijk\programeren\Arduino\6TWEA\GRAP\tests\KiCad tests\ESP32 adon\ESP32 adon-F_Cu.gbr'.
Plotted to 'C:\Users\debakkers\OneDrive - PTI-Kortrijk\programeren\Arduino\6TWEA\GRAP\tests\KiCad tests\ESP32 adon\ESP32 adon-B_Cu.gbr'.
Plotted to 'C:\Users\debakkers\OneDrive - PTI-Kortrijk\programeren\Arduino\6TWEA\GRAP\tests\KiCad tests\ESP32 adon\ESP32 adon-F_Paste.gbr'.
Plotted to 'C:\Users\debakkers\OneDrive - PTI-Kortrijk\programeren\Arduino\6TWEA\GRAP\tests\KiCad tests\ESP32 adon\ESP32 adon-B_Paste.gbr'.
Plotted to 'C:\Users\debakkers\OneDrive - PTI-Kortrijk\programeren\Arduino\6TWEA\GRAP\tests\KiCad tests\ESP32 adon\ESP32 adon-F_Silkscreen.gbr'.
Plotted to 'C:\Users\debakkers\OneDrive - PTI-Kortrijk\programeren\Arduino\6TWEA\GRAP\tests\KiCad tests\ESP32 adon\ESP32 adon-B_Silkscreen.gbr'.
Plotted to 'C:\Users\debakkers\OneDrive - PTI-Kortrijk\programeren\Arduino\6TWEA\GRAP\tests\KiCad tests\ESP32 adon\ESP32 adon-F_Mask.gbr'.
Plotted to 'C:\Users\debakkers\OneDrive - PTI-Kortrijk\programeren\Arduino\6TWEA\GRAP\tests\KiCad tests\ESP32 adon\ESP32 adon-B_Mask.gbr'.
Plotted to 'C:\Users\debakkers\OneDrive - PTI-Kortrijk\programeren\Arduino\6TWEA\GRAP\tests\KiCad tests\ESP32 adon\ESP32 adon-Edge_Cuts.gbr'.
Gerber-job bestand 'C:\Users\debakkers\OneDrive - PTI-Kortrijk\programeren\Arduino\6TWEA\GRAP\tests\KiCad tests\ESP32 adon\ESP32 adon-job.gbrjob' maken.
Plotted to 'C:\Users\debakkers\OneDrive - PTI-Kortrijk\programeren\Arduino\6TWEA\GRAP\tests\KiCad tests\ESP32 adon\ESP32 adon-F_Cu.gbr'.
Plotted to 'C:\Users\debakkers\OneDrive - PTI-Kortrijk\programeren\Arduino\6TWEA\GRAP\tests\KiCad tests\ESP32 adon\ESP32 adon-B_Cu.gbr'.
Plotted to 'C:\Users\debakkers\OneDrive - PTI-Kortrijk\programeren\Arduino\6TWEA\GRAP\tests\KiCad tests\ESP32 adon\ESP32 adon-F_Paste.gbr'.
Plotted to 'C:\Users\debakkers\OneDrive - PTI-Kortrijk\programeren\Arduino\6TWEA\GRAP\tests\KiCad tests\ESP32 adon\ESP32 adon-B_Paste.gbr'.
Plotted to 'C:\Users\debakkers\OneDrive - PTI-Kortrijk\programeren\Arduino\6TWEA\GRAP\tests\KiCad tests\ESP32 adon\ESP32 adon-F_Silkscreen.gbr'.
Plotted to 'C:\Users\debakkers\OneDrive - PTI-Kortrijk\programeren\Arduino\6TWEA\GRAP\tests\KiCad tests\ESP32 adon\ESP32 adon-B_Silkscreen.gbr'.
Plotted to 'C:\Users\debakkers\OneDrive - PTI-Kortrijk\programeren\Arduino\6TWEA\GRAP\tests\KiCad tests\ESP32 adon\ESP32 adon-F_Mask.gbr'.
Plotted to 'C:\Users\debakkers\OneDrive - PTI-Kortrijk\programeren\Arduino\6TWEA\GRAP\tests\KiCad tests\ESP32 adon\ESP32 adon-B_Mask.gbr'.
Plotted to 'C:\Users\debakkers\OneDrive - PTI-Kortrijk\programeren\Arduino\6TWEA\GRAP\tests\KiCad tests\ESP32 adon\ESP32 adon-Edge_Cuts.gbr'.
Gerber-job bestand 'C:\Users\debakkers\OneDrive - PTI-Kortrijk\programeren\Arduino\6TWEA\GRAP\tests\KiCad tests\ESP32 adon\ESP32 adon-job.gbrjob' maken.
Informatie: Klaar.
Informatie: Klaar.

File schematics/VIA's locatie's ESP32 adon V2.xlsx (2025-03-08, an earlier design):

x | 69.47 | 70.095 | 70.72 | 71.345 | 71.97 | 72.595 | 73.22
y | 62.285 | 61.66 | 61.035 | 60.41 | 59.785 | 59.16 | 58.535

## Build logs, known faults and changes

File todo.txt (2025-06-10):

maak de libery klaar
pas de brete van het hoofd aan
pas de brete tussen de 8 pinnen addon
lijnsensor smaller maken

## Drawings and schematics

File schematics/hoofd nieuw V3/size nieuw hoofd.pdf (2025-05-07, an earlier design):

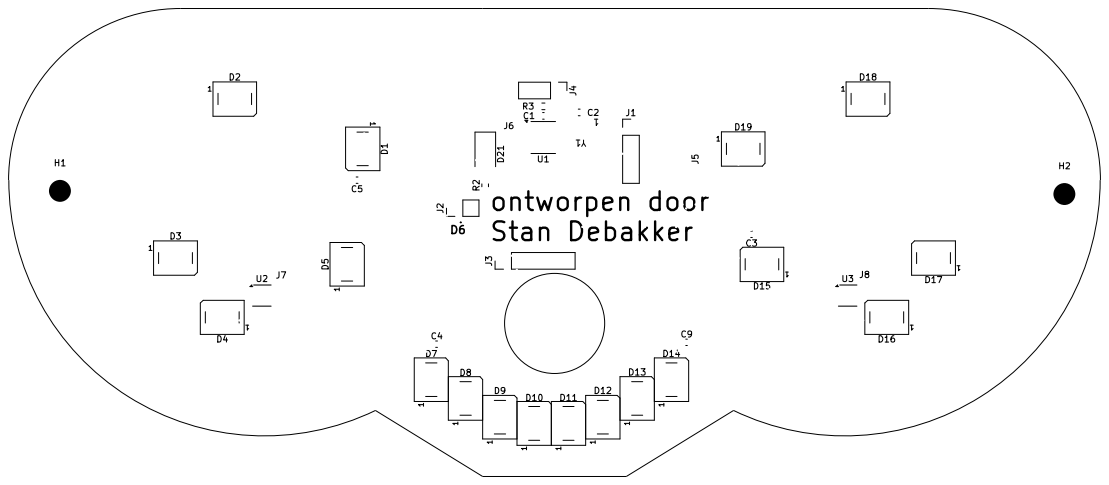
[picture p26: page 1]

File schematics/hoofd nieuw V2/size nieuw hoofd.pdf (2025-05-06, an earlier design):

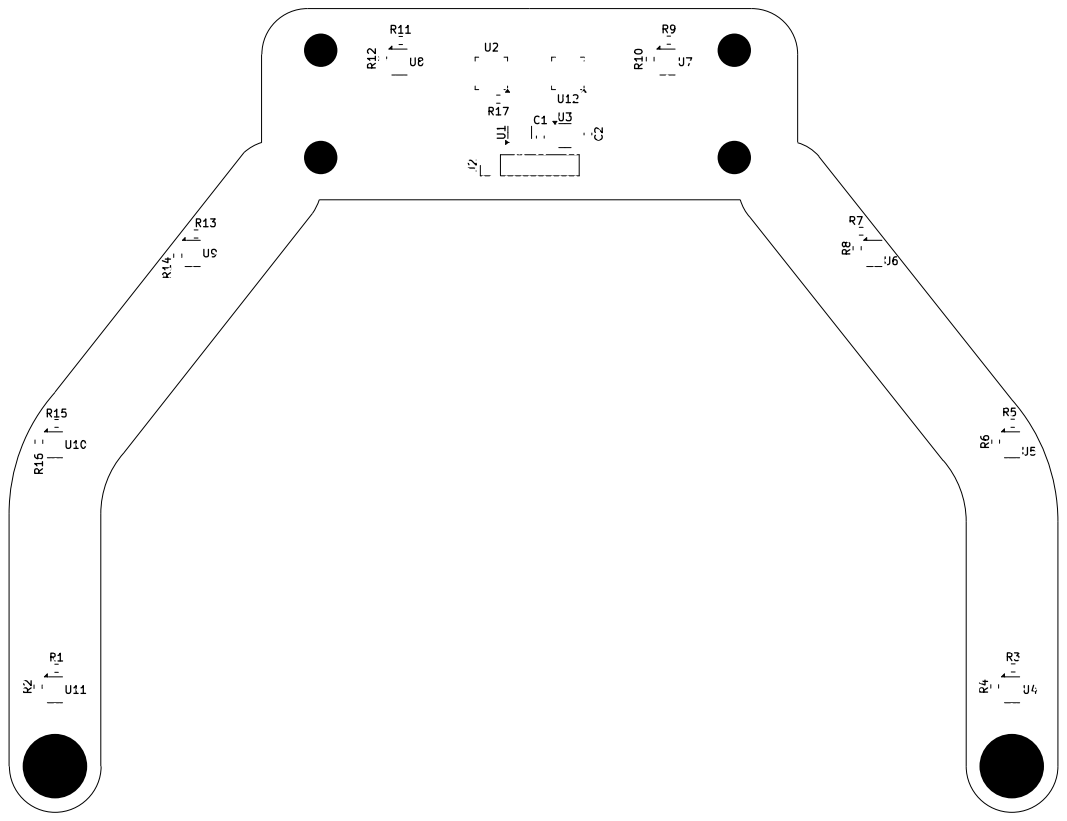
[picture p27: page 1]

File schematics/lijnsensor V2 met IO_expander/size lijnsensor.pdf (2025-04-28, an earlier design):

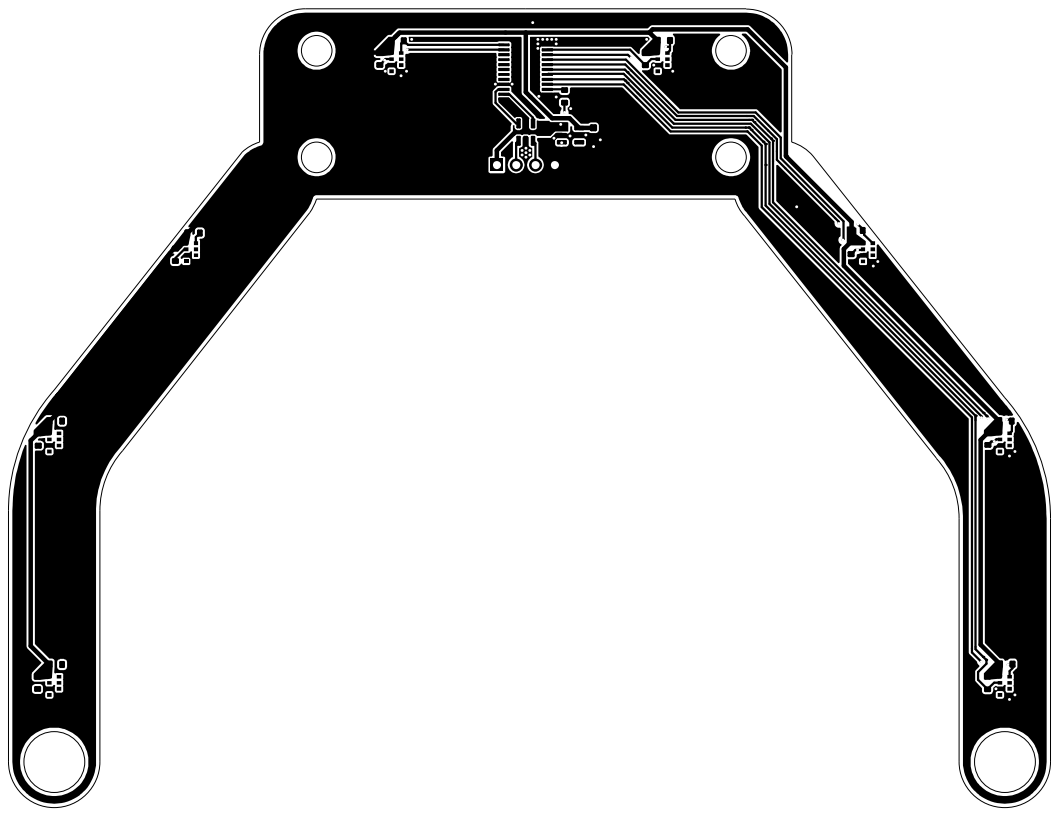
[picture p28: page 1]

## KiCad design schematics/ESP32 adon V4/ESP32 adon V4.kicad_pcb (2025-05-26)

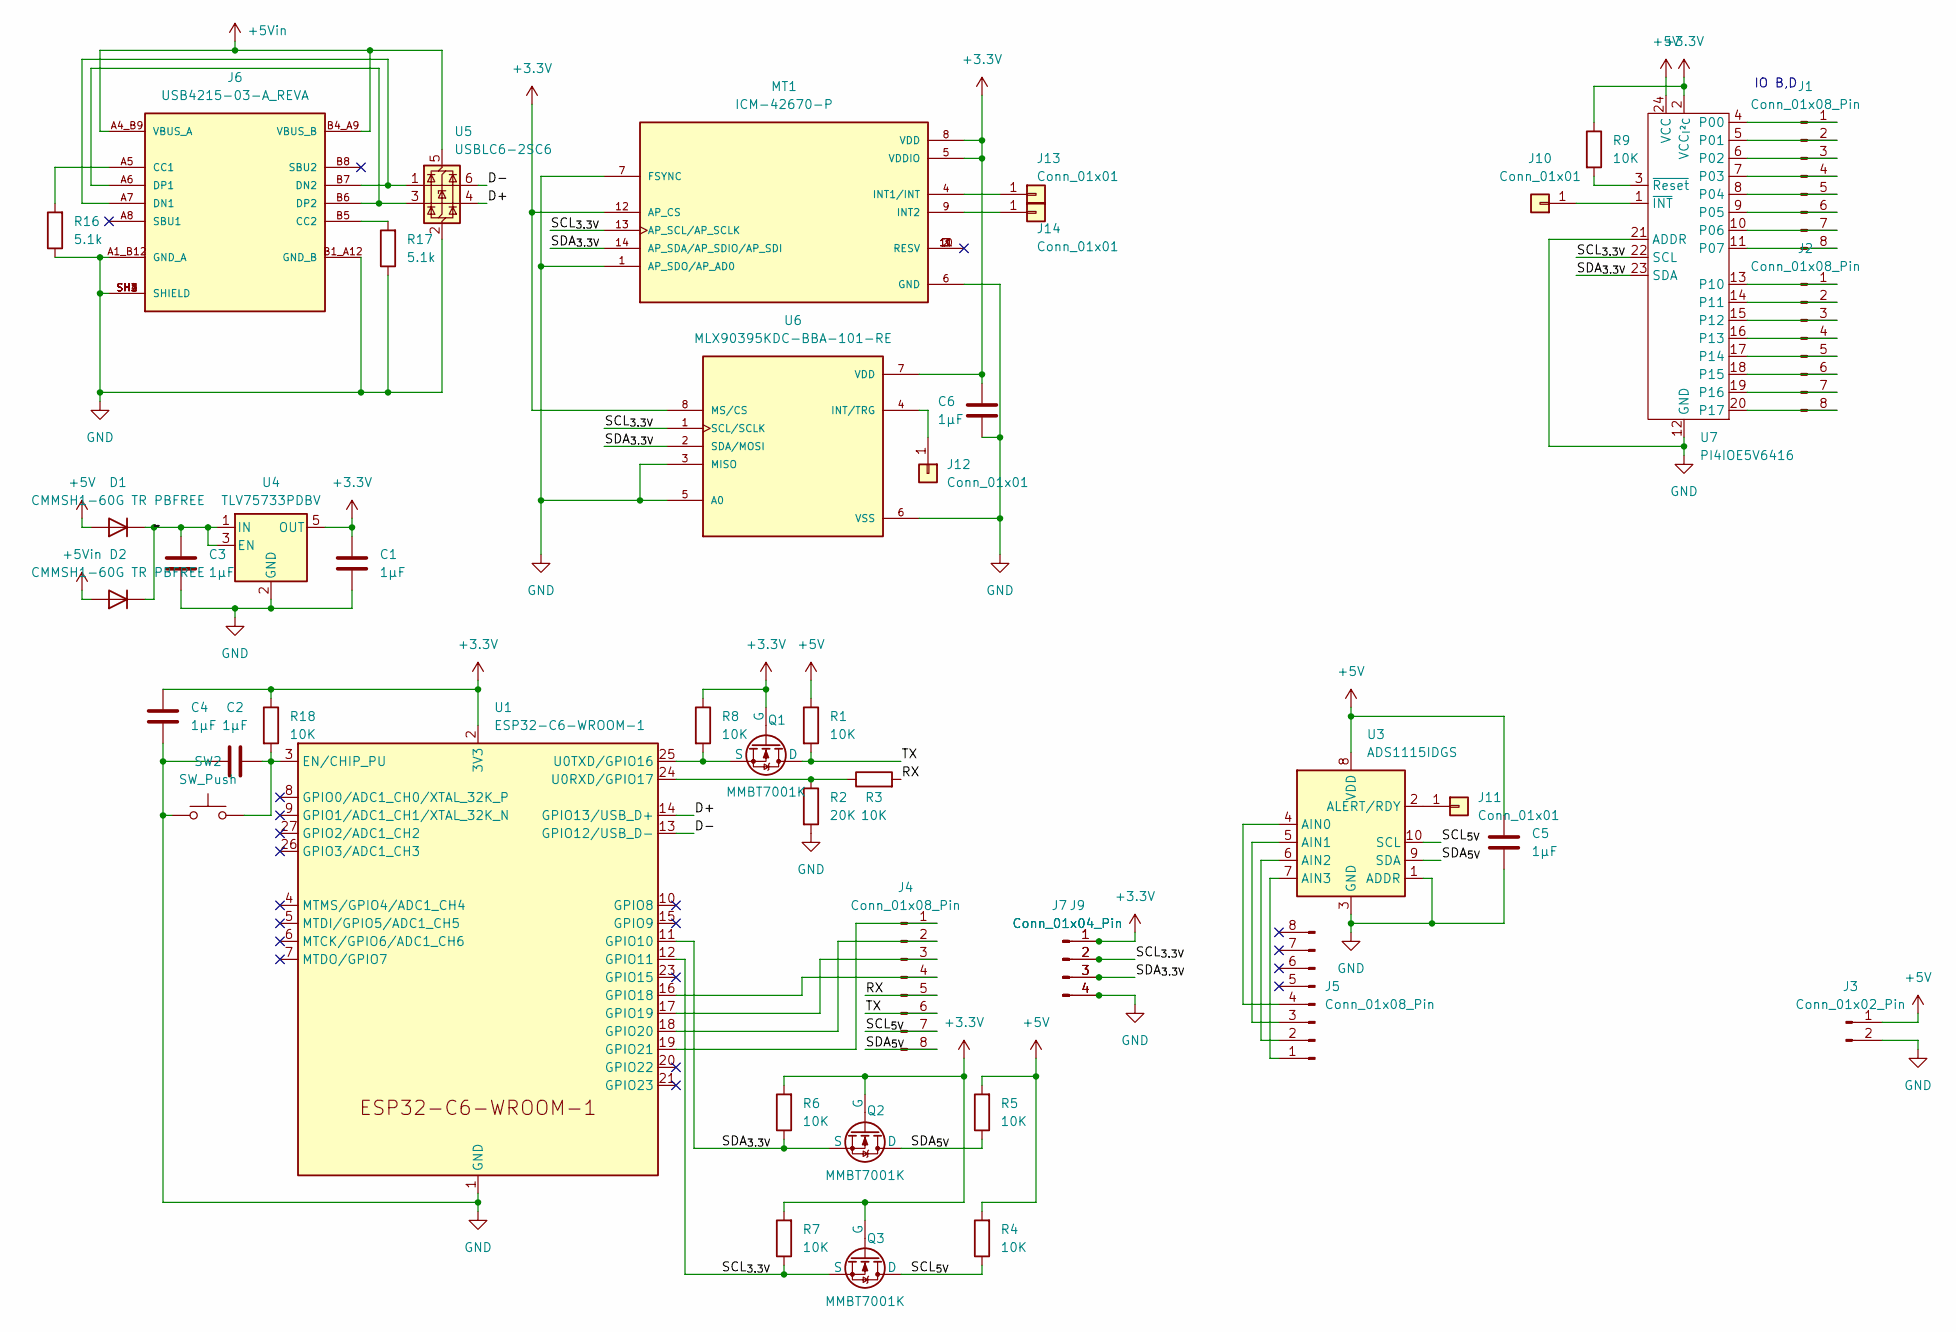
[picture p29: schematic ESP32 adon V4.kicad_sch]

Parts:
C1, C2, C3, C4, C5, C6: 1µF; C_0603_1608Metric
D1, D2: CMMSH1-60G TR PBFREE; D_SOD-123F
J1, J2, J4, J5: Conn_01x08_Pin; PinSocket_1x08_P2.54mm_Vertical
J3: Conn_01x02_Pin; PinSocket_1x02_P2.54mm_Vertical
J6: USB4215-03-A_REVA; usb4215-3472997; PARTREV A
J7, J9: Conn_01x04_Pin; PinSocket_1x04_P2.54mm_Vertical
J10, J11, J12, J13, J14: Conn_01x01; SolderWirePad_1x01_SMD_1x2mm
MT1: ICM-42670-P; Bosch_LGA-14_3x2.5mm_P0.5mm; PARTREV 1.1
Q1, Q2, Q3: MMBT7001K; TSOT-23
R1, R3, R4, R5, R6, R7, R8, R9, R18: 10K; R_0603_1608Metric
R2: 20K; R_0603_1608Metric
R16, R17: 5.1k; R_0603_1608Metric
SW2: SW_Push; SW_PUSH_6mm
U1: ESP32-C6-WROOM-1
U3: ADS1115IDGS; TSSOP-10_3x3mm_P0.5mm
U4: TLV75733PDBV; SOT-23-5
U5: USBLC6-2SC6; SOT-23-6
U6: MLX90395KDC-BBA-101-RE; SOIC-8_3.9x4.9mm_P1.27mm; PARTREV 6.0
U7: PI4IOE5V6416; TSSOP-24_4.4x7.8mm_P0.65mm

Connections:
+3.3V: C1.1, C4.2, C6.2, J7.1, J9.1, MT1.5 (VDDIO), MT1.8 (VDD), MT1.12 (AP_CS), Q1.1 (G), Q2.1 (G), Q3.1 (G), R6.2, R7.2, R8.1, R9.1, R18.1, U1.2 (3V3), U4.5 (OUT), U6.7 (VDD), U6.8 (MS/CS), U7.2 (VCC_{I²C})
+5V: C5.2, D1.2 (A), J3.1, R1.1, R4.2, R5.2, U3.8 (VDD), U7.24 (VCC)
+5Vin: D2.2 (A), J6.A4_B9 (VBUS_A), J6.B4_A9 (VBUS_B), U5.5 (VBUS)
/D+: U1.14 (GPIO13/USB_D+), U5.4 (I/O2)
/D-: U1.13 (GPIO12/USB_D-), U5.6 (I/O1)
/RX: J4.5, R3.2
/SCL_{3.3V}: J7.2, J9.2, MT1.13 (AP_SCL/AP_SCLK), Q3.2 (S), R7.1, U1.12 (GPIO11), U6.1 (SCL/SCLK), U7.22 (SCL)
/SCL_{5V}: J4.7, Q3.3 (D), R4.1, U3.10 (SCL)
/SDA_{3.3V}: J7.3, J9.3, MT1.14 (AP_SDA/AP_SDIO/AP_SDI), Q2.2 (S), R6.1, U1.11 (GPIO10), U6.2 (SDA/MOSI), U7.23 (SDA)
/SDA_{5V}: J4.8, Q2.3 (D), R5.1, U3.9 (SDA)
/TX: J4.6, Q1.3 (D), R1.2
/Vin_reg: C3.1, D1.1 (K), D2.1 (K), U4.1 (IN), U4.3 (EN)
GND: C1.2, C2.1, C3.2, C4.1, C5.1, C6.1, J3.2, J6.A1_B12 (GND_A), J6.B1_A12 (GND_B), J6.SH1 (SHIELD), J6.SH2 (SHIELD), J6.SH3 (SHIELD), J6.SH4 (SHIELD), J7.4, J9.4, MT1.1 (AP_SDO/AP_AD0), MT1.6 (GND), MT1.7 (FSYNC), R2.2, R16.1, R17.1, SW2.1, U1.1 (GND), U1.28 (GND), U1.29 (GND), U3.1 (ADDR), U3.3 (GND), U4.2 (GND), U5.2 (GND), U6.3 (MISO), U6.5 (A0), U6.6 (VSS), U7.12 (GND), U7.21 (ADDR)
unnamed: J1.1, U7.4 (P00)
unnamed: J1.2, U7.5 (P01)
unnamed: J1.3, U7.6 (P02)
unnamed: J1.4, U7.7 (P03)
unnamed: J1.5, U7.8 (P04)
unnamed: J1.6, U7.9 (P05)
unnamed: J1.7, U7.10 (P06)
unnamed: J1.8, U7.11 (P07)
unnamed: J2.1, U7.13 (P10)
unnamed: J2.2, U7.14 (P11)
unnamed: J2.3, U7.15 (P12)
unnamed: J2.4, U7.16 (P13)
unnamed: J2.5, U7.17 (P14)
unnamed: J2.6, U7.18 (P15)
unnamed: J2.7, U7.19 (P16)
unnamed: J2.8, U7.20 (P17)
unnamed: J4.1, U1.19 (GPIO21)
unnamed: J4.2, U1.18 (GPIO20)
unnamed: J4.3, U1.17 (GPIO19)
unnamed: J4.4, U1.16 (GPIO18)
unnamed: J5.1, U3.7 (AIN3)
unnamed: J5.2, U3.6 (AIN2)
unnamed: J5.3, U3.5 (AIN1)
unnamed: J5.4, U3.4 (AIN0)
unnamed: J6.A5 (CC1), R16.2
unnamed: J6.B5 (CC2), R17.2
unnamed: J6.A7 (DN1), J6.B7 (DN2), U5.1 (I/O1)
unnamed: J6.A6 (DP1), J6.B6 (DP2), U5.3 (I/O2)
unnamed: J10.1, U7.1 (~INT)
unnamed: J11.1, U3.2 (ALERT/RDY)
unnamed: J12.1, U6.4 (INT/TRG)
unnamed: J13.1, MT1.4 (INT1/INT)
unnamed: J14.1, MT1.9 (INT2)
unnamed: Q1.2 (S), R8.2, U1.25 (U0TXD/GPIO16)
unnamed: C2.2, R18.2, SW2.2, U1.3 (EN/CHIP_PU)
unnamed: R2.1, R3.1, U1.24 (U0RXD/GPIO17)
unnamed: R9.2, U7.3 (~Reset)

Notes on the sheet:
IO B,D

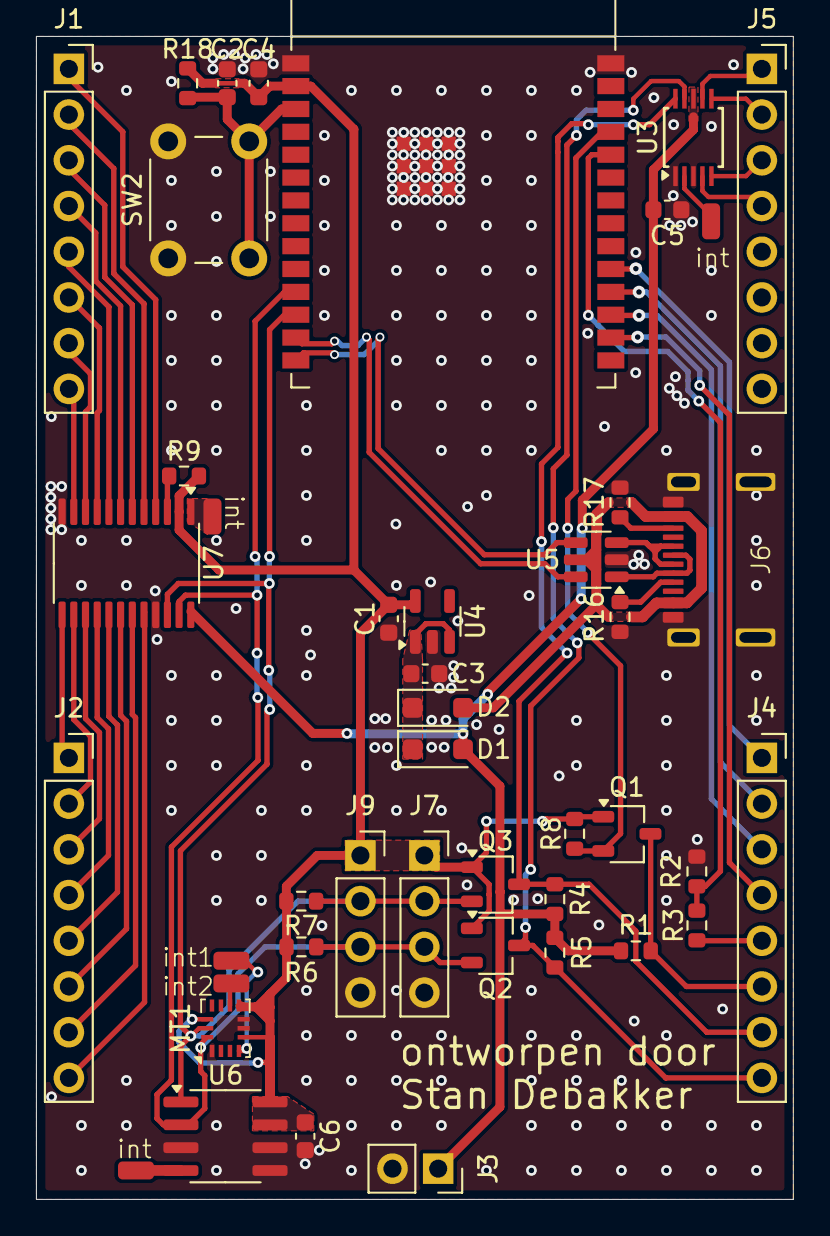
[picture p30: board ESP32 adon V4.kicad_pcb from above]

Board: 2 copper layers, 42.0 x 64.6 mm, 44 parts (0 on the bottom side), 50 nets.

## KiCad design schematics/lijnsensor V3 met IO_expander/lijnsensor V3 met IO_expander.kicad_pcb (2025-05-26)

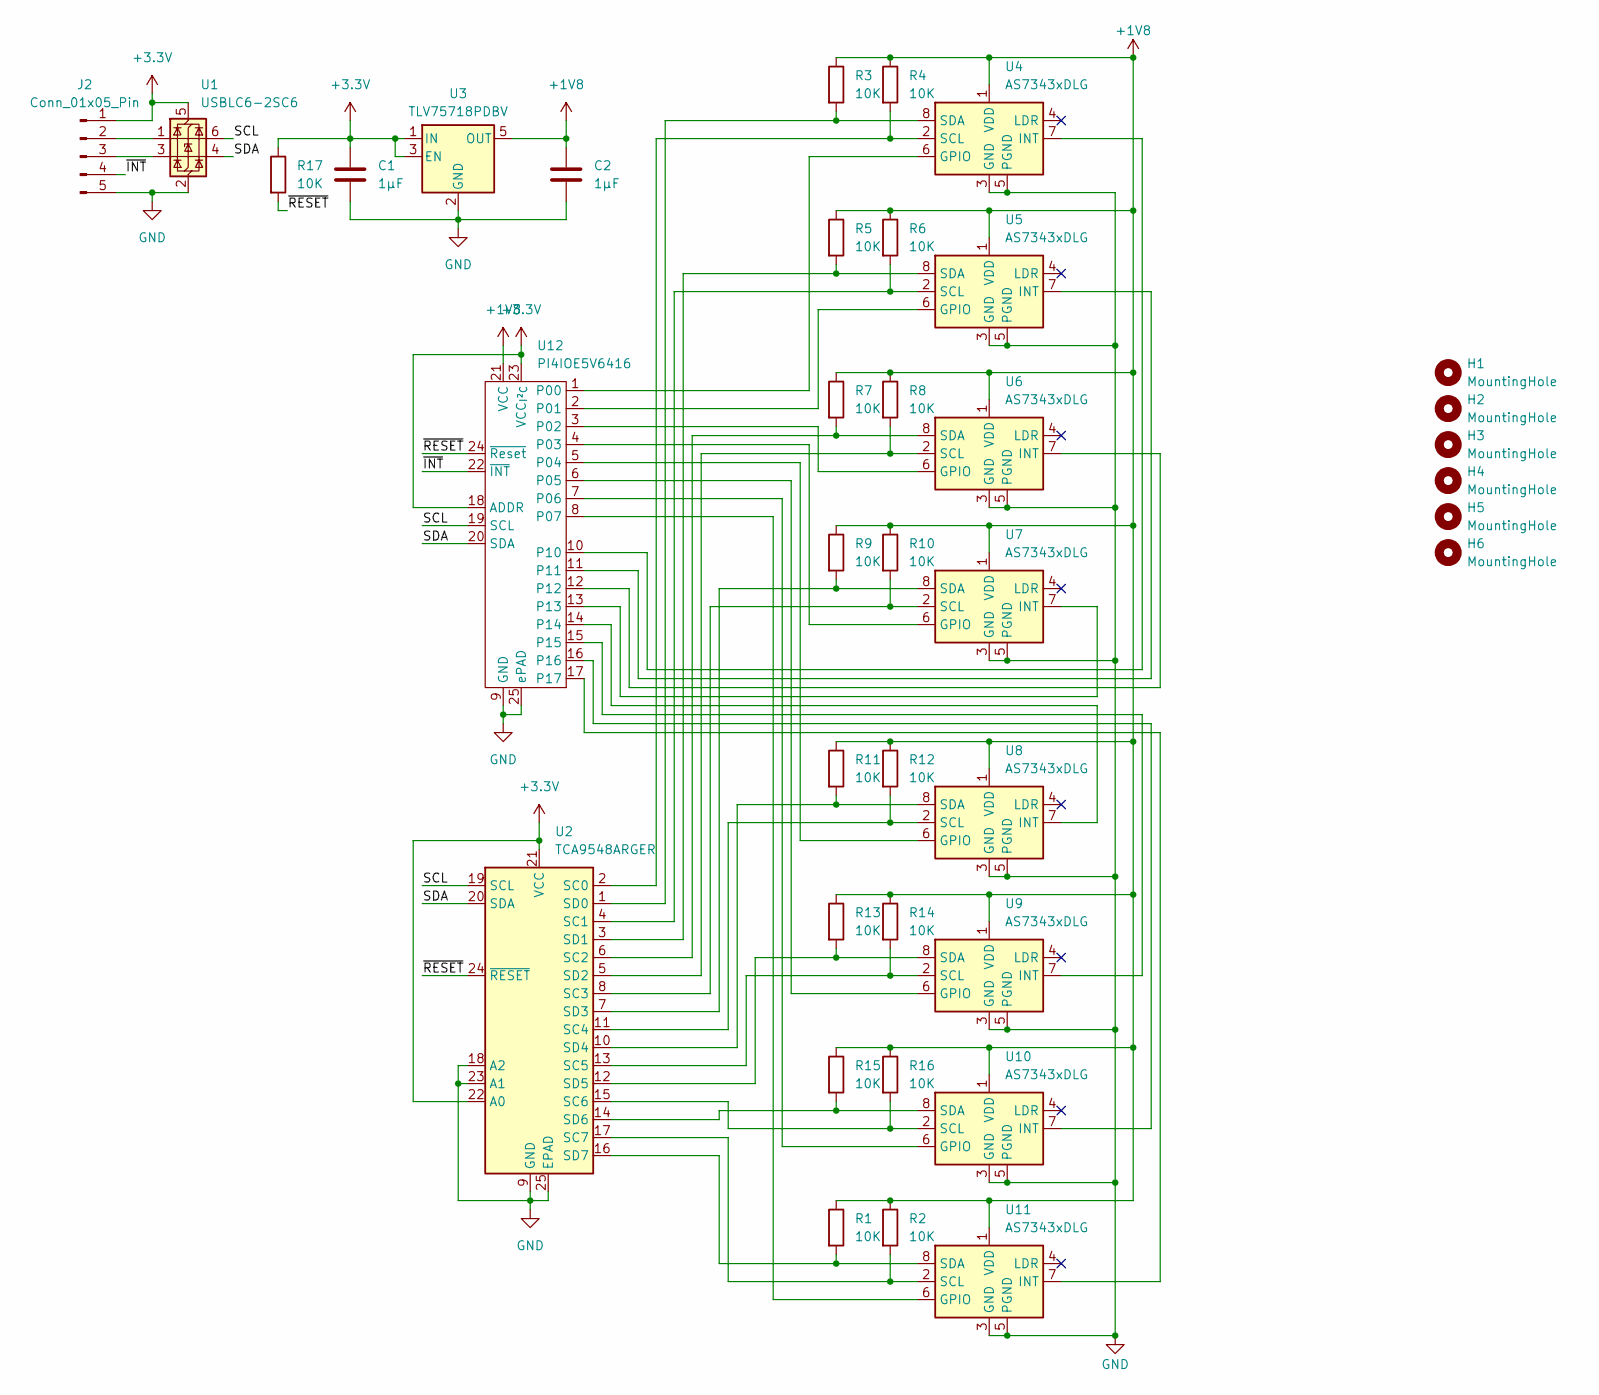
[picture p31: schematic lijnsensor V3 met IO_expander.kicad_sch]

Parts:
C1, C2: 1µF; C_0603_1608Metric
H1, H2, H3, H4: MountingHole; MountingHole_4.3mm_M4
H5, H6: MountingHole; MountingHole_8.4mm_M8
J2: Conn_01x05_Pin; PinHeader_1x05_P2.54mm_Vertical
R1, R2, R3, R4, R5, R6, R7, R8, R9, R10, R11, R12, R13, R14, R15, R16, R17: 10K; R_0603_1608Metric
U1: USBLC6-2SC6; SOT-23-6
U2: TCA9548ARGER; Texas_RGE0024H_VQFN-24-1EP_4x4mm_P0.5mm_EP2.7x2.7mm
U3: TLV75718PDBV; SOT-23-5
U4, U5, U6, U7, U8, U9, U10, U11: AS7343xDLG; AMS_OLGA-8_2x3.1mm_P0.8mm
U12: PI4IOE5V6416

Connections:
+1V8: C2.1, R1.1, R2.1, R3.1, R4.1, R5.1, R6.1, R7.1, R8.1, R9.1, R10.1, R11.1, R12.1, R13.1, R14.1, R15.1, R16.1, U3.5 (OUT), U4.1 (VDD), U5.1 (VDD), U6.1 (VDD), U7.1 (VDD), U8.1 (VDD), U9.1 (VDD), U10.1 (VDD), U11.1 (VDD), U12.21 (VCC)
+3.3V: C1.1, J2.1, R17.1, U1.5 (VBUS), U2.21 (VCC), U2.22 (A0), U3.1 (IN), U3.3 (EN), U12.18 (ADDR), U12.23 (VCC_{I²C})
/SCL: U1.6 (I/O1), U2.19 (SCL), U12.19 (SCL)
/SDA: U1.4 (I/O2), U2.20 (SDA), U12.20 (SDA)
/~INT: J2.4, U12.22 (~INT)
/~RESET: R17.2, U2.24 (~RESET), U12.24 (~Reset)
GND: C1.2, C2.2, J2.5, U1.2 (GND), U2.9 (GND), U2.18 (A2), U2.23 (A1), U2.25 (EPAD), U3.2 (GND), U4.3 (GND), U4.5 (PGND), U5.3 (GND), U5.5 (PGND), U6.3 (GND), U6.5 (PGND), U7.3 (GND), U7.5 (PGND), U8.3 (GND), U8.5 (PGND), U9.3 (GND), U9.5 (PGND), U10.3 (GND), U10.5 (PGND), U11.3 (GND), U11.5 (PGND), U12.9 (GND), U12.25 (ePAD)
unnamed: J2.2, U1.1 (I/O1)
unnamed: J2.3, U1.3 (I/O2)
unnamed: R4.2, U2.2 (SC0), U4.2 (SCL)
unnamed: R6.2, U2.4 (SC1), U5.2 (SCL)
unnamed: R7.2, U2.6 (SC2), U6.8 (SDA)
unnamed: R10.2, U2.8 (SC3), U7.2 (SCL)
unnamed: R12.2, U2.11 (SC4), U8.2 (SCL)
unnamed: R14.2, U2.13 (SC5), U9.2 (SCL)
unnamed: R3.2, U2.1 (SD0), U4.8 (SDA)
unnamed: R5.2, U2.3 (SD1), U5.8 (SDA)
unnamed: R8.2, U2.5 (SD2), U6.2 (SCL)
unnamed: R9.2, U2.7 (SD3), U7.8 (SDA)
unnamed: R11.2, U2.10 (SD4), U8.8 (SDA)
unnamed: R13.2, U2.12 (SD5), U9.8 (SDA)
unnamed: U10.6 (GPIO), U12.7 (P06)
unnamed: U10.7 (INT), U12.16
unnamed: R16.2, U2.15 (SC6), U10.2 (SCL)
unnamed: R15.2, U2.14 (SD6), U10.8 (SDA)
unnamed: U11.6 (GPIO), U12.8 (P07)
unnamed: U11.7 (INT), U12.17
unnamed: R2.2, U2.17 (SC7), U11.2 (SCL)
unnamed: R1.2, U2.16 (SD7), U11.8 (SDA)
unnamed: U4.6 (GPIO), U12.1 (P00)
unnamed: U5.6 (GPIO), U12.2 (P01)
unnamed: U6.6 (GPIO), U12.3 (P02)
unnamed: U7.6 (GPIO), U12.4 (P03)
unnamed: U8.6 (GPIO), U12.5 (P04)
unnamed: U9.6 (GPIO), U12.6 (P05)
unnamed: U4.7 (INT), U12.10
unnamed: U5.7 (INT), U12.11
unnamed: U6.7 (INT), U12.12
unnamed: U7.7 (INT), U12.13
unnamed: U8.7 (INT), U12.14
unnamed: U9.7 (INT), U12.15

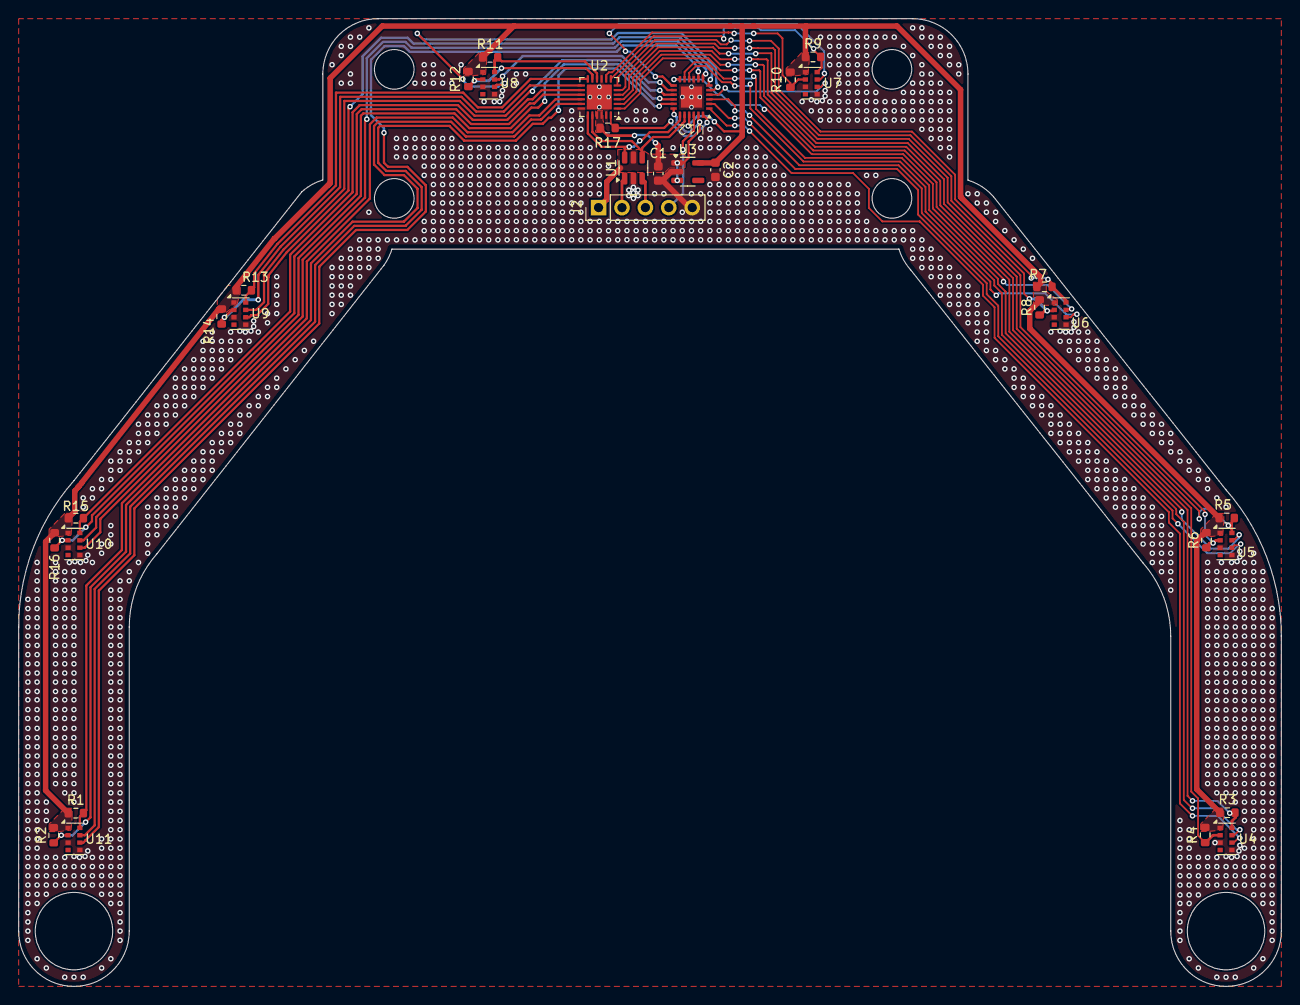
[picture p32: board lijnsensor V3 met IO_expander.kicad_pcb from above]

Board: 2 copper layers, 137.0 x 105.0 mm, 38 parts (0 on the bottom side), 41 nets.

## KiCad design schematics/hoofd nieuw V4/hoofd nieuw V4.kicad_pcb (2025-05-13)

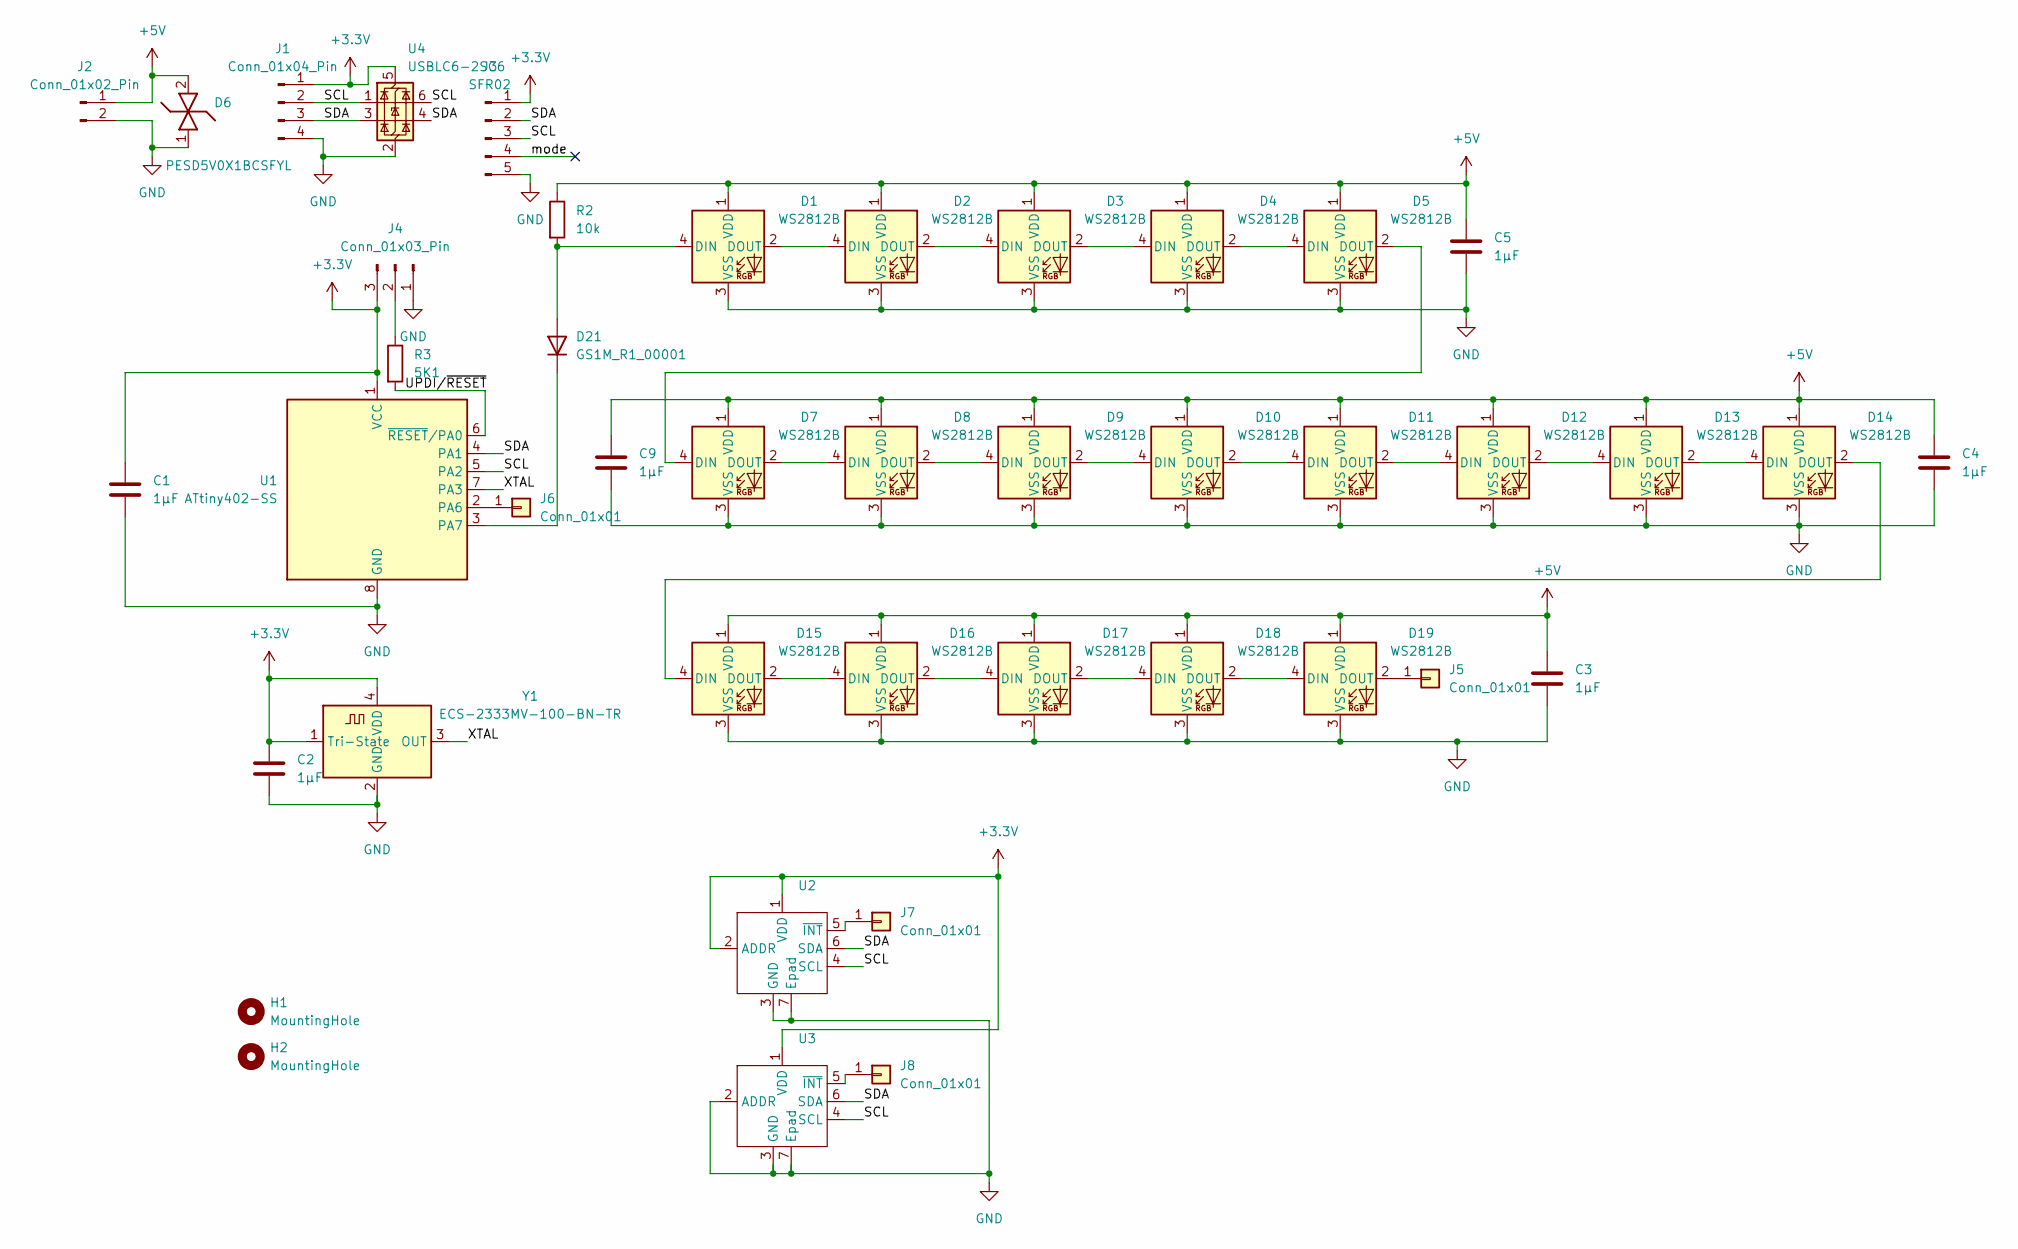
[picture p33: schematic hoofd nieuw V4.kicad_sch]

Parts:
C1, C2, C3, C4, C5, C9: 1µF; C_0603_1608Metric
D1, D2, D3, D4, D5, D7, D8, D9, D10, D11, D12, D13, D14, D15, D16, D17, D18, D19: WS2812B; LED_WS2812B_PLCC4_5.0x5.0mm_P3.2mm
D6: PESD5V0X1BCSFYL; PMEG3005AESFYL; Mouser Part Number 771-PESD5V0X1BCSFYL
D21: GS1M_R1_00001; D_SMA
H1, H2: MountingHole; MountingHole_3.5mm
J1: Conn_01x04_Pin; PinHeader_1x04_P2.54mm_Vertical
J2: Conn_01x02_Pin; PinHeader_1x02_P2.54mm_Vertical
J3: SFR02; PinHeader_1x05_P2.54mm_Vertical
J4: Conn_01x03_Pin; PinHeader_1x03_P2.54mm_Vertical
J5, J6, J7, J8: Conn_01x01; SolderWirePad_1x01_SMD_1x2mm
R2: 10k; R_0603_1608Metric
R3: 5K1; R_0603_1608Metric
U1: ATtiny402-SS; SOIC-8_3.9x4.9mm_P1.27mm
U2, U3: Texas_PWSON-N6
U4: USBLC6-2SC6; SOT-23-6
Y1: ECS-2333MV-100-BN-TR; ESC-2333-xxx-xxx

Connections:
+3.3V: C1.1, C2.1, J1.1, J3.1, J4.3, U1.1 (VCC), U2.1 (VDD), U2.2 (ADDR), U3.1 (VDD), U4.5 (VBUS), Y1.1 (Tri-State), Y1.4 (VDD)
+5V: C3.1, C4.1, C5.1, C9.1, D1.1 (VDD), D2.1 (VDD), D3.1 (VDD), D4.1 (VDD), D5.1 (VDD), D6.2 (K2), D7.1 (VDD), D8.1 (VDD), D9.1 (VDD), D10.1 (VDD), D11.1 (VDD), D12.1 (VDD), D13.1 (VDD), D14.1 (VDD), D15.1 (VDD), D16.1 (VDD), D17.1 (VDD), D18.1 (VDD), D19.1 (VDD), J2.1, R2.1
/SCL: J1.2, J3.3, U1.5 (PA2), U2.4 (SCL), U3.4 (SCL), U4.1 (I/O1), U4.6 (I/O1)
/SDA: J1.3, J3.2, U1.4 (PA1), U2.6 (SDA), U3.6 (SDA), U4.3 (I/O2), U4.4 (I/O2)
/UPDI/~RESET: R3.2, U1.6 (~RESET/PA0)
/XTAL: U1.7 (PA3), Y1.3 (OUT)
/mode: J3.4
GND: C1.2, C2.2, C3.2, C4.2, C5.2, C9.2, D1.3 (VSS), D2.3 (VSS), D3.3 (VSS), D4.3 (VSS), D5.3 (VSS), D6.1 (K1), D7.3 (VSS), D8.3 (VSS), D9.3 (VSS), D10.3 (VSS), D11.3 (VSS), D12.3 (VSS), D13.3 (VSS), D14.3 (VSS), D15.3 (VSS), D16.3 (VSS), D17.3 (VSS), D18.3 (VSS), D19.3 (VSS), J1.4, J2.2, J3.5, J4.1, U1.8 (GND), U2.3 (GND), U2.7 (Epad), U3.2 (ADDR), U3.3 (GND), U3.7 (Epad), U4.2 (GND), Y1.2 (GND)
unnamed: D1.4 (DIN), D21.2 (A), R2.2
unnamed: D1.2 (DOUT), D2.4 (DIN)
unnamed: D2.2 (DOUT), D3.4 (DIN)
unnamed: D3.2 (DOUT), D4.4 (DIN)
unnamed: D4.2 (DOUT), D5.4 (DIN)
unnamed: D5.2 (DOUT), D7.4 (DIN)
unnamed: D7.2 (DOUT), D8.4 (DIN)
unnamed: D8.2 (DOUT), D9.4 (DIN)
unnamed: D9.2 (DOUT), D10.4 (DIN)
unnamed: D10.2 (DOUT), D11.4 (DIN)
unnamed: D11.2 (DOUT), D12.4 (DIN)
unnamed: D12.2 (DOUT), D13.4 (DIN)
unnamed: D13.2 (DOUT), D14.4 (DIN)
unnamed: D14.2 (DOUT), D15.4 (DIN)
unnamed: D15.2 (DOUT), D16.4 (DIN)
unnamed: D16.2 (DOUT), D17.4 (DIN)
unnamed: D17.2 (DOUT), D18.4 (DIN)
unnamed: D18.2 (DOUT), D19.4 (DIN)
unnamed: D19.2 (DOUT), J5.1
unnamed: D21.1 (K), U1.3 (PA7)
unnamed: J4.2, R3.1
unnamed: J6.1, U1.2 (PA6)
unnamed: J7.1, U2.5 (~INT)
unnamed: J8.1, U3.5 (~INT)

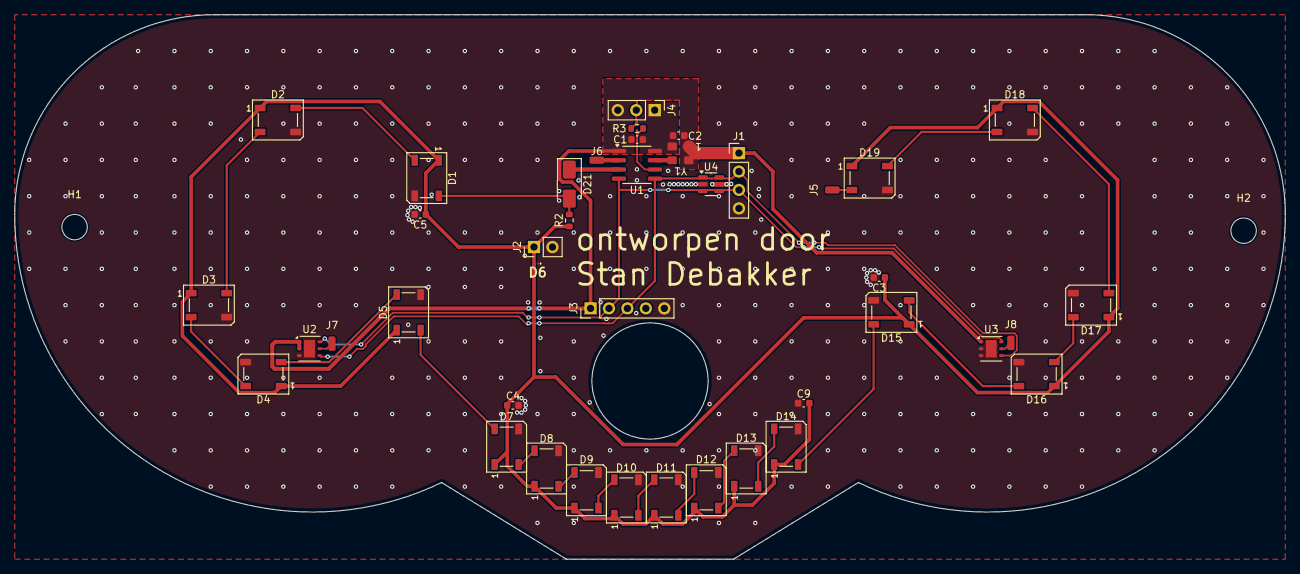
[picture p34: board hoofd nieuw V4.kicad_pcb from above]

Board: 2 copper layers, 175.0 x 75.0 mm, 43 parts (0 on the bottom side), 31 nets.

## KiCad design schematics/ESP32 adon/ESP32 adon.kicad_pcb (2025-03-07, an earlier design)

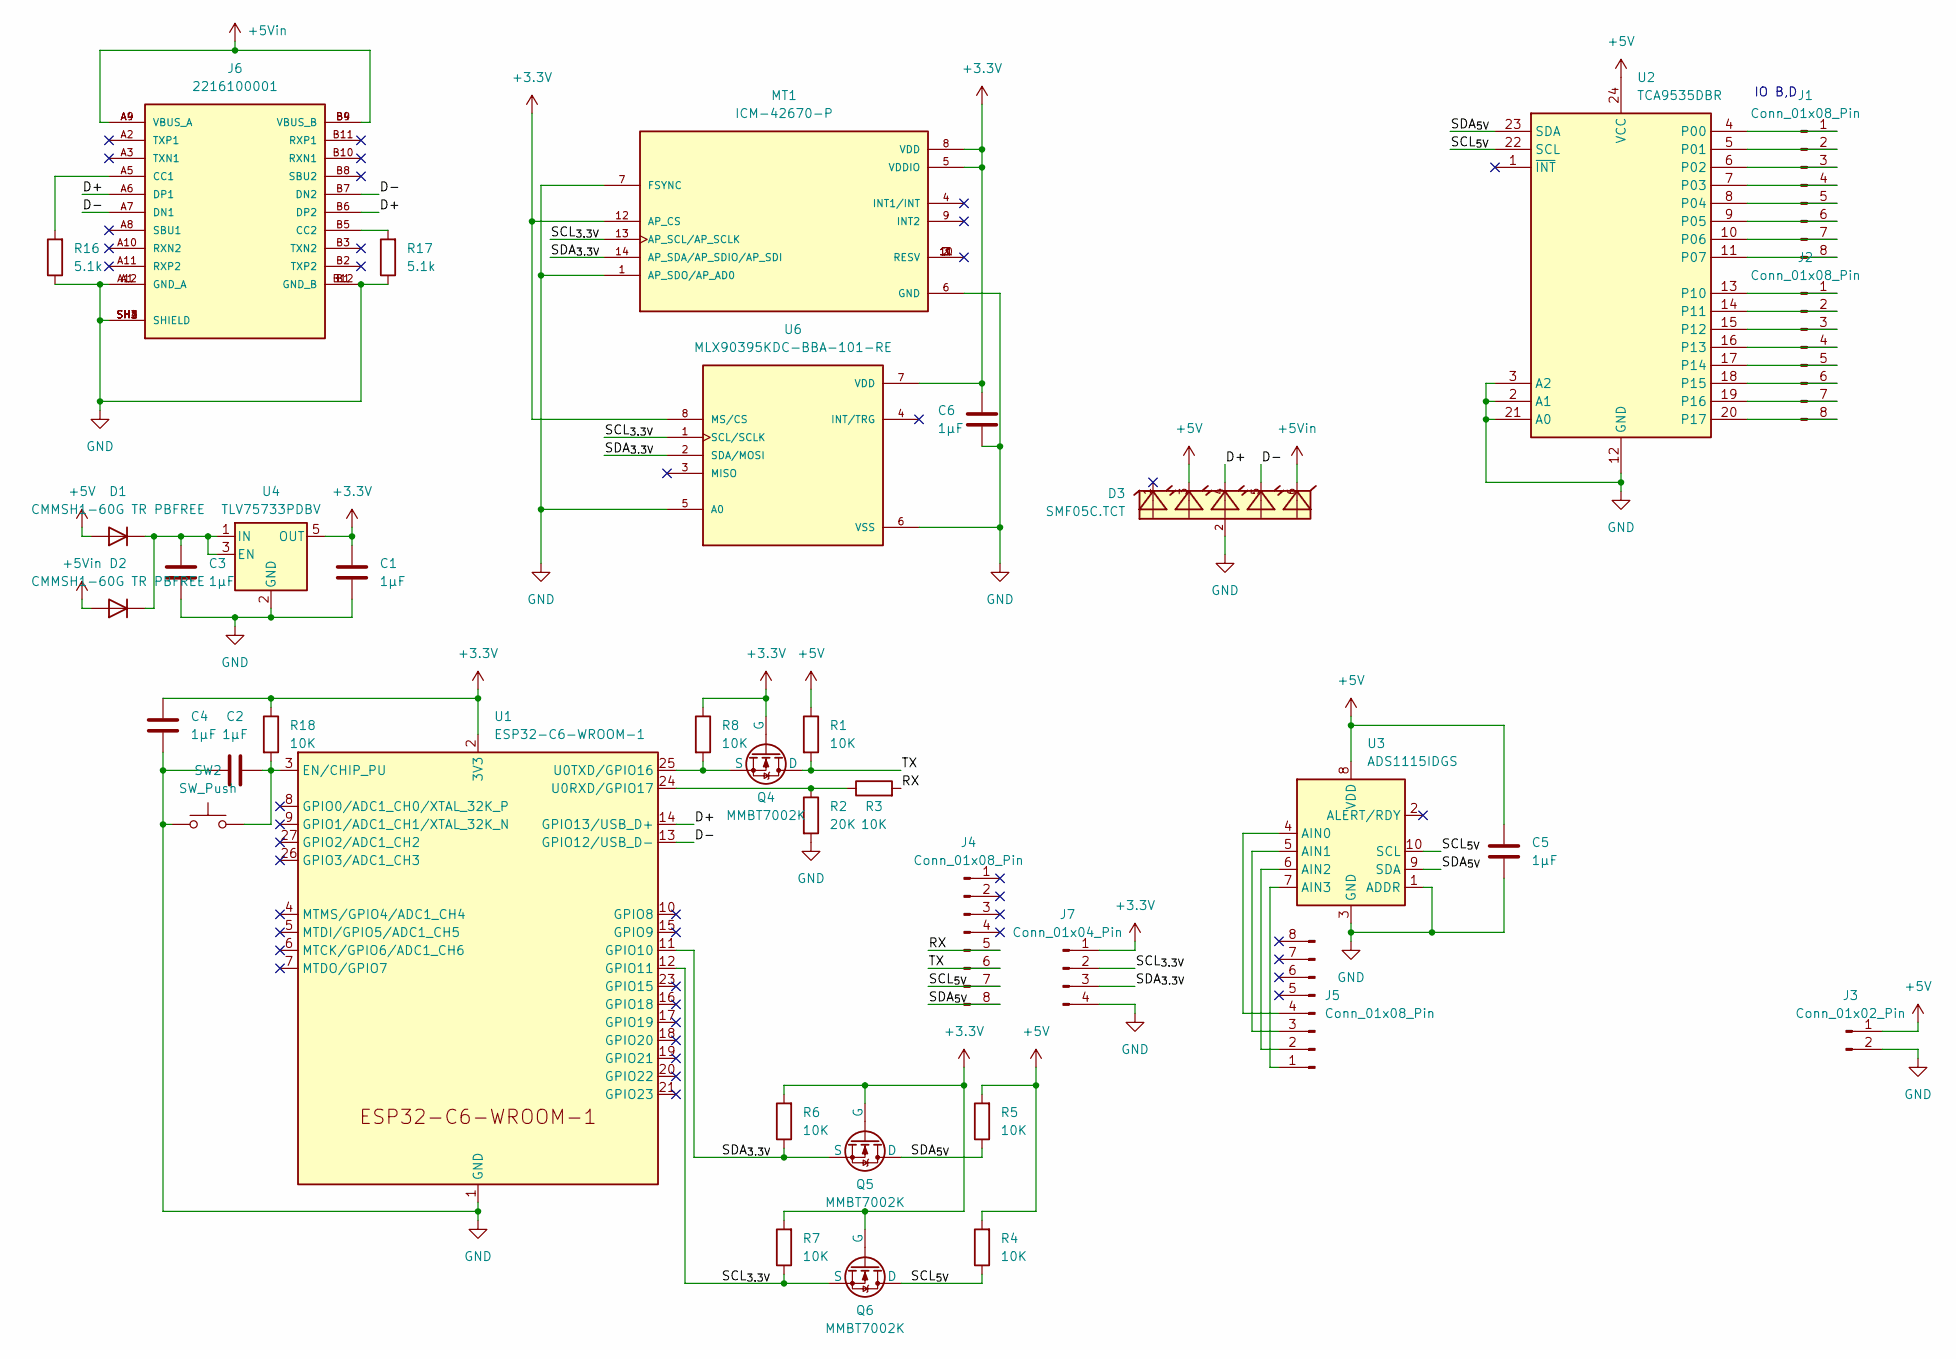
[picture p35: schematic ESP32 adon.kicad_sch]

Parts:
C1, C2, C3, C4, C5, C6: 1µF; C_0603_1608Metric
D1, D2: CMMSH1-60G TR PBFREE; D_SOD-123F
D3: SMF05C.TCT; Vishay_PowerPAK_SC70-6L_Dual
J1, J2, J4, J5: Conn_01x08_Pin; PinHeader_1x08_P2.00mm_Vertical
J3: Conn_01x02_Pin; PinHeader_1x02_P2.00mm_Vertical
J6: 2216100001; MOLEX_2216100001; PARTREV A
J7: Conn_01x04_Pin; PinHeader_1x04_P2.00mm_Vertical
MT1: ICM-42670-P; Bosch_LGA-14_3x2.5mm_P0.5mm; PARTREV 1.1
Q4, Q5, Q6: MMBT7002K; SOT-23
R1, R3, R4, R5, R6, R7, R8, R18: 10K; R_0603_1608Metric
R2: 20K; R_0603_1608Metric
R16, R17: 5.1k; R_0603_1608Metric
SW2: SW_Push; SW_PUSH_6mm
U1: ESP32-C6-WROOM-1
U2: TCA9535DBR; TSSOP-24_4.4x7.8mm_P0.65mm
U3: ADS1115IDGS; TSSOP-10_3x3mm_P0.5mm
U4: TLV75733PDBV; SOT-23-5
U6: MLX90395KDC-BBA-101-RE; SOIC-8-1EP_3.9x4.9mm_P1.27mm_EP2.29x3mm; PARTREV 6.0

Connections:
+3.3V: C1.1, C4.2, C6.2, J7.1, MT1.5 (VDDIO), MT1.8 (VDD), MT1.12 (AP_CS), Q4.2 (G), Q5.2 (G), Q6.2 (G), R6.2, R7.2, R8.1, R18.1, U1.2 (3V3), U4.5 (OUT), U6.7 (VDD), U6.8 (MS/CS)
+5V: C5.2, D1.2 (A), D3.3, J3.1, R1.1, R4.2, R5.2, U2.24 (VCC), U3.8 (VDD)
+5Vin: D2.2 (A), D3.6, J6.A4 (VBUS_A), J6.A9 (VBUS_A), J6.B4 (VBUS_B), J6.B9 (VBUS_B)
/D+: D3.4, J6.A6 (DP1), J6.B6 (DP2), U1.14 (GPIO13/USB_D+)
/D-: D3.5, J6.A7 (DN1), J6.B7 (DN2), U1.13 (GPIO12/USB_D-)
/RX: J4.5, R3.2
/SCL_{3.3V}: J7.2, MT1.13 (AP_SCL/AP_SCLK), Q6.3 (S), R7.1, U1.12 (GPIO11), U6.1 (SCL/SCLK)
/SCL_{5V}: J4.7, Q6.1 (D), R4.1, U2.22 (SCL), U3.10 (SCL)
/SDA_{3.3V}: J7.3, MT1.14 (AP_SDA/AP_SDIO/AP_SDI), Q5.3 (S), R6.1, U1.11 (GPIO10), U6.2 (SDA/MOSI)
/SDA_{5V}: J4.8, Q5.1 (D), R5.1, U2.23 (SDA), U3.9 (SDA)
/TX: J4.6, Q4.1 (D), R1.2
GND: C1.2, C2.1, C3.2, C4.1, C5.1, C6.1, D3.2, J3.2, J6.A1 (GND_A), J6.A12 (GND_A), J6.B1 (GND_B), J6.B12 (GND_B), J6.SH1 (SHIELD), J6.SH2 (SHIELD), J6.SH3 (SHIELD), J6.SH4 (SHIELD), J7.4, MT1.1 (AP_SDO/AP_AD0), MT1.6 (GND), MT1.7 (FSYNC), R2.2, R16.1, R17.1, SW2.1, U1.1 (GND), U1.28 (GND), U1.29 (GND), U2.2 (A1), U2.3 (A2), U2.12 (GND), U2.21 (A0), U3.1 (ADDR), U3.3 (GND), U4.2 (GND), U6.5 (A0), U6.6 (VSS)
unnamed: C3.1, D1.1 (K), D2.1 (K), U4.1 (IN), U4.3 (EN)
unnamed: J1.1, U2.4 (P00)
unnamed: J1.2, U2.5 (P01)
unnamed: J1.3, U2.6 (P02)
unnamed: J1.4, U2.7 (P03)
unnamed: J1.5, U2.8 (P04)
unnamed: J1.6, U2.9 (P05)
unnamed: J1.7, U2.10 (P06)
unnamed: J1.8, U2.11 (P07)
unnamed: J2.1, U2.13 (P10)
unnamed: J2.2, U2.14 (P11)
unnamed: J2.3, U2.15 (P12)
unnamed: J2.4, U2.16 (P13)
unnamed: J2.5, U2.17 (P14)
unnamed: J2.6, U2.18 (P15)
unnamed: J2.7, U2.19 (P16)
unnamed: J2.8, U2.20 (P17)
unnamed: J5.1, U3.7 (AIN3)
unnamed: J5.2, U3.6 (AIN2)
unnamed: J5.3, U3.5 (AIN1)
unnamed: J5.4, U3.4 (AIN0)
unnamed: J6.A5 (CC1), R16.2
unnamed: J6.B5 (CC2), R17.2
unnamed: Q4.3 (S), R8.2, U1.25 (U0TXD/GPIO16)
unnamed: C2.2, R18.2, SW2.2, U1.3 (EN/CHIP_PU)
unnamed: R2.1, R3.1, U1.24 (U0RXD/GPIO17)

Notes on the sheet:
IO B,D

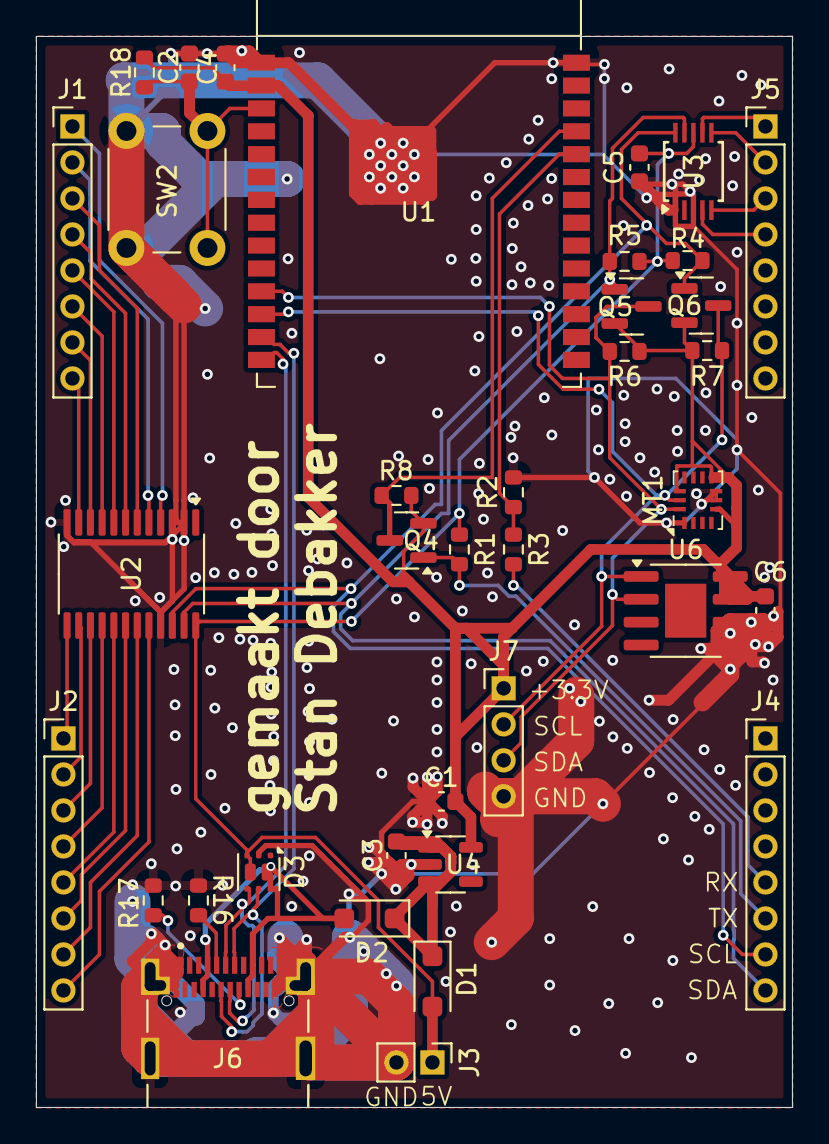
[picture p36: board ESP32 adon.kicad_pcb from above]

Board: 2 copper layers, 42.0 x 59.5 mm, 37 parts (0 on the bottom side), 38 nets.

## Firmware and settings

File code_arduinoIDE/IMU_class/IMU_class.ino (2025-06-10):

#include <Wire.h>
#include <math.h>
#ifndef addr_IMU
#define addr_IMU 0x68
#endif

/*typedef enum intf_CLK_SEL{
  RC,
  PLL_then_RC,
  no_clok=3,
}intf_CLK_SEL_t;
typedef enum avrege_accel{
  x2,
  x4,
  x8,
  x16,
  x32,
  x64,
}avrege_accel_t;
typedef enum DLPF {  //digital low pass filter
  DF_bypassed,
  DF_Hz180,
  DF_Hz72,
  DF_Hz34,
  DF_Hz16,
  DF_Hz8,
  DF_Hz4
}DLPF_t;
typedef enum LPF {  //low pass filter
  F_bypassed,
  F_Hz180,
  F_Hz121,
  F_Hz73,
  F_Hz53,
  F_Hz34,
  F_Hz25,
  F_Hz16
}LPF_t;
typedef enum sens_mode {
  IMU_off,
  IMU_standby,
  IMU_LN=3
} sens_mode_t;
*/

typedef enum ODR_set {
  Hz1600=5,
  Hz800,
  Hz400,
  Hz200,
  Hz100,
  Hz50,
  Hz25,
  Hz12
}ODR_set_t;
typedef enum g_set {
  g16,
  g8,
  g4,
  g2
} g_set_t;
typedef enum dps_set {
  dps2000,
  dps1000,
  dps500,
  dps250
} dps_set_t;
typedef enum int_def{
  none,
  INT1,
  INT2
}int_def_t;
enum interupt_lation{
  self_test_int=0x8000,
  FSYNC_int    =0x4000,
  PLL_int      =0x2000,
  Reset_int    =0x1000,
  FIFO_ths_int =0x0400,
  FIFO_full_int=0x0200,
  AGC_int      =0x0100,
  SMD_int      =0x0008,
  X_WOM_int    =0x0004,
  Y_WOM_int    =0x0002,
  Z_WOM_int    =0x0001,
  step_det_int =0x0800,
  step_cnt_int =0x0080,
  tilt_det_int =0x0040,
    ff_det_int =0x0020,
  lowG_det_int =0x0010
};

struct int16_3{
  int16_t x;
  int16_t y;
  int16_t z;
};struct return_IMU{
  int16_t temp;
  int16_3 accel;
  int16_3 gyro;
};struct float_3{
  float x;
  float y;
  float z;
};struct float_IMU{
  float temp;     //[°C]
  float_3 accel;  //[m/s²]
  float_3 gyro;   //[°/s]
};


hw_timer_t *timer = NULL;

void setup() {
  // put your setup code here, to run once:

}

void loop() {
  // put your main code here, to run repeatedly:
  
}

class IMU{
public:
  IMU(uint8_t addr){
    addr_imu=addr;
  }
  //config
    //apex (0x25-0x26)
    //WOM  (Ox27)
    //fifo (0x28-0x2A)
  //data
    //fifo (0x2F-0x30) lost pkt
    //apex (Ox31-0x34)
    //fifo (Ox3D-0x3E) count
    //fifo (0x3F)      data
    //who am i  (0x75)
    //mreg (0x79-0x7E)
  void sensors_config(ODR_set_t poll_rate, g_set_t max_g, dps_set_t max_dps){
    Wire.beginTransmission(addr_IMU);
    Wire.write(0x1F);
    Wire.write(0x0F);
    Wire.write((max_dps<<5)|poll_rate);
    Wire.write((max_g<<5)|poll_rate);
    Wire.endTransmission();
    switch(max_g){
      case g2: _max_G=2;break;
      case g4: _max_G=4;break;
      case g8: _max_G=8;break;
      case g16: _max_G=16;break;
    }
    switch(max_dps){
      case dps250: _max_dps=250;break;
      case dps500: _max_dps=500;break;
      case dps1000: _max_dps=1000;break;
      case dps2000: _max_dps=2000;break;
    }
  }
  //set de thermometer digital lop pas filter
  /*void temp_config(DLPF_t DLPF_config){ //0x00
    Wire.beginTransmission(addr_imu);
    Wire.write(0x22);
    Wire.write(DLPF_config<<4);
    Wire.endTransmission();
  }void accel_config0(g_set_t g_config,ODR_set_t accel_ODR){  //0x06
    switch (g_config){
      case g16:
        _max_G=16;
        break;
      case g8:
        _max_G=8;
        break;
      case g4:
        _max_G=4;
        break;
      case g2:
        _max_G=2;
        break;
    }
    Wire.beginTransmission(addr_imu);
    Wire.write(0x21);
    Wire.write((g_config<<5)|accel_ODR);
    Wire.endTransmission();
  }void accel_config1(avrege_accel_t avrege,LPF_t LPF_config){  //0x41
    Wire.beginTransmission(addr_imu);
    Wire.write(0x24);
    Wire.write((avrege<<4)|LPF_config);
    Wire.endTransmission();
  }void gyro_config0(dps_set_t dps_config,ODR_set_t gyro_ODR){  //0x06
    switch (dps_config){
      case dps2000:
        _max_dps=2000;
        break;
      case dps1000:
        _max_dps=1000;
        break;
      case dps500:
        _max_dps=500;
        break;
      case dps250:
        _max_dps=250;
        break;
    }
    Wire.beginTransmission(addr_imu);
    Wire.write(0x20);
    Wire.write((dps_config<<5)|gyro_ODR);
    Wire.endTransmission();
  }void gyro_config1(LPF_t LPF_config){ //0x31
    Wire.beginTransmission(addr_imu);
    Wire.write(0x23);
    Wire.write(LPF_config);
    Wire.endTransmission();
  }void set_power(bool LP_CLK_SEL,sens_mode_t gyro_mode,sens_mode_t accel_mode){  //0x00
    Wire.beginTransmission(addr_imu);
    Wire.write(0x1F);
    Wire.write((LP_CLK_SEL?0x80:0x00)|(gyro_mode<<4)|accel_mode);
    Wire.endTransmission();
  }

  uint8_t intf_gen(bool fifo_count_records,bool fifo_big_endian,bool sensor_big_endian,bool I3C_SDR,bool I3C_DDR,intf_CLK_SEL_t CLK){
    uint8_t data=0;
    if(fifo_count_records){
      data|=0x40;
    }if(fifo_big_endian){
      data|=0x20;
    }if(sensor_big_endian){
      data|=0x10;
    }if(I3C_SDR){
      data|=0x08;
    }if(I3C_DDR){
      data|=0x04;
    }
    data|=(CLK&0x3);
    return data;
  }void set_intf(uint8_t intf){
    Wire.beginTransmission(addr_imu);
    Wire.write(0x35);
    Wire.write(intf&0x70);
    Wire.write(intf&0x0F);
    Wire.endTransmission();
  }*/


  //maakt het makelijker om interupts te maken (return 0 als alles none is)
  uint32_t int_gen(int_def_t self_test,int_def_t fsync,int_def_t PLL,int_def_t Reset,int_def_t data_ready,int_def_t FIFO_ths,int_def_t FIFO_full,int_def_t AGC,int_def_t I3C,int_def_t SMD,int_def_t X_WOM,int_def_t Y_WOM,int_def_t Z_WOM){
    uint32_t data=0;
    //self test done: interupt
      if(self_test==1){
        data|=0x80000000;
      }else if (self_test==2){
        data|=0x00008000;
      }
    //FSYNC: interrupt
      if(fsync==1){
        data|=0x40000000;
      }else if (fsync==2){
        data|=0x00004000;
      }
    //PLL ready: intreupt
      if(PLL==1){
        data|=0x20000000;
      }else if (PLL==2){
        data|=0x00002000;
      }
    //reset done: interupt (default INT1)
      if(Reset==1){
        data|=0x10000000;
      }else if (Reset==2){
        data|=0x00001000;
      }
    //data ready: interrupt
      if(data_ready==1){
        data|=0x08000000;
      }else if (data_ready==2){
        data|=0x00000800;
      }
    //FIFO threshold ready: intreupt
      if(FIFO_ths==1){
        data|=0x04000000;
      }else if (FIFO_ths==2){
        data|=0x00004000;
      }
    //FIFO full ready: intreupt
      if(FIFO_ths==1){
        data|=0x02000000;
      }else if (FIFO_ths==2){
        data|=0x00002000;
      }
    //UI AGC ready: interupt
      if(AGC==1){
        data|=0x01000000;
      }else if (AGC==2){
        data|=0x00000100;
      }
    //I3C protocol error: interrupt
      if(I3C==1){
        data|=0x00400000;
      }else if (I3C==2){
        data|=0x00000040;
      }
    //SMD: interupt
      if(SMD==1){
        data|=0x00080000;
      }else if (SMD==2){
        data|=0x00000008;
      }
    //WOM X as: interupt
      if(X_WOM==1){
        data|=0x00010000;
      }else if (X_WOM==2){
        data|=0x00000001;
      }
    //WOM Y as: interupt
      if(Y_WOM==1){
        data|=0x00020000;
      }else if (Y_WOM==2){
        data|=0x00000002;
      }
    //WOM Z as: interupt
      if(Z_WOM==1){
        data|=0x00040000;
      }else if (Z_WOM==2){
        data|=0x00000004;
      }
    return data;
  }void set_int(uint32_t interupt){
    Wire.beginTransmission(addr_imu);
    Wire.write(0x2B);
    Wire.write((interupt>>24)&0xFF);
    Wire.write((interupt>>16)&0xFF);
    Wire.write((interupt>> 8)&0xFF);
    Wire.write((interupt>> 0)&0xFF);
    Wire.endTransmission();
  }
  //set de bit van de interuptbron
  uint16_t get_int(){
    uint8_t data[4];
    Wire.beginTransmission(addr_imu);
    Wire.write(0x39);
    Wire.endTransmission(false);
    Wire.requestFrom(addr_imu, 4, true);
    for(int i=0;i<4;i++){
      data[i]=Wire.read();
    }
    uint16_t int_return=(data[1]<<8)|data[2];
    if(data[0]==0x00){
      return 0;
    }
    if (data[3]&0x20!=0){
      int_return|=step_det_int;
    }
    int_return|=(data[3]&0x1E)<<3; //krijg de laatste 4 interupts (effisient)
    return int_return;
  }

  float_IMU convert_data(return_IMU raw){
    float_IMU data;
    data.temp=((float)raw.temp/128.0)+25.0;
    data.accel.x=(float)raw.accel.x*_max_G/pow(2,31);
    data.accel.y=(float)raw.accel.y*_max_G/pow(2,31);
    data.accel.z=(float)raw.accel.z*_max_G/pow(2,31);
    data.gyro.x=(float)raw.gyro.x*_max_dps/pow(2,31);
    data.gyro.y=(float)raw.gyro.y*_max_dps/pow(2,31);
    data.gyro.z=(float)raw.gyro.z*_max_dps/pow(2,31);
    return data;
  }return_IMU get_data(){
    return_IMU value;
    uint8_t get[14],i=0;
    Wire.beginTransmission(addr_IMU);
    Wire.write(0x09);
    Wire.endTransmission(false);
    Wire.requestFrom(addr_IMU, 14, true);
    if (14==Wire.available()){  //data corect gekregen
      while(Wire.available()) {
        get[i] = Wire.read();
        i++;
      }
      value.temp=get[0]<<8|get[1];
      value.accel.x=get[2]<<8|get[3 ];
      value.accel.y=get[4]<<8|get[5 ];
      value.accel.z=get[6]<<8|get[7 ];
      value.gyro.x=get[8 ]<<8|get[9 ];
      value.gyro.y=get[10]<<8|get[11];
      value.gyro.z=get[12]<<8|get[13];
    }else{
      value.temp=0;
      value.accel.x=0;
      value.accel.y=0;
      value.accel.z=0;
      value.gyro.x=0;
      value.gyro.y=0;
      value.gyro.z=0;
      while(Wire.available()) Wire.read();  //clear the read buffer
    }
    return value;
  }
protected:
  uint8_t addr_imu;
  int _max_G=2;     //[m²/s]
  int _max_dps=250; //[ °/s]
};

class IMU_position: private IMU {
public:
  IMU_position(uint8_t addr):IMU(addr){
    init_IMU();
    timer = timerBegin(1000000);                    //timer 1Mhz resolution
    timerAttachInterrupt(timer, &IMU_position::update_location);  //attach callback
    timerAlarm(timer, poll_rate, true, 0);            //set time in us (1Hz)
  }
  //[°/s]
  float_3 get_dps_raw(){
    return dps_raw;
  }
  //[°/s]
  float_3 get_dps(){
    return dps;
  }
  //[°]
  float_3 get_hoek(){
    return hoek;
  }
  //[m/s²]
  float_3 get_versnelling_raw(){
    return versnelling_raw;
  }
  //[m/s²]
  float_3 get_versnelling(){
    return versnelling;
  }
  //[m/s]
  float_3 get_snelhijd(){
    return snelhijd;
  }
  //[m]
  float_3 get_posietie(){
    return posietie;
  }
private:
  static float_3 dps_raw;
  static float_3 dps;
  static float_3 hoek;
  static float_3 versnelling_raw;
  static float_3 versnelling;
  static float_3 snelhijd;
  static float_3 posietie;
  static float temp;
  uint64_t poll_rate=1000000;
  void init_IMU(){
    Wire.beginTransmission(addr_imu);
    Wire.write(0x1F); //ga naar het begin adderes voor alle comando's
    Wire.write(0x0F); //alles aanleggen
    Wire.write(0x45); //±500 dps, ODR:1.6kHz
    _max_dps=500;
    Wire.write(0x45); //±4 g, ODR:1.6kHz
    _max_G=4;
    Wire.endTransmission();
    set_int(0);       //leg alle interupts af
  }
  static void ARDUINO_ISR_ATTR update_location(){
    return_IMU raw_data = get_data();
    float_IMU new_data = convert_data(raw_data);
    temp=new_data.temp;
    //updata dps en versnelling door de sensor
    dps_raw=new_data.gyro;
    versnelling_raw=new_data.accel;
    //zet de dps_raw en versnelling_raw om in het vaste referentiefraam
      //https://www.w3schools.com/c/c_ref_math.php
      //https://en.wikipedia.org/wiki/Rotation_matrix#General_3D_rotations
    float_3 cos_hoek,sin_hoek;
    cos_hoek.x=cos(hoek.x); sin_hoek.x=sin(hoek.x);
    cos_hoek.y=cos(hoek.y); sin_hoek.y=sin(hoek.y);
    cos_hoek.z=cos(hoek.z); sin_hoek.z=sin(hoek.z);
    //rotatiematix op versnelling
    versnelling.x=cos_hoek.y*cos_hoek.z*versnelling_raw.x+(sin_hoek.x*sin_hoek.y*cos_hoek.z-cos_hoek.x*sin_hoek.z)*versnelling_raw.y+(cos_hoek.x*sin_hoek.y*cos_hoek.z+sin_hoek.x*sin_hoek.z)*versnelling_raw.z;
    versnelling.y=cos_hoek.y*sin_hoek.z*versnelling_raw.x+(sin_hoek.x*sin_hoek.y*sin_hoek.z-cos_hoek.x*cos_hoek.z)*versnelling_raw.y+(cos_hoek.x*sin_hoek.y*sin_hoek.z-sin_hoek.x*sin_hoek.z)*versnelling_raw.z;
    versnelling.z=-sin_hoek.y*versnelling_raw.x+sin_hoek.x*cos_hoek.y*versnelling_raw.y+cos_hoek.x*cos_hoek.y*versnelling_raw.z;
    //rotatiematix op dps[°/s]
    dps.x=cos_hoek.y*cos_hoek.z*dps_raw.x+(sin_hoek.x*sin_hoek.y*cos_hoek.z-cos_hoek.x*sin_hoek.z)*dps_raw.y+(cos_hoek.x*sin_hoek.y*cos_hoek.z+sin_hoek.x*sin_hoek.z)*dps_raw.z;
    dps.y=cos_hoek.y*sin_hoek.z*dps_raw.x+(sin_hoek.x*sin_hoek.y*sin_hoek.z-cos_hoek.x*cos_hoek.z)*dps_raw.y+(cos_hoek.x*sin_hoek.y*sin_hoek.z-sin_hoek.x*sin_hoek.z)*dps_raw.z;
    dps.z=-sin_hoek.y*dps_raw.x+sin_hoek.x*cos_hoek.y*dps_raw.y+cos_hoek.x*cos_hoek.y*dps_raw.z;
    //interpelaat de snelhijd, positie en hoek
    snelhijd.x+=versnelling.x*1000000/poll_rate;  //dit werkt omdat we dit 1 keer per seconde doen en we een het op een vast referentiefraam gebruiken (het begin)
    snelhijd.y+=versnelling.y*1000000/poll_rate;  //dit werkt omdat we dit 1 keer per seconde doen en we een het op een vast referentiefraam gebruiken (het begin)
    snelhijd.z+=versnelling.z*1000000/poll_rate;  //dit werkt omdat we dit 1 keer per seconde doen en we een het op een vast referentiefraam gebruiken (het begin)
    posietie.x+=snelhijd.x*1000000/poll_rate;     //dit werkt omdat we dit 1 keer per seconde doen en we een het op een vast referentiefraam gebruiken (het begin)
    posietie.y+=snelhijd.y*1000000/poll_rate;     //dit werkt omdat we dit 1 keer per seconde doen en we een het op een vast referentiefraam gebruiken (het begin)
    posietie.z+=snelhijd.z*1000000/poll_rate;     //dit werkt omdat we dit 1 keer per seconde doen en we een het op een vast referentiefraam gebruiken (het begin)
    hoek.x+=dps.x*1000000/poll_rate;              //dit werkt omdat we dit 1 keer per seconde doen en we een het op een vast referentiefraam gebruiken (het begin)
    hoek.y+=dps.y*1000000/poll_rate;              //dit werkt omdat we dit 1 keer per seconde doen en we een het op een vast referentiefraam gebruiken (het begin)
    hoek.z+=dps.z*1000000/poll_rate;              //dit werkt omdat we dit 1 keer per seconde doen en we een het op een vast referentiefraam gebruiken (het begin)
  }
};

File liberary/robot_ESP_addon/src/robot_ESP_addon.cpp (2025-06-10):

#include "robot_ESP_addon.h"
#include "LCD.h"
#include "motor.h"
#include "servo.h"
#include <arduino.h>
#include <Wire.h>
#ifdef _SSID
#include <WiFi.h>
#include <ESPmDNS.h>
#include <NetworkUdp.h>
#include <ArduinoOTA.h>
#endif

#if not(Serial==HWCDCSerial)
#error "zet USB CDC on boot aan (tools->USB CDC on boot->enabel)"
#endif

void robot_begin(uint8_t servo_mode, bool LCD_backlight, bool motor_turn,bool IMU,bool machnetometer,bool lijnsensor){
    Wire.begin(10,11);
    Serial.begin();

    //ESPOTA
#ifdef _SSID
    WiFi.mode(WIFI_STA);
#ifdef _PASSWOORD
    WiFi.begin(_SSID, _PASSWOORD);
    Serial.println(_SSID);
    Serial.println(_PASSWOORD);
#else
    WiFi.begin(_SSID);
    Serial.println(_SSID);
#endif
    ArduinoOTA
        .onStart([]() {
        String type;
        if (ArduinoOTA.getCommand() == U_FLASH) {
            type = "sketch";
        } else {  // U_SPIFFS
            type = "filesystem";
        }

        // NOTE: if updating SPIFFS this would be the place to unmount SPIFFS using SPIFFS.end()
        Serial.println("Start updating " + type);
        })
        .onEnd([]() {
        Serial.println("\nEnd");
        })
        .onProgress([](unsigned int progress, unsigned int total) {
        Serial.printf("Progress: %u%%\r", (progress / (total / 100)));
        })
        .onError([](ota_error_t error) {
        Serial.printf("Error[%u]: ", error);
        if (error == OTA_AUTH_ERROR) {
            Serial.println("Auth Failed");
        } else if (error == OTA_BEGIN_ERROR) {
            Serial.println("Begin Failed");
        } else if (error == OTA_CONNECT_ERROR) {
            Serial.println("Connect Failed");
        } else if (error == OTA_RECEIVE_ERROR) {
            Serial.println("Receive Failed");
        } else if (error == OTA_END_ERROR) {
            Serial.println("End Failed");
        }
    });

  ArduinoOTA.begin();
#endif
    //LCD
    backlight(LCD_backlight);
    clear_screen();
    //servo's
    init_servo(servo_mode);
    //motoren
    reset_encoders();
    set_mode(motor_turn?1:3);
    //machnetometer
    start_burst_mode();
    //IMU
    sensors_config_IMU(Hz100,g2,dps250);
    //lijnsensor
    for(uint8_t i;i<8;i++){
        set_sensor(sensors[i]);
        ENABLE(true,false,true);
        set_config20(false,3);
        set_ADC_gain(12);
    }
}

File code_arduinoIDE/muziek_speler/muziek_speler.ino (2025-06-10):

#define settings 0
#define playback_commands 1
#define file_commands 2

#define EOL_CR 0
#define EOL_LF 1
#define EOL_CRLF 2

#define mode_read 0
#define mode_write 1
#define mode_read_write_end 2
#define mode_read_write_begin 3

#define promt_char '\r'

//ont comentaar als arduino mega
//#define Serial_muziek Serial1
#ifndef Serial_muziek
#define Serial_muziek Serial0
#endif

#define Dev_mode

const uint32_t temp[]={9600,19200,38400,57600,115200,2400,4800,230400,460800};
//structs
  struct play_back_info {
    uint8_t error=0;  //enkel as er een error is gebeurt
    uint16_t position;
    uint8_t samplerate;
    uint16_t bitrate;
    char channels;
  };
  struct play_back_status{
    uint8_t error=0;  //enkel as er een error is gebeurt
    uint16_t tijd;
    uint8_t aantal_keer;
    char status;  //P: speelt,S: gestopt,D: gepouzeert
  };
  struct versie {
    uint8_t main_versie;
    uint8_t sub_versie;
    bool beta;
    uint8_t beta_vesie;
    char model[5];
  };
  struct free_handeler{
    uint8_t error=0;
    uint8_t posietie=0;
  };
  struct file_info{
    uint8_t error=0;
    uint32_t huidige_positie=0;
    uint32_t grote=0;
  };
  struct char_return{
    uint8_t error=0;
    uint8_t data;
  };

void setup() {
  delay(500);
  Serial.begin(115200);
  for (uint8_t i=0;i<=8;i++){
    Serial.print(temp[i]);
    Serial_muziek.begin(temp[i]);
    Serial.print('\t');
    Serial.println(_set_bitrate(4),HEX);
    Serial_muziek.end();
    delay(1000);
  }
  uint32_t bit_rate=temp[3];
  Serial.println(bit_rate);
  Serial_muziek.begin(bit_rate);
  Serial_muziek.write('\r');
  Serial_muziek.write('V');
  Serial_muziek.write('\r');
}

void loop() {
  if (_available()){
    Serial.print(Serial_muziek.read());
  }
  if (Serial.available()>0){
    _write_char(Serial.read());
  }
}

void sincronize_transmission(){
  _write_char('\r');
  char c=0;
  while (_available()&&c=='>') {
    c=_read_char();
  };
}
//instellingen
  uint8_t set_EOL_as(uint8_t mode){
    char data[2]={0,0};
    switch (mode){
      case EOL_CR:
        data[0]='0';
        break;
      case EOL_LF:
        data[0]='1';
        break;
      case EOL_CRLF:
        data[0]='2';
        break;
      default:
        return 6; //command formating error
    }
    _send_command('E',data,settings);
    return _get_return_error();
  }
  #ifdef Dev_mode
  #warning "you are now in dev mode and you have now acses to functions that make it unuzeble"
  uint8_t set_write_timeout(uint8_t tijd){
    if (tijd!=255){
      char data[4];
      sprintf(data,"%dn",tijd);
      _send_command('T',data,settings);
      return _get_return_error();
    }else{
      return 6; //command formating error
    }
  }
  uint8_t set_response_delay(uint8_t tijd){
    if (tijd!=255){
      char data[4];
      sprintf(data,"%dn",tijd);
      _send_command('R',data,settings);
      return _get_return_error();
    }else{
      return 6; //command formating error
    }
  }
  uint8_t set_list_mode(bool grote){
    if (grote){
      _send_command('L',"0",settings);
    }else{
      _send_command('L',"1",settings);
    }
    return _get_return_error();
  }
  uint8_t _set_bitrate(uint8_t waarde){
    if (waarde<8){
      char data[2]={waarde+'0','\n'};
      _send_command('D',data,settings);
      //return _get_return_error();
    }else{
      return 6; //command formating error
    }
  }
  uint8_t _set_hardware_bussy(bool actief){  //kan niet worden gebruikt niet geconecteerd
    _send_command('H',(actief?"0":"1"),settings);
    return _get_return_error();
  }
  uint8_t _input_style(uint8_t mode){
    if (mode<3){
      char data[2]={mode+'0','\n'};
      _send_command('S',data,settings);
      return _get_return_error();
    }else{
      return 6; //command formating error
    }
  }
  uint8_t _set_prompt_char(char karakter){
    char data[4];
    sprintf(data,"%dn",karakter);
    _send_command('D',data,settings);
    return _get_return_error();
  }
  #endif
//speel commando's
  uint8_t play_file(char* path){
    _send_command('F',path,playback_commands);
    return _get_return_error();
  }
  uint8_t set_volume(uint8_t links,uint8_t rechts){
    if (links!=255 & rechts!=255){
      if (links==rechts){
        char data[4];
        sprintf(data,"%d\n",links);
        _send_command('V',data,playback_commands);
        return _get_return_error();
      }else{
        char commando[8];
        sprintf(commando,"%d %d\n",links,rechts);
        _send_command('V',commando,playback_commands);
        return _get_return_error();
      }
    }else{
      return 6; //command formating error
    }
  }
  uint8_t herhaal(uint8_t aantal_keer){ //0 is een oneindig aantal keer
    char data[4];
    sprintf(data,"%d\n",aantal_keer);
    _send_command('O',data,playback_commands);
    return _get_return_error();
  }
  uint8_t jump(uint16_t tijd){
    char data[6];
    sprintf(data,"%d\n",tijd);
    _send_command('J',data,playback_commands);
    return _get_return_error();
  }
  uint8_t speed(uint8_t persentage){
    if (persentage<=250&persentage>=90){
      char commando[4];
      sprintf(commando,"%d\n",persentage);
      _send_command('X',commando,playback_commands);
      return _get_return_error();
    }
    return 6; //command formating error
  }
  uint8_t play_tone(uint8_t base_frequency_index,uint8_t multiply){
    //tone_frequency=base_frequency_index*d
    //base_frequency_index=0: 334,53125
    //base_frequency_index=1: 375
    //base_frequency_index=2: 250
    //base_frequency_index=3: 172,265625
    //base_frequency_index=4: 187,5
    //base_frequency_index=5: 125
    //base_frequency_index=6: 86,328125
    //base_frequency_index=7: 93,75
    if (base_frequency_index<=8){
      if (multiply<=31){
        char data[4];
        sprintf(data,"%d\n",((base_frequency_index<<5)+multiply));
        _send_command('T',data,playback_commands);
        return _get_return_error();
      }
    }
    return 4;
  }
  uint8_t boost(int8_t treble_amplitude,uint8_t treble_frequency,int8_t bass_amplitude,uint8_t bass_frequency){
    if (treble_amplitude>=-8&&treble_amplitude<=7){
      if (treble_frequency<=15){
        if (bass_amplitude>=-8&&bass_amplitude<=7){
          if (bass_frequency<=15){
            uint16_t boost_o=(treble_amplitude&0xf)<<12|(treble_frequency&0xf)<<8|(bass_amplitude&0xf)<<4|(bass_frequency&0xf);
            char data[6];
            sprintf(data,"%d\n",boost);
            _send_command('B',data,playback_commands);
            return _get_return_error();
          }
        }
      }
    }
    return 6; //command formating error
  }
  uint8_t pouse(){
    _send_command('P',"\n",playback_commands);
    return _get_return_error();
  }
  uint8_t stop(){
    _send_command('S','\n',playback_commands);
    return _get_return_error();
  }
  uint8_t reset_audio(){
    _send_command('R','\n',playback_commands);
    return _get_return_error();
  }
  play_back_info get_play_back_info(){
    sincronize_transmission();  //sincronizeer de bus
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

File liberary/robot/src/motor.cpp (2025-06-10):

#include <Wire.h>
#include <Arduino.h>
#include "motor.h"

#define driver_ADDR 0x58

//https://www.robot-electronics.co.uk/htm/md25i2c.htm
// get data
  int32_t get_encoder1(){
    return get_4byte_command(0x2);
  }int32_t get_encoder2(){
    return get_4byte_command(0x6);
  }
  uint8_t get_snelheid1(){
    return get_1byte_command(0x0);
  }uint8_t get_snelheid2(){
    return get_1byte_command(0x1);
  }uint8_t get_volt(){
    return get_1byte_command(0xA);
  }uint8_t get_stroom1(){
    return get_1byte_command(0xB);
  }uint8_t get_stroom2(){
    return get_1byte_command(0xC);
  }uint8_t get_versnelling(){
    return get_1byte_command(0xE);
  }uint8_t get_mode(){
    return get_1byte_command(0xF);
  }

  int32_t get_4byte_command(uint8_t command){
    int32_t data=0;
    Wire.beginTransmission(driver_ADDR);
    Wire.write(command);
    Wire.endTransmission(false);
    Wire.requestFrom(driver_ADDR,4,true);
    while(Wire.available()){
      data=(data<<8)+Wire.read();
    }
    return data;
  }
  uint8_t get_1byte_command(uint8_t command){
    uint8_t data;
    Wire.beginTransmission(driver_ADDR);
    Wire.write(command);
    Wire.endTransmission(false);
    Wire.requestFrom(driver_ADDR,1,true);
    while(Wire.available()) {
      data=Wire.read();
    }
    return data;
  }
//sent commando's
  void set_acceleration(uint8_t versnelling){
    Wire.beginTransmission(driver_ADDR);
    Wire.write(14);
    Wire.write(versnelling);
    Wire.endTransmission();
  }
  void set_mode(uint8_t mode){
    Wire.beginTransmission(driver_ADDR);
    Wire.write(15);
    Wire.write(mode);
    Wire.endTransmission();
  }
  void set_regulator(bool set_to){
    Wire.beginTransmission(driver_ADDR);
    Wire.write(16);
    if (set_to){
      Wire.write(0x31);
    }else{
      Wire.write(0x30);
    }
    Wire.endTransmission();
  }
  void set_time_out(bool set_to){
    Wire.beginTransmission(driver_ADDR);
    Wire.write(16);
    if (set_to){
      Wire.write(0x33);
    }else{
      Wire.write(0x32);
    }
    Wire.endTransmission();
  }
  void reset_encoders(){
    Wire.beginTransmission(driver_ADDR);
    Wire.write(16);
    Wire.write(0x20);
    Wire.endTransmission();
  }
  void set_snelheid1(int8_t snelheid){
    Wire.beginTransmission(driver_ADDR);
    Wire.write(0);
    Wire.write(snelheid);
    Wire.endTransmission();
  }
  void set_snelheid2(int8_t snelheid){
    Wire.beginTransmission(driver_ADDR);
    Wire.write(1);
    Wire.write(snelheid);
    Wire.endTransmission();
  }

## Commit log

2025-03-07 voeg de al gemaakte bestanden toe
    [ESP32 adon V2.kicad_pcb, ESP32 adon V2.kicad_sch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]
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2025-03-08 voeg de berekeningen toe voor de VIA's
    [VIA's locatie's ESP32 adon V2.xlsx]
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2025-03-08 bug uit code gehaald waardoor het niet update
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2025-03-11 voeg de exel voor de taak 50% toe
    [50%.xlsx]
2025-03-11 bijna alle vragen van de taak 50% zijn ingevuld
    [50%.xlsx]
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2025-03-17 schema geupdate voor ATtiny 202 (nog niet af)
    [hoofd nieuw.kicad_sch]
2025-03-17 schema bijna klaar allen nog SRF02 toevoegen
    [hoofd nieuw.kicad_sch]
2025-03-18 wek '50%' voledig af
    [50%.xlsx]
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2025-03-18 veranert de ATtiny202 naat ATtiny402 om genoeg opslag te hebben
    [hoofd nieuw.kicad_sch]
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2025-03-18 voeg de lichtsensor toe aan het hoofd
    [hoofd nieuw.kicad_sch]
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2025-03-20 teken de outline van het hoofd, en plaats de SRF02 (locatie gevoelig)
    [hoofd nieuw.kicad_pcb, hoofd nieuw.kicad_sch]
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2025-03-21 plaats de componenten grofweg
    [hoofd nieuw.kicad_pcb, hoofd nieuw.kicad_sch]
2025-03-21 voeg de ontbrekende foodprints toe
    [hoofd nieuw.kicad_pcb, hoofd nieuw.kicad_sch]
2025-03-21 teken alles waarvan ik de locate ken of niet belangrijk is (absolut)
    [hoofd nieuw.kicad_pcb]
2025-03-21 led van het 'mondje' zijn geplaatst
    [hoofd nieuw.kicad_pcb, hoofd nieuw.kicad_sch]
2025-03-21 de locatie van alle componenten is bepaald in het hoofd
    [hoofd nieuw.kicad_pcb, hoofd nieuw.kicad_sch]
2025-03-22 nieuw hoofd is klaar
    [hoofd nieuw.kicad_pcb, lijnsensor.kicad_pcb, lijnsensor.kicad_sch]
2025-03-22 ESD bescherming voor de lijnsensor
    [lijnsensor.kicad_pcb, lijnsensor.kicad_sch]
2025-03-23 de routing is klaar van de lijnsensor nog allen opschonen
    [lijnsensor.kicad_pcb, lijnsensor.kicad_sch]
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2025-03-23 voeg de gaten toe om te kunnen vastvijzen
    [lijnsensor.kicad_pcb]
2025-03-23 maak de gbr file's voor nieuw hoofd
    [hoofd nieuw.kicad_pcb, hoofd nieuw.kicad_sch]
2025-03-23 maak de gbr file's voor lijnsensor
    [lijnsensor.kicad_pcb]
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2025-04-22 dupliceer de huidige bestanden en voeg de pullup weerstand toe
    [ESP32 adon V3.kicad_pcb, ESP32 adon V3.kicad_sch, hoofd nieuw V2.kicad_pcb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]
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2025-04-22 teken al een deel van de lijnsensor
    [lijnsensor V2.kicad_pcb]
2025-04-24 begin al met het tekenen van ESP32 addon V3
    [ESP32 adon V3.kicad_pcb, ESP32 adon V3.kicad_sch]
2025-04-24 verder tekenen en datasheets controleren
    [ESP32 adon V3.kicad_pcb, ESP32 adon V3.kicad_sch]
2025-04-26 voeg de imu en de 3.3V I²C conectoren toe
    [ESP32 adon V3.kicad_pcb]
2025-04-26 zet alle componenten op de juist plaats en alles is al verbonden
    [ESP32 adon V3.kicad_pcb]
2025-04-26 heatsikn voor de ESP32 maken
    [ESP32 adon V3.kicad_pcb]
2025-04-26 voeg het exel document toe waar de via's moeten komen
    [VIA's locatie's ESP32 adon V3.xlsx]
2025-04-27 controller ESP32 addon V3
    [ESP32 adon V3.kicad_pcb]
2025-04-28 maak een pdf om aftedrukken om te weten als alles goed is
    [ESP32 adon V3.kicad_pcb]
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2025-04-28 updata alle afmetingen en maak er een pdf van
    [lijnsensor V2.kicad_pcb]
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2025-04-29 zet de leds en lichtsensoren op de juisteplaats nieuw hoofd V2
    [hoofd nieuw V2.kicad_pcb]
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2025-05-01 voeg mijn naam toe aan nieuw hoofd en lijnsensor
    [hoofd nieuw V2.kicad_pcb, lijnsensor V2.kicad_pcb]
2025-05-02 update de .gitignore en voeg viea's toe aan ESP32 addon V3
    [ESP32 adon V3.kicad_pcb]
2025-05-02 verander het I²C adders van de I²C multiplexer om conflict te vermijden
    [lijnsensor V2.kicad_pcb, lijnsensor V2.kicad_sch]
2025-05-02 maak een versie van de lijnsensor die alle pinnen van de lichtsenser gebruikt
    [lijnsensor V2 met IO_expander.kicad_pcb, lijnsensor V2 met IO_expander.kicad_sch]
2025-05-04 begin al met het toevoegen van de io extender nog niet klaar
    [lijnsensor V2 met IO_expander.kicad_pcb, lijnsensor V2 met IO_expander.kicad_sch]
2025-05-05 pas de maten aan van de addon V3 en de lijnsensor(nog niet klaar)
    [ESP32 adon V3.kicad_pcb, lijnsensor V2.kicad_pcb, lijnsensor V2.kicad_sch]
2025-05-05 voeg 75%.xlsx toe en vul het al gedeeltelijk in
    [75%.xlsx]
2025-05-05 de linker kant is al klaar nu nog de rechter kant van lijnsensor V2 met IO_expander
    [lijnsensor V2 met IO_expander.kicad_pcb]
2025-05-05 al begonnen aan de rechterkand van lijnsensor V2 met IO_expander
    [lijnsensor V2 met IO_expander.kicad_pcb]
2025-05-05 klaar met het tekenen van alle verbindingen en veel via's geplaatst
    [lijnsensor V2 met IO_expander.kicad_pcb]
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2025-05-07 maak nieuw hoofd maar met een andere sensorn want de originele is niet meer beschikbaar in kleine hoeveeldheden
    [hoofd nieuw V3-B_Cu.gbr, hoofd nieuw V3-B_Mask.gbr, hoofd nieuw V3-B_Paste.gbr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]
2025-05-08 voeg nog ESD bescherming toe aan nieuw hoofd V3
    [hoofd nieuw V3.kicad_pcb, hoofd nieuw V3.kicad_sch]
2025-05-09 zorg dat de .gbr files van nieuw hoofd V3 juist zijn
    [ESP32 adon V3.kicad_sch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]
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2025-05-13 verwijder de oude bestanden van ESP32 adon V4
    [ESP32 adon V4-B_Cu.gbr, ESP32 adon V4-B_Mask.gbr, ESP32 adon V4-B_Paste.gbr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]
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
